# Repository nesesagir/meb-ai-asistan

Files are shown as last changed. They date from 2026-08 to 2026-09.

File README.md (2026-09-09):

# MEB AI Asistan

End-to-end voice assistant prototype for education content: ESP32 client, FastAPI backend with RAG, a completed 50×72 mm PCB design, a 3D-printed enclosure, and a small web dashboard.

## Architecture

```
ESP32 (mic / speaker / UI)
        │ WebSocket
        ▼
FastAPI  →  STT → RAG (Qdrant) → LLM → TTS
        │
        ▼
Web dashboard (parent / teacher)
```

| Path | Role |
|---|---|
| `01-Cihaz-Yazilimi/` | ESP32 firmware |
| `02-Backend-Sunucu/` | API, voice pipeline, dashboard host |
| `03-Veri-RAG/dokumantasyon/` | How book data is prepared |
| `04-Dashboard-Web/` | Dashboard UI |
| `05-Donanim-PCB/` | 50×72 mm PCB (schematic and layout complete) |
| `06-Kasa-3D/` | Print-ready case (STL) and Blender source |

Large book/vector dumps are not in this repo; rebuild them locally when needed.

There is no hosted demo. Run the backend locally and flash the ESP32 to try the assistant.

## On the device

ESP32 client on hardware (prototype photos):

| Ready | Type a question | Grade |
| --- | --- | --- |
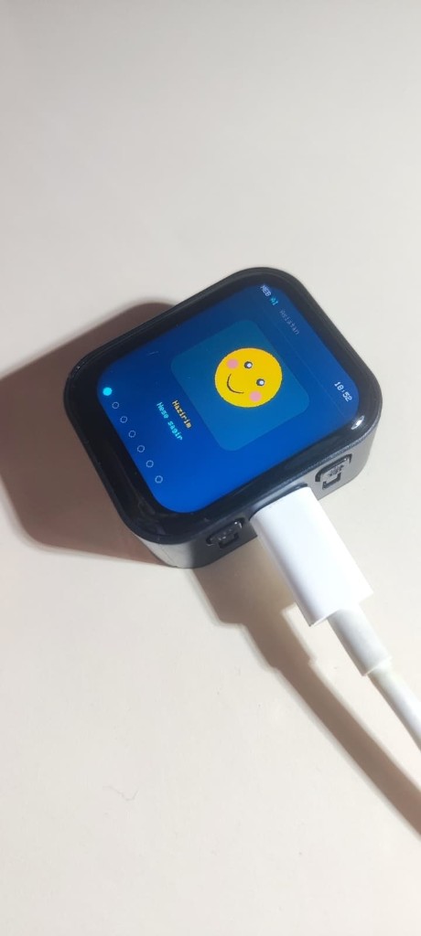
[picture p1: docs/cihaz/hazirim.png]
Hazırım
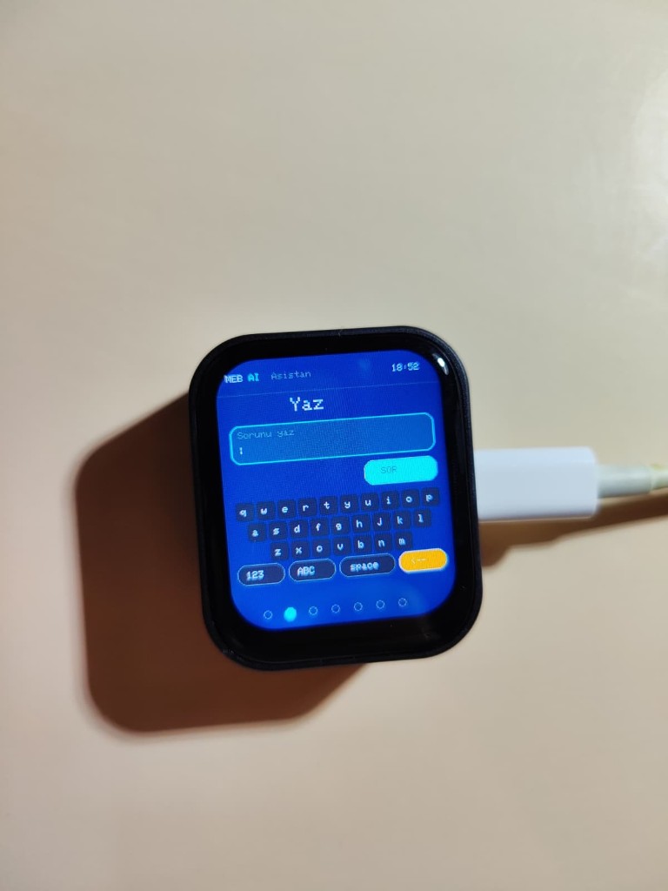
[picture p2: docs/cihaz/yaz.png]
Yaz
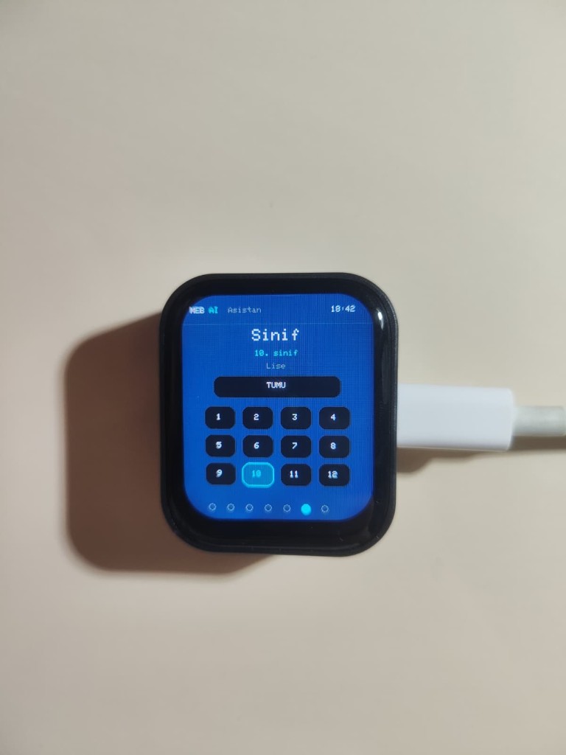
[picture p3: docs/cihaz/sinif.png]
Sınıf
|  |  |  |

## Setup

### Backend

1. Copy `02-Backend-Sunucu/.env.example` → `.env` and set `GROQ_API_KEY`
2. Start Qdrant on `localhost:6333`
3. Create a venv, install `requirements.txt`
4. Run:

```bash
uvicorn main:app --host 0.0.0.0 --port 8001
```

Dashboard: `http://127.0.0.1:8001/dashboard/`

### Device

1. Copy `01-Cihaz-Yazilimi/esp32-asistan/wifi_local.h.example` → `wifi_local.h`
2. Fill Wi-Fi SSID/password and backend host IP
3. Flash `esp32-asistan` with Arduino IDE

`wifi_local.h` and `.env` are gitignored.

## Hardware

Custom 50×72 mm board: schematic, layout, and Gerber are complete.

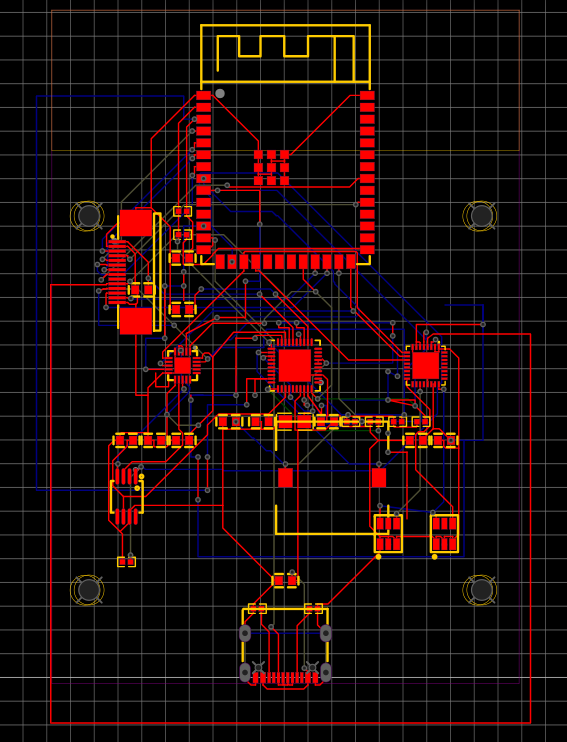
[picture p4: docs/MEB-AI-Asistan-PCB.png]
PCB layout


- PCB **50 × 72 × 1.6 mm**, 4 layers, Type-C on the bottom edge (center)
- ESP32-S3-WROOM-1 on the **top / screen** side; antenna keep-out is the top 15 mm
- M2 holes Ø2.2 mm at (4,10) (46,10) (4,50) (46,50) from the Type-C bottom-left origin
- Case target **58 × 90 × 20 mm**; battery **35 × 34 × 6.5 mm** on the back, between the four bosses
- Mechanical check file: `05-Donanim-PCB/easyeda/MEB-AI-Asistan-PCB-mekanik.scad`
- Schematic sheets: `05-Donanim-PCB/easyeda/01-*.json` … `09-PCB-TAM.json` (open in EasyEDA Standard)
- Gerber: `05-Donanim-PCB/Uretim.zip`
- Case (print-ready): `06-Kasa-3D/on_govde.stl`, `06-Kasa-3D/arka_kapak.stl`
- Case source: `06-Kasa-3D/final.blend`
- Case envelope: `06-Kasa-3D/kasa.scad`

## Stack

Python · FastAPI · Qdrant · Groq · Edge TTS · ESP32 · EasyEDA · OpenSCAD · Blender · JavaScript

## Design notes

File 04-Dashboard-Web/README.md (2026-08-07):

# Dashboard

Served by the backend at `/dashboard/`.

Demo logins (local only):

- `veli` / `veli1`
- `ogretmen` / `ogretmen1`

The device talks to the backend over WebSocket; the panel reads status and history through the HTTP API.

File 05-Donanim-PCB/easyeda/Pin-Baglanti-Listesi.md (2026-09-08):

# Pin Baglanti Listesi

Bu liste sema cizimi icin net bazli resmi baglanti referansidir.

## Net Bazli Baglantilar

### 3V3
| Bilesen | Pin | Bu nette bagli diger pinler |
|---|---|---|
| C5 | 1 | L1.2, R1.2, R2.2, R6.2, R7.2, R8.2, U1.2, U2.14, U2.21 |
| L1 | 2 | C5.1, R1.2, R2.2, R6.2, R7.2, R8.2, U1.2, U2.14, U2.21 |
| R1 | 2 | C5.1, L1.2, R2.2, R6.2, R7.2, R8.2, U1.2, U2.14, U2.21 |
| R2 | 2 | C5.1, L1.2, R1.2, R6.2, R7.2, R8.2, U1.2, U2.14, U2.21 |
| R6 | 2 | C5.1, L1.2, R1.2, R2.2, R7.2, R8.2, U1.2, U2.14, U2.21 |
| R7 | 2 | C5.1, L1.2, R1.2, R2.2, R6.2, R8.2, U1.2, U2.14, U2.21 |
| R8 | 2 | C5.1, L1.2, R1.2, R2.2, R6.2, R7.2, U1.2, U2.14, U2.21 |
| U1 | 2 | C5.1, L1.2, R1.2, R2.2, R6.2, R7.2, R8.2, U2.14, U2.21 |
| U2 | 14 | C5.1, L1.2, R1.2, R2.2, R6.2, R7.2, R8.2, U1.2, U2.21 |
| U2 | 21 | C5.1, L1.2, R1.2, R2.2, R6.2, R7.2, R8.2, U1.2, U2.14 |

### AEC_N
| Bilesen | Pin | Bu nette bagli diger pinler |
|---|---|---|
| U3 | 32 | - |

### AEC_P
| Bilesen | Pin | Bu nette bagli diger pinler |
|---|---|---|
| U3 | 31 | - |

### AUD_3V3
| Bilesen | Pin | Bu nette bagli diger pinler |
|---|---|---|
| C7 | 1 | C12.1, U2.18, U4.11, U4.20, U4.3, U4.4 |
| C12 | 1 | C7.1, U2.18, U4.11, U4.20, U4.3, U4.4 |
| U2 | 18 | C7.1, C12.1, U4.11, U4.20, U4.3, U4.4 |
| U4 | 11 | C7.1, C12.1, U2.18, U4.20, U4.3, U4.4 |
| U4 | 20 | C7.1, C12.1, U2.18, U4.11, U4.3, U4.4 |
| U4 | 3 | C7.1, C12.1, U2.18, U4.11, U4.20, U4.4 |
| U4 | 4 | C7.1, C12.1, U2.18, U4.11, U4.20, U4.3 |

### AXP_IRQ
| Bilesen | Pin | Bu nette bagli diger pinler |
|---|---|---|
| R8 | 1 | U1.25, U2.38 |
| U1 | 25 | R8.1, U2.38 |
| U2 | 38 | R8.1, U1.25 |

### AXP_VMID
| Bilesen | Pin | Bu nette bagli diger pinler |
|---|---|---|
| U2 | 36 | - |

### AXP_VREF
| Bilesen | Pin | Bu nette bagli diger pinler |
|---|---|---|
| U2 | 2 | - |

### BAT_NTC
| Bilesen | Pin | Bu nette bagli diger pinler |
|---|---|---|
| R9 | 1 | U2.31 |
| U2 | 31 | R9.1 |

### BOOT
| Bilesen | Pin | Bu nette bagli diger pinler |
|---|---|---|
| R1 | 1 | U1.27 |
| U1 | 27 | R1.1 |

### CC1
| Bilesen | Pin | Bu nette bagli diger pinler |
|---|---|---|
| J1 | A5 | R4.2 |
| R4 | 2 | J1.A5 |

### CC2
| Bilesen | Pin | Bu nette bagli diger pinler |
|---|---|---|
| J1 | B5 | R5.1 |
| R5 | 1 | J1.B5 |

### CTP_3V3
| Bilesen | Pin | Bu nette bagli diger pinler |
|---|---|---|
| C10 | 1 | U2.12 |
| U2 | 12 | C10.1 |

### CTP_INT
| Bilesen | Pin | Bu nette bagli diger pinler |
|---|---|---|
| J2 | 13 | U1.23 |
| U1 | 23 | J2.13 |

### CTP_RST
| Bilesen | Pin | Bu nette bagli diger pinler |
|---|---|---|
| J2 | 12 | U1.24 |
| U1 | 24 | J2.12 |

### DAC_N
| Bilesen | Pin | Bu nette bagli diger pinler |
|---|---|---|
| U4 | 13 | U5.4 |
| U5 | 4 | U4.13 |

### DAC_P
| Bilesen | Pin | Bu nette bagli diger pinler |
|---|---|---|
| U4 | 12 | U5.3 |
| U5 | 3 | U4.12 |

### DCDC1_LX
| Bilesen | Pin | Bu nette bagli diger pinler |
|---|---|---|
| L1 | 1 | U2.22 |
| U2 | 22 | L1.1 |

### ES7210_REFP12
| Bilesen | Pin | Bu nette bagli diger pinler |
|---|---|---|
| U3 | 17 | - |

### ES7210_REFQ12
| Bilesen | Pin | Bu nette bagli diger pinler |
|---|---|---|
| U3 | 18 | - |

### ES7210_REFQM
| Bilesen | Pin | Bu nette bagli diger pinler |
|---|---|---|
| U3 | 25 | - |

### ES8311_ADCVREF
| Bilesen | Pin | Bu nette bagli diger pinler |
|---|---|---|
| U4 | 15 | - |

### ES8311_DACVREF
| Bilesen | Pin | Bu nette bagli diger pinler |
|---|---|---|
| U4 | 14 | - |

### ES8311_VMID
| Bilesen | Pin | Bu nette bagli diger pinler |
|---|---|---|
| U4 | 16 | - |

### ESP_EN
| Bilesen | Pin | Bu nette bagli diger pinler |
|---|---|---|
| C1 | 1 | R2.1, U1.3, U2.29 |
| R2 | 1 | C1.1, U1.3, U2.29 |
| U1 | 3 | C1.1, R2.1, U2.29 |
| U2 | 29 | C1.1, R2.1, U1.3 |

### GND
| Bilesen | Pin | Bu nette bagli diger pinler |
|---|---|---|
| C1 | 2 | C2.2, C3.2, C4.2, C5.2, C6.2, C7.2, C8.2, C9.2, C10.2, C11.2, C12.2, C13.2, J1.13, J1.14, J1.A1B12, J1.B1A12, J2.14, J2.15, J2.16, J2.2, MK1.1, MK1.2, MK1.3, MK2.1, MK2.2, MK2.3, R3.2, R4.1, R5.2, R9.2, U1.1, U1.40, U1.41, U2.3, U2.41, U3.1, U3.2, U3.21, U3.33, U3.8, U4.10, U4.21, U4.5, U5.7 |
| C2 | 2 | C1.2, C3.2, C4.2, C5.2, C6.2, C7.2, C8.2, C9.2, C10.2, C11.2, C12.2, C13.2, J1.13, J1.14, J1.A1B12, J1.B1A12, J2.14, J2.15, J2.16, J2.2, MK1.1, MK1.2, MK1.3, MK2.1, MK2.2, MK2.3, R3.2, R4.1, R5.2, R9.2, U1.1, U1.40, U1.41, U2.3, U2.41, U3.1, U3.2, U3.21, U3.33, U3.8, U4.10, U4.21, U4.5, U5.7 |
| C3 | 2 | C1.2, C2.2, C4.2, C5.2, C6.2, C7.2, C8.2, C9.2, C10.2, C11.2, C12.2, C13.2, J1.13, J1.14, J1.A1B12, J1.B1A12, J2.14, J2.15, J2.16, J2.2, MK1.1, MK1.2, MK1.3, MK2.1, MK2.2, MK2.3, R3.2, R4.1, R5.2, R9.2, U1.1, U1.40, U1.41, U2.3, U2.41, U3.1, U3.2, U3.21, U3.33, U3.8, U4.10, U4.21, U4.5, U5.7 |
| C4 | 2 | C1.2, C2.2, C3.2, C5.2, C6.2, C7.2, C8.2, C9.2, C10.2, C11.2, C12.2, C13.2, J1.13, J1.14, J1.A1B12, J1.B1A12, J2.14, J2.15, J2.16, J2.2, MK1.1, MK1.2, MK1.3, MK2.1, MK2.2, MK2.3, R3.2, R4.1, R5.2, R9.2, U1.1, U1.40, U1.41, U2.3, U2.41, U3.1, U3.2, U3.21, U3.33, U3.8, U4.10, U4.21, U4.5, U5.7 |
| C5 | 2 | C1.2, C2.2, C3.2, C4.2, C6.2, C7.2, C8.2, C9.2, C10.2, C11.2, C12.2, C13.2, J1.13, J1.14, J1.A1B12, J1.B1A12, J2.14, J2.15, J2.16, J2.2, MK1.1, MK1.2, MK1.3, MK2.1, MK2.2, MK2.3, R3.2, R4.1, R5.2, R9.2, U1.1, U1.40, U1.41, U2.3, U2.41, U3.1, U3.2, U3.21, U3.33, U3.8, U4.10, U4.21, U4.5, U5.7 |
| C6 | 2 | C1.2, C2.2, C3.2, C4.2, C5.2, C7.2, C8.2, C9.2, C10.2, C11.2, C12.2, C13.2, J1.13, J1.14, J1.A1B12, J1.B1A12, J2.14, J2.15, J2.16, J2.2, MK1.1, MK1.2, MK1.3, MK2.1, MK2.2, MK2.3, R3.2, R4.1, R5.2, R9.2, U1.1, U1.40, U1.41, U2.3, U2.41, U3.1, U3.2, U3.21, U3.33, U3.8, U4.10, U4.21, U4.5, U5.7 |
| C7 | 2 | C1.2, C2.2, C3.2, C4.2, C5.2, C6.2, C8.2, C9.2, C10.2, C11.2, C12.2, C13.2, J1.13, J1.14, J1.A1B12, J1.B1A12, J2.14, J2.15, J2.16, J2.2, MK1.1, MK1.2, MK1.3, MK2.1, MK2.2, MK2.3, R3.2, R4.1, R5.2, R9.2, U1.1, U1.40, U1.41, U2.3, U2.41, U3.1, U3.2, U3.21, U3.33, U3.8, U4.10, U4.21, U4.5, U5.7 |
| C8 | 2 | C1.2, C2.2, C3.2, C4.2, C5.2, C6.2, C7.2, C9.2, C10.2, C11.2, C12.2, C13.2, J1.13, J1.14, J1.A1B12, J1.B1A12, J2.14, J2.15, J2.16, J2.2, MK1.1, MK1.2, MK1.3, MK2.1, MK2.2, MK2.3, R3.2, R4.1, R5.2, R9.2, U1.1, U1.40, U1.41, U2.3, U2.41, U3.1, U3.2, U3.21, U3.33, U3.8, U4.10, U4.21, U4.5, U5.7 |
| C9 | 2 | C1.2, C2.2, C3.2, C4.2, C5.2, C6.2, C7.2, C8.2, C10.2, C11.2, C12.2, C13.2, J1.13, J1.14, J1.A1B12, J1.B1A12, J2.14, J2.15, J2.16, J2.2, MK1.1, MK1.2, MK1.3, MK2.1, MK2.2, MK2.3, R3.2, R4.1, R5.2, R9.2, U1.1, U1.40, U1.41, U2.3, U2.41, U3.1, U3.2, U3.21, U3.33, U3.8, U4.10, U4.21, U4.5, U5.7 |
| C10 | 2 | C1.2, C2.2, C3.2, C4.2, C5.2, C6.2, C7.2, C8.2, C9.2, C11.2, C12.2, C13.2, J1.13, J1.14, J1.A1B12, J1.B1A12, J2.14, J2.15, J2.16, J2.2, MK1.1, MK1.2, MK1.3, MK2.1, MK2.2, MK2.3, R3.2, R4.1, R5.2, R9.2, U1.1, U1.40, U1.41, U2.3, U2.41, U3.1, U3.2, U3.21, U3.33, U3.8, U4.10, U4.21, U4.5, U5.7 |
| C11 | 2 | C1.2, C2.2, C3.2, C4.2, C5.2, C6.2, C7.2, C8.2, C9.2, C10.2, C12.2, C13.2, J1.13, J1.14, J1.A1B12, J1.B1A12, J2.14, J2.15, J2.16, J2.2, MK1.1, MK1.2, MK1.3, MK2.1, MK2.2, MK2.3, R3.2, R4.1, R5.2, R9.2, U1.1, U1.40, U1.41, U2.3, U2.41, U3.1, U3.2, U3.21, U3.33, U3.8, U4.10, U4.21, U4.5, U5.7 |
| C12 | 2 | C1.2, C2.2, C3.2, C4.2, C5.2, C6.2, C7.2, C8.2, C9.2, C10.2, C11.2, C13.2, J1.13, J1.14, J1.A1B12, J1.B1A12, J2.14, J2.15, J2.16, J2.2, MK1.1, MK1.2, MK1.3, MK2.1, MK2.2, MK2.3, R3.2, R4.1, R5.2, R9.2, U1.1, U1.40, U1.41, U2.3, U2.41, U3.1, U3.2, U3.21, U3.33, U3.8, U4.10, U4.21, U4.5, U5.7 |
| C13 | 2 | C1.2, C2.2, C3.2, C4.2, C5.2, C6.2, C7.2, C8.2, C9.2, C10.2, C11.2, C12.2, J1.13, J1.14, J1.A1B12, J1.B1A12, J2.14, J2.15, J2.16, J2.2, MK1.1, MK1.2, MK1.3, MK2.1, MK2.2, MK2.3, R3.2, R4.1, R5.2, R9.2, U1.1, U1.40, U1.41, U2.3, U2.41, U3.1, U3.2, U3.21, U3.33, U3.8, U4.10, U4.21, U4.5, U5.7 |
| J1 | 13 | C1.2, C2.2, C3.2, C4.2, C5.2, C6.2, C7.2, C8.2, C9.2, C10.2, C11.2, C12.2, C13.2, J1.14, J1.A1B12, J1.B1A12, J2.14, J2.15, J2.16, J2.2, MK1.1, MK1.2, MK1.3, MK2.1, MK2.2, MK2.3, R3.2, R4.1, R5.2, R9.2, U1.1, U1.40, U1.41, U2.3, U2.41, U3.1, U3.2, U3.21, U3.33, U3.8, U4.10, U4.21, U4.5, U5.7 |
| J1 | 14 | C1.2, C2.2, C3.2, C4.2, C5.2, C6.2, C7.2, C8.2, C9.2, C10.2, C11.2, C12.2, C13.2, J1.13, J1.A1B12, J1.B1A12, J2.14, J2.15, J2.16, J2.2, MK1.1, MK1.2, MK1.3, MK2.1, MK2.2, MK2.3, R3.2, R4.1, R5.2, R9.2, U1.1, U1.40, U1.41, U2.3, U2.41, U3.1, U3.2, U3.21, U3.33, U3.8, U4.10, U4.21, U4.5, U5.7 |
| J1 | A1B12 | C1.2, C2.2, C3.2, C4.2, C5.2, C6.2, C7.2, C8.2, C9.2, C10.2, C11.2, C12.2, C13.2, J1.13, J1.14, J1.B1A12, J2.14, J2.15, J2.16, J2.2, MK1.1, MK1.2, MK1.3, MK2.1, MK2.2, MK2.3, R3.2, R4.1, R5.2, R9.2, U1.1, U1.40, U1.41, U2.3, U2.41, U3.1, U3.2, U3.21, U3.33, U3.8, U4.10, U4.21, U4.5, U5.7 |
| J1 | B1A12 | C1.2, C2.2, C3.2, C4.2, C5.2, C6.2, C7.2, C8.2, C9.2, C10.2, C11.2, C12.2, C13.2, J1.13, J1.14, J1.A1B12, J2.14, J2.15, J2.16, J2.2, MK1.1, MK1.2, MK1.3, MK2.1, MK2.2, MK2.3, R3.2, R4.1, R5.2, R9.2, U1.1, U1.40, U1.41, U2.3, U2.41, U3.1, U3.2, U3.21, U3.33, U3.8, U4.10, U4.21, U4.5, U5.7 |
| J2 | 14 | C1.2, C2.2, C3.2, C4.2, C5.2, C6.2, C7.2, C8.2, C9.2, C10.2, C11.2, C12.2, C13.2, J1.13, J1.14, J1.A1B12, J1.B1A12, J2.15, J2.16, J2.2, MK1.1, MK1.2, MK1.3, MK2.1, MK2.2, MK2.3, R3.2, R4.1, R5.2, R9.2, U1.1, U1.40, U1.41, U2.3, U2.41, U3.1, U3.2, U3.21, U3.33, U3.8, U4.10, U4.21, U4.5, U5.7 |
| J2 | 15 | C1.2, C2.2, C3.2, C4.2, C5.2, C6.2, C7.2, C8.2, C9.2, C10.2, C11.2, C12.2, C13.2, J1.13, J1.14, J1.A1B12, J1.B1A12, J2.14, J2.16, J2.2, MK1.1, MK1.2, MK1.3, MK2.1, MK2.2, MK2.3, R3.2, R4.1, R5.2, R9.2, U1.1, U1.40, U1.41, U2.3, U2.41, U3.1, U3.2, U3.21, U3.33, U3.8, U4.10, U4.21, U4.5, U5.7 |
| J2 | 16 | C1.2, C2.2, C3.2, C4.2, C5.2, C6.2, C7.2, C8.2, C9.2, C10.2, C11.2, C12.2, C13.2, J1.13, J1.14, J1.A1B12, J1.B1A12, J2.14, J2.15, J2.2, MK1.1, MK1.2, MK1.3, MK2.1, MK2.2, MK2.3, R3.2, R4.1, R5.2, R9.2, U1.1, U1.40, U1.41, U2.3, U2.41, U3.1, U3.2, U3.21, U3.33, U3.8, U4.10, U4.21, U4.5, U5.7 |
| J2 | 2 | C1.2, C2.2, C3.2, C4.2, C5.2, C6.2, C7.2, C8.2, C9.2, C10.2, C11.2, C12.2, C13.2, J1.13, J1.14, J1.A1B12, J1.B1A12, J2.14, J2.15, J2.16, MK1.1, MK1.2, MK1.3, MK2.1, MK2.2, MK2.3, R3.2, R4.1, R5.2, R9.2, U1.1, U1.40, U1.41, U2.3, U2.41, U3.1, U3.2, U3.21, U3.33, U3.8, U4.10, U4.21, U4.5, U5.7 |
| MK1 | 1 | C1.2, C2.2, C3.2, C4.2, C5.2, C6.2, C7.2, C8.2, C9.2, C10.2, C11.2, C12.2, C13.2, J1.13, J1.14, J1.A1B12, J1.B1A12, J2.14, J2.15, J2.16, J2.2, MK1.2, MK1.3, MK2.1, MK2.2, MK2.3, R3.2, R4.1, R5.2, R9.2, U1.1, U1.40, U1.41, U2.3, U2.41, U3.1, U3.2, U3.21, U3.33, U3.8, U4.10, U4.21, U4.5, U5.7 |
| MK1 | 2 | C1.2, C2.2, C3.2, C4.2, C5.2, C6.2, C7.2, C8.2, C9.2, C10.2, C11.2, C12.2, C13.2, J1.13, J1.14, J1.A1B12, J1.B1A12, J2.14, J2.15, J2.16, J2.2, MK1.1, MK1.3, MK2.1, MK2.2, MK2.3, R3.2, R4.1, R5.2, R9.2, U1.1, U1.40, U1.41, U2.3, U2.41, U3.1, U3.2, U3.21, U3.33, U3.8, U4.10, U4.21, U4.5, U5.7 |
| MK1 | 3 | C1.2, C2.2, C3.2, C4.2, C5.2, C6.2, C7.2, C8.2, C9.2, C10.2, C11.2, C12.2, C13.2, J1.13, J1.14, J1.A1B12, J1.B1A12, J2.14, J2.15, J2.16, J2.2, MK1.1, MK1.2, MK2.1, MK2.2, MK2.3, R3.2, R4.1, R5.2, R9.2, U1.1, U1.40, U1.41, U2.3, U2.41, U3.1, U3.2, U3.21, U3.33, U3.8, U4.10, U4.21, U4.5, U5.7 |
| MK2 | 1 | C1.2, C2.2, C3.2, C4.2, C5.2, C6.2, C7.2, C8.2, C9.2, C10.2, C11.2, C12.2, C13.2, J1.13, J1.14, J1.A1B12, J1.B1A12, J2.14, J2.15, J2.16, J2.2, MK1.1, MK1.2, MK1.3, MK2.2, MK2.3, R3.2, R4.1, R5.2, R9.2, U1.1, U1.40, U1.41, U2.3, U2.41, U3.1, U3.2, U3.21, U3.33, U3.8, U4.10, U4.21, U4.5, U5.7 |
| MK2 | 2 | C1.2, C2.2, C3.2, C4.2, C5.2, C6.2, C7.2, C8.2, C9.2, C10.2, C11.2, C12.2, C13.2, J1.13, J1.14, J1.A1B12, J1.B1A12, J2.14, J2.15, J2.16, J2.2, MK1.1, MK1.2, MK1.3, MK2.1, MK2.3, R3.2, R4.1, R5.2, R9.2, U1.1, U1.40, U1.41, U2.3, U2.41, U3.1, U3.2, U3.21, U3.33, U3.8, U4.10, U4.21, U4.5, U5.7 |
| MK2 | 3 | C1.2, C2.2, C3.2, C4.2, C5.2, C6.2, C7.2, C8.2, C9.2, C10.2, C11.2, C12.2, C13.2, J1.13, J1.14, J1.A1B12, J1.B1A12, J2.14, J2.15, J2.16, J2.2, MK1.1, MK1.2, MK1.3, MK2.1, MK2.2, R3.2, R4.1, R5.2, R9.2, U1.1, U1.40, U1.41, U2.3, U2.41, U3.1, U3.2, U3.21, U3.33, U3.8, U4.10, U4.21, U4.5, U5.7 |
| R3 | 2 | C1.2, C2.2, C3.2, C4.2, C5.2, C6.2, C7.2, C8.2, C9.2, C10.2, C11.2, C12.2, C13.2, J1.13, J1.14, J1.A1B12, J1.B1A12, J2.14, J2.15, J2.16, J2.2, MK1.1, MK1.2, MK1.3, MK2.1, MK2.2, MK2.3, R4.1, R5.2, R9.2, U1.1, U1.40, U1.41, U2.3, U2.41, U3.1, U3.2, U3.21, U3.33, U3.8, U4.10, U4.21, U4.5, U5.7 |
| R4 | 1 | C1.2, C2.2, C3.2, C4.2, C5.2, C6.2, C7.2, C8.2, C9.2, C10.2, C11.2, C12.2, C13.2, J1.13, J1.14, J1.A1B12, J1.B1A12, J2.14, J2.15, J2.16, J2.2, MK1.1, MK1.2, MK1.3, MK2.1, MK2.2, MK2.3, R3.2, R5.2, R9.2, U1.1, U1.40, U1.41, U2.3, U2.41, U3.1, U3.2, U3.21, U3.33, U3.8, U4.10, U4.21, U4.5, U5.7 |
| R5 | 2 | C1.2, C2.2, C3.2, C4.2, C5.2, C6.2, C7.2, C8.2, C9.2, C10.2, C11.2, C12.2, C13.2, J1.13, J1.14, J1.A1B12, J1.B1A12, J2.14, J2.15, J2.16, J2.2, MK1.1, MK1.2, MK1.3, MK2.1, MK2.2, MK2.3, R3.2, R4.1, R9.2, U1.1, U1.40, U1.41, U2.3, U2.41, U3.1, U3.2, U3.21, U3.33, U3.8, U4.10, U4.21, U4.5, U5.7 |
| R9 | 2 | C1.2, C2.2, C3.2, C4.2, C5.2, C6.2, C7.2, C8.2, C9.2, C10.2, C11.2, C12.2, C13.2, J1.13, J1.14, J1.A1B12, J1.B1A12, J2.14, J2.15, J2.16, J2.2, MK1.1, MK1.2, MK1.3, MK2.1, MK2.2, MK2.3, R3.2, R4.1, R5.2, U1.1, U1.40, U1.41, U2.3, U2.41, U3.1, U3.2, U3.21, U3.33, U3.8, U4.10, U4.21, U4.5, U5.7 |
| U1 | 1 | C1.2, C2.2, C3.2, C4.2, C5.2, C6.2, C7.2, C8.2, C9.2, C10.2, C11.2, C12.2, C13.2, J1.13, J1.14, J1.A1B12, J1.B1A12, J2.14, J2.15, J2.16, J2.2, MK1.1, MK1.2, MK1.3, MK2.1, MK2.2, MK2.3, R3.2, R4.1, R5.2, R9.2, U1.40, U1.41, U2.3, U2.41, U3.1, U3.2, U3.21, U3.33, U3.8, U4.10, U4.21, U4.5, U5.7 |
| U1 | 40 | C1.2, C2.2, C3.2, C4.2, C5.2, C6.2, C7.2, C8.2, C9.2, C10.2, C11.2, C12.2, C13.2, J1.13, J1.14, J1.A1B12, J1.B1A12, J2.14, J2.15, J2.16, J2.2, MK1.1, MK1.2, MK1.3, MK2.1, MK2.2, MK2.3, R3.2, R4.1, R5.2, R9.2, U1.1, U1.41, U2.3, U2.41, U3.1, U3.2, U3.21, U3.33, U3.8, U4.10, U4.21, U4.5, U5.7 |
| U1 | 41 | C1.2, C2.2, C3.2, C4.2, C5.2, C6.2, C7.2, C8.2, C9.2, C10.2, C11.2, C12.2, C13.2, J1.13, J1.14, J1.A1B12, J1.B1A12, J2.14, J2.15, J2.16, J2.2, MK1.1, MK1.2, MK1.3, MK2.1, MK2.2, MK2.3, R3.2, R4.1, R5.2, R9.2, U1.1, U1.40, U2.3, U2.41, U3.1, U3.2, U3.21, U3.33, U3.8, U4.10, U4.21, U4.5, U5.7 |
| U2 | 3 | C1.2, C2.2, C3.2, C4.2, C5.2, C6.2, C7.2, C8.2, C9.2, C10.2, C11.2, C12.2, C13.2, J1.13, J1.14, J1.A1B12, J1.B1A12, J2.14, J2.15, J2.16, J2.2, MK1.1, MK1.2, MK1.3, MK2.1, MK2.2, MK2.3, R3.2, R4.1, R5.2, R9.2, U1.1, U1.40, U1.41, U2.41, U3.1, U3.2, U3.21, U3.33, U3.8, U4.10, U4.21, U4.5, U5.7 |
| U2 | 41 | C1.2, C2.2, C3.2, C4.2, C5.2, C6.2, C7.2, C8.2, C9.2, C10.2, C11.2, C12.2, C13.2, J1.13, J1.14, J1.A1B12, J1.B1A12, J2.14, J2.15, J2.16, J2.2, MK1.1, MK1.2, MK1.3, MK2.1, MK2.2, MK2.3, R3.2, R4.1, R5.2, R9.2, U1.1, U1.40, U1.41, U2.3, U3.1, U3.2, U3.21, U3.33, U3.8, U4.10, U4.21, U4.5, U5.7 |
| U3 | 1 | C1.2, C2.2, C3.2, C4.2, C5.2, C6.2, C7.2, C8.2, C9.2, C10.2, C11.2, C12.2, C13.2, J1.13, J1.14, J1.A1B12, J1.B1A12, J2.14, J2.15, J2.16, J2.2, MK1.1, MK1.2, MK1.3, MK2.1, MK2.2, MK2.3, R3.2, R4.1, R5.2, R9.2, U1.1, U1.40, U1.41, U2.3, U2.41, U3.2, U3.21, U3.33, U3.8, U4.10, U4.21, U4.5, U5.7 |
| U3 | 2 | C1.2, C2.2, C3.2, C4.2, C5.2, C6.2, C7.2, C8.2, C9.2, C10.2, C11.2, C12.2, C13.2, J1.13, J1.14, J1.A1B12, J1.B1A12, J2.14, J2.15, J2.16, J2.2, MK1.1, MK1.2, MK1.3, MK2.1, MK2.2, MK2.3, R3.2, R4.1, R5.2, R9.2, U1.1, U1.40, U1.41, U2.3, U2.41, U3.1, U3.21, U3.33, U3.8, U4.10, U4.21, U4.5, U5.7 |
| U3 | 21 | C1.2, C2.2, C3.2, C4.2, C5.2, C6.2, C7.2, C8.2, C9.2, C10.2, C11.2, C12.2, C13.2, J1.13, J1.14, J1.A1B12, J1.B1A12, J2.14, J2.15, J2.16, J2.2, MK1.1, MK1.2, MK1.3, MK2.1, MK2.2, MK2.3, R3.2, R4.1, R5.2, R9.2, U1.1, U1.40, U1.41, U2.3, U2.41, U3.1, U3.2, U3.33, U3.8, U4.10, U4.21, U4.5, U5.7 |
| U3 | 33 | C1.2, C2.2, C3.2, C4.2, C5.2, C6.2, C7.2, C8.2, C9.2, C10.2, C11.2, C12.2, C13.2, J1.13, J1.14, J1.A1B12, J1.B1A12, J2.14, J2.15, J2.16, J2.2, MK1.1, MK1.2, MK1.3, MK2.1, MK2.2, MK2.3, R3.2, R4.1, R5.2, R9.2, U1.1, U1.40, U1.41, U2.3, U2.41, U3.1, U3.2, U3.21, U3.8, U4.10, U4.21, U4.5, U5.7 |
| U3 | 8 | C1.2, C2.2, C3.2, C4.2, C5.2, C6.2, C7.2, C8.2, C9.2, C10.2, C11.2, C12.2, C13.2, J1.13, J1.14, J1.A1B12, J1.B1A12, J2.14, J2.15, J2.16, J2.2, MK1.1, MK1.2, MK1.3, MK2.1, MK2.2, MK2.3, R3.2, R4.1, R5.2, R9.2, U1.1, U1.40, U1.41, U2.3, U2.41, U3.1, U3.2, U3.21, U3.33, U4.10, U4.21, U4.5, U5.7 |
| U4 | 10 | C1.2, C2.2, C3.2, C4.2, C5.2, C6.2, C7.2, C8.2, C9.2, C10.2, C11.2, C12.2, C13.2, J1.13, J1.14, J1.A1B12, J1.B1A12, J2.14, J2.15, J2.16, J2.2, MK1.1, MK1.2, MK1.3, MK2.1, MK2.2, MK2.3, R3.2, R4.1, R5.2, R9.2, U1.1, U1.40, U1.41, U2.3, U2.41, U3.1, U3.2, U3.21, U3.33, U3.8, U4.21, U4.5, U5.7 |
| U4 | 21 | C1.2, C2.2, C3.2, C4.2, C5.2, C6.2, C7.2, C8.2, C9.2, C10.2, C11.2, C12.2, C13.2, J1.13, J1.14, J1.A1B12, J1.B1A12, J2.14, J2.15, J2.16, J2.2, MK1.1, MK1.2, MK1.3, MK2.1, MK2.2, MK2.3, R3.2, R4.1, R5.2, R9.2, U1.1, U1.40, U1.41, U2.3, U2.41, U3.1, U3.2, U3.21, U3.33, U3.8, U4.10, U4.5, U5.7 |
| U4 | 5 | C1.2, C2.2, C3.2, C4.2, C5.2, C6.2, C7.2, C8.2, C9.2, C10.2, C11.2, C12.2, C13.2, J1.13, J1.14, J1.A1B12, J1.B1A12, J2.14, J2.15, J2.16, J2.2, MK1.1, MK1.2, MK1.3, MK2.1, MK2.2, MK2.3, R3.2, R4.1, R5.2, R9.2, U1.1, U1.40, U1.41, U2.3, U2.41, U3.1, U3.2, U3.21, U3.33, U3.8, U4.10, U4.21, U5.7 |
| U5 | 7 | C1.2, C2.2, C3.2, C4.2, C5.2, C6.2, C7.2, C8.2, C9.2, C10.2, C11.2, C12.2, C13.2, J1.13, J1.14, J1.A1B12, J1.B1A12, J2.14, J2.15, J2.16, J2.2, MK1.1, MK1.2, MK1.3, MK2.1, MK2.2, MK2.3, R3.2, R4.1, R5.2, R9.2, U1.1, U1.40, U1.41, U2.3, U2.41, U3.1, U3.2, U3.21, U3.33, U3.8, U4.10, U4.21, U4.5 |

### I2C_SCL
| Bilesen | Pin | Bu nette bagli diger pinler |
|---|---|---|
| J2 | 10 | R7.1, U1.22, U2.40, U3.4, U4.1 |
| R7 | 1 | J2.10, U1.22, U2.40, U3.4, U4.1 |
| U1 | 22 | J2.10, R7.1, U2.40, U3.4, U4.1 |
| U2 | 40 | J2.10, R7.1, U1.22, U3.4, U4.1 |
| U3 | 4 | J2.10, R7.1, U1.22, U2.40, U4.1 |
| U4 | 1 | J2.10, R7.1, U1.22, U2.40, U3.4 |

### I2C_SDA
| Bilesen | Pin | Bu nette bagli diger pinler |
|---|---|---|
| J2 | 11 | R6.1, U1.8, U2.39, U3.3, U4.19 |
| R6 | 1 | J2.11, U1.8, U2.39, U3.3, U4.19 |
| U1 | 8 | J2.11, R6.1, U2.39, U3.3, U4.19 |
| U2 | 39 | J2.11, R6.1, U1.8, U3.3, U4.19 |
| U3 | 3 | J2.11, R6.1, U1.8, U2.39, U4.19 |
| U4 | 19 | J2.11, R6.1, U1.8, U2.39, U3.3 |

### I2S_BCLK
| Bilesen | Pin | Bu nette bagli diger pinler |
|---|---|---|
| U1 | 17 | U3.9, U4.6 |
| U3 | 9 | U1.17, U4.6 |
| U4 | 6 | U1.17, U3.9 |

### I2S_DIN
| Bilesen | Pin | Bu nette bagli diger pinler |
|---|---|---|
| U1 | 18 | U3.11 |
| U3 | 11 | U1.18 |

### I2S_DOUT
| Bilesen | Pin | Bu nette bagli diger pinler |
|---|---|---|
| U1 | 12 | U4.9 |
| U4 | 9 | U1.12 |

### I2S_LRCK
| Bilesen | Pin | Bu nette bagli diger pinler |
|---|---|---|
| U1 | 26 | U3.10, U4.8 |
| U3 | 10 | U1.26, U4.8 |
| U4 | 8 | U1.26, U3.10 |

### I2S_MCLK
| Bilesen | Pin | Bu nette bagli diger pinler |
|---|---|---|
| U1 | 9 | U3.5, U4.2 |
| U3 | 5 | U1.9, U4.2 |
| U4 | 2 | U1.9, U3.5 |

### LCD_3V3
| Bilesen | Pin | Bu nette bagli diger pinler |
|---|---|---|
| C9 | 1 | J2.1, U2.16 |
| J2 | 1 | C9.1, U2.16 |
| U2 | 16 | C9.1, J2.1 |

### MIC1N
| Bilesen | Pin | Bu nette bagli diger pinler |
|---|---|---|
| U3 | 15 | - |

### MIC1P
| Bilesen | Pin | Bu nette bagli diger pinler |
|---|---|---|
| MK1 | 4 | U3.16 |
| U3 | 16 | MK1.4 |

### MIC2N
| Bilesen | Pin | Bu nette bagli diger pinler |
|---|---|---|
| U3 | 20 | - |

### MIC2P
| Bilesen | Pin | Bu nette bagli diger pinler |
|---|---|---|
| MK2 | 4 | U3.19 |
| U3 | 19 | MK2.4 |

### MICBIAS
| Bilesen | Pin | Bu nette bagli diger pinler |
|---|---|---|
| MK1 | 6 | MK2.6, U3.24 |
| MK2 | 6 | MK1.6, U3.24 |
| U3 | 24 | MK1.6, MK2.6 |

### MIC_3V3
| Bilesen | Pin | Bu nette bagli diger pinler |
|---|---|---|
| C8 | 1 | C11.1, U2.19, U3.22, U3.23, U3.6, U3.7 |
| C11 | 1 | C8.1, U2.19, U3.22, U3.23, U3.6, U3.7 |
| U2 | 19 | C8.1, C11.1, U3.22, U3.23, U3.6, U3.7 |
| U3 | 22 | C8.1, C11.1, U2.19, U3.23, U3.6, U3.7 |
| U3 | 23 | C8.1, C11.1, U2.19, U3.22, U3.6, U3.7 |
| U3 | 6 | C8.1, C11.1, U2.19, U3.22, U3.23, U3.7 |
| U3 | 7 | C8.1, C11.1, U2.19, U3.22, U3.23, U3.6 |

### NC__J1__A8
| Bilesen | Pin | Bu nette bagli diger pinler |
|---|---|---|
| J1 | A8 | - |

### NC__J1__B8
| Bilesen | Pin | Bu nette bagli diger pinler |
|---|---|---|
| J1 | B8 | - |

### NC__J2__9
| Bilesen | Pin | Bu nette bagli diger pinler |
|---|---|---|
| J2 | 9 | - |

### NC__MK1__5
| Bilesen | Pin | Bu nette bagli diger pinler |
|---|---|---|
| MK1 | 5 | - |

### NC__MK2__5
| Bilesen | Pin | Bu nette bagli diger pinler |
|---|---|---|
| MK2 | 5 | - |

### NC__U1__10
| Bilesen | Pin | Bu nette bagli diger pinler |
|---|---|---|
| U1 | 10 | - |

### NC__U1__11
| Bilesen | Pin | Bu nette bagli diger pinler |
|---|---|---|
| U1 | 11 | - |

### NC__U1__15
| Bilesen | Pin | Bu nette bagli diger pinler |
|---|---|---|
| U1 | 15 | - |

### NC__U1__19
| Bilesen | Pin | Bu nette bagli diger pinler |
|---|---|---|
| U1 | 19 | - |

### NC__U1__20
| Bilesen | Pin | Bu nette bagli diger pinler |
|---|---|---|
| U1 | 20 | - |

### NC__U1__21
| Bilesen | Pin | Bu nette bagli diger pinler |
|---|---|---|
| U1 | 21 | - |

### NC__U1__28
| Bilesen | Pin | Bu nette bagli diger pinler |
|---|---|---|
| U1 | 28 | - |

### NC__U1__29
| Bilesen | Pin | Bu nette bagli diger pinler |
|---|---|---|
| U1 | 29 | - |

### NC__U1__30
| Bilesen | Pin | Bu nette bagli diger pinler |
|---|---|---|
| U1 | 30 | - |

### NC__U1__32
| Bilesen | Pin | Bu nette bagli diger pinler |
|---|---|---|
| U1 | 32 | - |

### NC__U1__34
| Bilesen | Pin | Bu nette bagli diger pinler |
|---|---|---|
| U1 | 34 | - |

### NC__U1__35
| Bilesen | Pin | Bu nette bagli diger pinler |
|---|---|---|
| U1 | 35 | - |

### NC__U1__38
| Bilesen | Pin | Bu nette bagli diger pinler |
|---|---|---|
| U1 | 38 | - |

### NC__U1__39
| Bilesen | Pin | Bu nette bagli diger pinler |
|---|---|---|
| U1 | 39 | - |

### NC__U2__1
| Bilesen | Pin | Bu nette bagli diger pinler |
|---|---|---|
| U2 | 1 | - |

### NC__U2__10
| Bilesen | Pin | Bu nette bagli diger pinler |
|---|---|---|
| U2 | 10 | - |

### NC__U2__11
| Bilesen | Pin | Bu nette bagli diger pinler |
|---|---|---|
| U2 | 11 | - |

### NC__U2__15
| Bilesen | Pin | Bu nette bagli diger pinler |
|---|---|---|
| U2 | 15 | - |

### NC__U2__20
| Bilesen | Pin | Bu nette bagli diger pinler |
|---|---|---|
| U2 | 20 | - |

### NC__U2__25
| Bilesen | Pin | Bu nette bagli diger pinler |
|---|---|---|
| U2 | 25 | - |

### NC__U2__26
| Bilesen | Pin | Bu nette bagli diger pinler |
|---|---|---|
| U2 | 26 | - |

### NC__U2__27
| Bilesen | Pin | Bu nette bagli diger pinler |
|---|---|---|
| U2 | 27 | - |

### NC__U2__28
| Bilesen | Pin | Bu nette bagli diger pinler |
|---|---|---|
| U2 | 28 | - |

### NC__U2__32
| Bilesen | Pin | Bu nette bagli diger pinler |
|---|---|---|
| U2 | 32 | - |

### NC__U2__35
| Bilesen | Pin | Bu nette bagli diger pinler |
|---|---|---|
| U2 | 35 | - |

### NC__U2__4
| Bilesen | Pin | Bu nette bagli diger pinler |
|---|---|---|
| U2 | 4 | - |

### NC__U2__5
| Bilesen | Pin | Bu nette bagli diger pinler |
|---|---|---|
| U2 | 5 | - |

### NC__U2__8
| Bilesen | Pin | Bu nette bagli diger pinler |
|---|---|---|
| U2 | 8 | - |

### NC__U2__9
| Bilesen | Pin | Bu nette bagli diger pinler |
|---|---|---|
| U2 | 9 | - |

### NC__U3__12
| Bilesen | Pin | Bu nette bagli diger pinler |
|---|---|---|
| U3 | 12 | - |

### NC__U3__13
| Bilesen | Pin | Bu nette bagli diger pinler |
|---|---|---|
| U3 | 13 | - |

### NC__U3__14
| Bilesen | Pin | Bu nette bagli diger pinler |
|---|---|---|
| U3 | 14 | - |

### NC__U3__26
| Bilesen | Pin | Bu nette bagli diger pinler |
|---|---|---|
| U3 | 26 | - |

### NC__U3__27
| Bilesen | Pin | Bu nette bagli diger pinler |
|---|---|---|
| U3 | 27 | - |

### NC__U3__28
| Bilesen | Pin | Bu nette bagli diger pinler |
|---|---|---|
| U3 | 28 | - |

### NC__U3__29
| Bilesen | Pin | Bu nette bagli diger pinler |
|---|---|---|
| U3 | 29 | - |

### NC__U3__30
| Bilesen | Pin | Bu nette bagli diger pinler |
|---|---|---|
| U3 | 30 | - |

### NC__U4__17
| Bilesen | Pin | Bu nette bagli diger pinler |
|---|---|---|
| U4 | 17 | - |

### NC__U4__18
| Bilesen | Pin | Bu nette bagli diger pinler |
|---|---|---|
| U4 | 18 | - |

### NC__U4__7
| Bilesen | Pin | Bu nette bagli diger pinler |
|---|---|---|
| U4 | 7 | - |

### NS4150_BYP
| Bilesen | Pin | Bu nette bagli diger pinler |
|---|---|---|
| U5 | 2 | - |

### PA_CTRL
| Bilesen | Pin | Bu nette bagli diger pinler |
|---|---|---|
| R3 | 1 | U1.16, U5.1 |
| U1 | 16 | R3.1, U5.1 |
| U5 | 1 | R3.1, U1.16 |

### PWRON
| Bilesen | Pin | Bu nette bagli diger pinler |
|---|---|---|
| U2 | 30 | - |

### SPK_N
| Bilesen | Pin | Bu nette bagli diger pinler |
|---|---|---|
| U5 | 5 | - |

### SPK_P
| Bilesen | Pin | Bu nette bagli diger pinler |
|---|---|---|
| U5 | 8 | - |

### SYS
| Bilesen | Pin | Bu nette bagli diger pinler |
|---|---|---|
| C3 | 1 | U2.13, U2.17, U2.23, U2.24, U2.34, U2.6, U2.7 |
| U2 | 13 | C3.1, U2.17, U2.23, U2.24, U2.34, U2.6, U2.7 |
| U2 | 17 | C3.1, U2.13, U2.23, U2.24, U2.34, U2.6, U2.7 |
| U2 | 23 | C3.1, U2.13, U2.17, U2.24, U2.34, U2.6, U2.7 |
| U2 | 24 | C3.1, U2.13, U2.17, U2.23, U2.34, U2.6, U2.7 |
| U2 | 34 | C3.1, U2.13, U2.17, U2.23, U2.24, U2.6, U2.7 |
| U2 | 6 | C3.1, U2.13, U2.17, U2.23, U2.24, U2.34, U2.7 |
| U2 | 7 | C3.1, U2.13, U2.17, U2.23, U2.24, U2.34, U2.6 |

### TFT_BL
| Bilesen | Pin | Bu nette bagli diger pinler |
|---|---|---|
| J2 | 8 | U1.33 |
| U1 | 33 | J2.8 |

### TFT_CS
| Bilesen | Pin | Bu nette bagli diger pinler |
|---|---|---|
| J2 | 3 | U1.5 |
| U1 | 5 | J2.3 |

### TFT_DC
| Bilesen | Pin | Bu nette bagli diger pinler |
|---|---|---|
| J2 | 5 | U1.4 |
| U1 | 4 | J2.5 |

### TFT_MOSI
| Bilesen | Pin | Bu nette bagli diger pinler |
|---|---|---|
| J2 | 6 | U1.7 |
| U1 | 7 | J2.6 |

### TFT_RST
| Bilesen | Pin | Bu nette bagli diger pinler |
|---|---|---|
| J2 | 4 | U1.31 |
| U1 | 31 | J2.4 |

### TFT_SCLK
| Bilesen | Pin | Bu nette bagli diger pinler |
|---|---|---|
| J2 | 7 | U1.6 |
| U1 | 6 | J2.7 |

### UART_RXD
| Bilesen | Pin | Bu nette bagli diger pinler |
|---|---|---|
| U1 | 36 | - |

### UART_TXD
| Bilesen | Pin | Bu nette bagli diger pinler |
|---|---|---|
| U1 | 37 | - |

### USB_DM
| Bilesen | Pin | Bu nette bagli diger pinler |
|---|---|---|
| J1 | A7 | J1.B7, U1.13 |
| J1 | B7 | J1.A7, U1.13 |
| U1 | 13 | J1.A7, J1.B7 |

### USB_DP
| Bilesen | Pin | Bu nette bagli diger pinler |
|---|---|---|
| J1 | A6 | J1.B6, U1.14 |
| J1 | B6 | J1.A6, U1.14 |
| U1 | 14 | J1.A6, J1.B6 |

### VBAT
| Bilesen | Pin | Bu nette bagli diger pinler |
|---|---|---|
| C4 | 1 | C13.1, U2.33, U5.6 |
| C13 | 1 | C4.1, U2.33, U5.6 |
| U2 | 33 | C4.1, C13.1, U5.6 |
| U5 | 6 | C4.1, C13.1, U2.33 |

### VBUS
| Bilesen | Pin | Bu nette bagli diger pinler |
|---|---|---|
| C2 | 1 | C6.1, J1.A4B9, J1.B4A9, U2.37 |
| C6 | 1 | C2.1, J1.A4B9, J1.B4A9, U2.37 |
| J1 | A4B9 | C2.1, C6.1, J1.B4A9, U2.37 |
| J1 | B4A9 | C2.1, C6.1, J1.A4B9, U2.37 |
| U2 | 37 | C2.1, C6.1, J1.A4B9, J1.B4A9 |

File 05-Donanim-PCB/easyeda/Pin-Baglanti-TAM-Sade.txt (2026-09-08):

1uF Kondansator C1 Pin 1 -> 10k Direnc R2 Pin 1, ESP32 Pin 3, AXP2101 Pin 29
1uF Kondansator C1 Pin 2 -> 10uF Kondansator C2 Pin 2, 22uF Kondansator C3 Pin 2, 1uF Kondansator C4 Pin 2, 10uF Kondansator C5 Pin 2, 10uF Kondansator C6 Pin 2, 1uF Kondansator C7 Pin 2, 1uF Kondansator C8 Pin 2, 1uF Kondansator C9 Pin 2, 1uF Kondansator C10 Pin 2, 100nF Kondansator C11 Pin 2, 100nF Kondansator C12 Pin 2, 10uF Kondansator C13 Pin 2, USB-C Konnektor Pin 13, USB-C Konnektor Pin 14, USB-C Konnektor Pin A1B12, USB-C Konnektor Pin B1A12, LCD/Dokunmatik Konnektor Pin 14, LCD/Dokunmatik Konnektor Pin 15, LCD/Dokunmatik Konnektor Pin 16, LCD/Dokunmatik Konnektor Pin 2, Mikrofon-1 Pin 1, Mikrofon-1 Pin 2, Mikrofon-1 Pin 3, Mikrofon-2 Pin 1, Mikrofon-2 Pin 2, Mikrofon-2 Pin 3, 10k Direnc R3 Pin 2, 5.1k Direnc R4 Pin 1, 5.1k Direnc R5 Pin 2, 10k Direnc R9 Pin 2, ESP32 Pin 1, ESP32 Pin 40, ESP32 Pin 41, AXP2101 Pin 3, AXP2101 Pin 41, ES7210 Pin 1, ES7210 Pin 2, ES7210 Pin 21, ES7210 Pin 33, ES7210 Pin 8, ES8311 Pin 10, ES8311 Pin 21, ES8311 Pin 5, NS4150 Pin 7
10uF Kondansator C2 Pin 1 -> 10uF Kondansator C6 Pin 1, USB-C Konnektor Pin A4B9, USB-C Konnektor Pin B4A9, AXP2101 Pin 37
10uF Kondansator C2 Pin 2 -> 1uF Kondansator C1 Pin 2, 22uF Kondansator C3 Pin 2, 1uF Kondansator C4 Pin 2, 10uF Kondansator C5 Pin 2, 10uF Kondansator C6 Pin 2, 1uF Kondansator C7 Pin 2, 1uF Kondansator C8 Pin 2, 1uF Kondansator C9 Pin 2, 1uF Kondansator C10 Pin 2, 100nF Kondansator C11 Pin 2, 100nF Kondansator C12 Pin 2, 10uF Kondansator C13 Pin 2, USB-C Konnektor Pin 13, USB-C Konnektor Pin 14, USB-C Konnektor Pin A1B12, USB-C Konnektor Pin B1A12, LCD/Dokunmatik Konnektor Pin 14, LCD/Dokunmatik Konnektor Pin 15, LCD/Dokunmatik Konnektor Pin 16, LCD/Dokunmatik Konnektor Pin 2, Mikrofon-1 Pin 1, Mikrofon-1 Pin 2, Mikrofon-1 Pin 3, Mikrofon-2 Pin 1, Mikrofon-2 Pin 2, Mikrofon-2 Pin 3, 10k Direnc R3 Pin 2, 5.1k Direnc R4 Pin 1, 5.1k Direnc R5 Pin 2, 10k Direnc R9 Pin 2, ESP32 Pin 1, ESP32 Pin 40, ESP32 Pin 41, AXP2101 Pin 3, AXP2101 Pin 41, ES7210 Pin 1, ES7210 Pin 2, ES7210 Pin 21, ES7210 Pin 33, ES7210 Pin 8, ES8311 Pin 10, ES8311 Pin 21, ES8311 Pin 5, NS4150 Pin 7
22uF Kondansator C3 Pin 1 -> AXP2101 Pin 13, AXP2101 Pin 17, AXP2101 Pin 23, AXP2101 Pin 24, AXP2101 Pin 34, AXP2101 Pin 6, AXP2101 Pin 7
22uF Kondansator C3 Pin 2 -> 1uF Kondansator C1 Pin 2, 10uF Kondansator C2 Pin 2, 1uF Kondansator C4 Pin 2, 10uF Kondansator C5 Pin 2, 10uF Kondansator C6 Pin 2, 1uF Kondansator C7 Pin 2, 1uF Kondansator C8 Pin 2, 1uF Kondansator C9 Pin 2, 1uF Kondansator C10 Pin 2, 100nF Kondansator C11 Pin 2, 100nF Kondansator C12 Pin 2, 10uF Kondansator C13 Pin 2, USB-C Konnektor Pin 13, USB-C Konnektor Pin 14, USB-C Konnektor Pin A1B12, USB-C Konnektor Pin B1A12, LCD/Dokunmatik Konnektor Pin 14, LCD/Dokunmatik Konnektor Pin 15, LCD/Dokunmatik Konnektor Pin 16, LCD/Dokunmatik Konnektor Pin 2, Mikrofon-1 Pin 1, Mikrofon-1 Pin 2, Mikrofon-1 Pin 3, Mikrofon-2 Pin 1, Mikrofon-2 Pin 2, Mikrofon-2 Pin 3, 10k Direnc R3 Pin 2, 5.1k Direnc R4 Pin 1, 5.1k Direnc R5 Pin 2, 10k Direnc R9 Pin 2, ESP32 Pin 1, ESP32 Pin 40, ESP32 Pin 41, AXP2101 Pin 3, AXP2101 Pin 41, ES7210 Pin 1, ES7210 Pin 2, ES7210 Pin 21, ES7210 Pin 33, ES7210 Pin 8, ES8311 Pin 10, ES8311 Pin 21, ES8311 Pin 5, NS4150 Pin 7
1uF Kondansator C4 Pin 1 -> 10uF Kondansator C13 Pin 1, AXP2101 Pin 33, NS4150 Pin 6
1uF Kondansator C4 Pin 2 -> 1uF Kondansator C1 Pin 2, 10uF Kondansator C2 Pin 2, 22uF Kondansator C3 Pin 2, 10uF Kondansator C5 Pin 2, 10uF Kondansator C6 Pin 2, 1uF Kondansator C7 Pin 2, 1uF Kondansator C8 Pin 2, 1uF Kondansator C9 Pin 2, 1uF Kondansator C10 Pin 2, 100nF Kondansator C11 Pin 2, 100nF Kondansator C12 Pin 2, 10uF Kondansator C13 Pin 2, USB-C Konnektor Pin 13, USB-C Konnektor Pin 14, USB-C Konnektor Pin A1B12, USB-C Konnektor Pin B1A12, LCD/Dokunmatik Konnektor Pin 14, LCD/Dokunmatik Konnektor Pin 15, LCD/Dokunmatik Konnektor Pin 16, LCD/Dokunmatik Konnektor Pin 2, Mikrofon-1 Pin 1, Mikrofon-1 Pin 2, Mikrofon-1 Pin 3, Mikrofon-2 Pin 1, Mikrofon-2 Pin 2, Mikrofon-2 Pin 3, 10k Direnc R3 Pin 2, 5.1k Direnc R4 Pin 1, 5.1k Direnc R5 Pin 2, 10k Direnc R9 Pin 2, ESP32 Pin 1, ESP32 Pin 40, ESP32 Pin 41, AXP2101 Pin 3, AXP2101 Pin 41, ES7210 Pin 1, ES7210 Pin 2, ES7210 Pin 21, ES7210 Pin 33, ES7210 Pin 8, ES8311 Pin 10, ES8311 Pin 21, ES8311 Pin 5, NS4150 Pin 7
10uF Kondansator C5 Pin 1 -> 1uH Bobin Pin 2, 10k Direnc R1 Pin 2, 10k Direnc R2 Pin 2, 4.7k Direnc R6 Pin 2, 4.7k Direnc R7 Pin 2, 10k Direnc R8 Pin 2, ESP32 Pin 2, AXP2101 Pin 14, AXP2101 Pin 21
10uF Kondansator C5 Pin 2 -> 1uF Kondansator C1 Pin 2, 10uF Kondansator C2 Pin 2, 22uF Kondansator C3 Pin 2, 1uF Kondansator C4 Pin 2, 10uF Kondansator C6 Pin 2, 1uF Kondansator C7 Pin 2, 1uF Kondansator C8 Pin 2, 1uF Kondansator C9 Pin 2, 1uF Kondansator C10 Pin 2, 100nF Kondansator C11 Pin 2, 100nF Kondansator C12 Pin 2, 10uF Kondansator C13 Pin 2, USB-C Konnektor Pin 13, USB-C Konnektor Pin 14, USB-C Konnektor Pin A1B12, USB-C Konnektor Pin B1A12, LCD/Dokunmatik Konnektor Pin 14, LCD/Dokunmatik Konnektor Pin 15, LCD/Dokunmatik Konnektor Pin 16, LCD/Dokunmatik Konnektor Pin 2, Mikrofon-1 Pin 1, Mikrofon-1 Pin 2, Mikrofon-1 Pin 3, Mikrofon-2 Pin 1, Mikrofon-2 Pin 2, Mikrofon-2 Pin 3, 10k Direnc R3 Pin 2, 5.1k Direnc R4 Pin 1, 5.1k Direnc R5 Pin 2, 10k Direnc R9 Pin 2, ESP32 Pin 1, ESP32 Pin 40, ESP32 Pin 41, AXP2101 Pin 3, AXP2101 Pin 41, ES7210 Pin 1, ES7210 Pin 2, ES7210 Pin 21, ES7210 Pin 33, ES7210 Pin 8, ES8311 Pin 10, ES8311 Pin 21, ES8311 Pin 5, NS4150 Pin 7
10uF Kondansator C6 Pin 1 -> 10uF Kondansator C2 Pin 1, USB-C Konnektor Pin A4B9, USB-C Konnektor Pin B4A9, AXP2101 Pin 37
10uF Kondansator C6 Pin 2 -> 1uF Kondansator C1 Pin 2, 10uF Kondansator C2 Pin 2, 22uF Kondansator C3 Pin 2, 1uF Kondansator C4 Pin 2, 10uF Kondansator C5 Pin 2, 1uF Kondansator C7 Pin 2, 1uF Kondansator C8 Pin 2, 1uF Kondansator C9 Pin 2, 1uF Kondansator C10 Pin 2, 100nF Kondansator C11 Pin 2, 100nF Kondansator C12 Pin 2, 10uF Kondansator C13 Pin 2, USB-C Konnektor Pin 13, USB-C Konnektor Pin 14, USB-C Konnektor Pin A1B12, USB-C Konnektor Pin B1A12, LCD/Dokunmatik Konnektor Pin 14, LCD/Dokunmatik Konnektor Pin 15, LCD/Dokunmatik Konnektor Pin 16, LCD/Dokunmatik Konnektor Pin 2, Mikrofon-1 Pin 1, Mikrofon-1 Pin 2, Mikrofon-1 Pin 3, Mikrofon-2 Pin 1, Mikrofon-2 Pin 2, Mikrofon-2 Pin 3, 10k Direnc R3 Pin 2, 5.1k Direnc R4 Pin 1, 5.1k Direnc R5 Pin 2, 10k Direnc R9 Pin 2, ESP32 Pin 1, ESP32 Pin 40, ESP32 Pin 41, AXP2101 Pin 3, AXP2101 Pin 41, ES7210 Pin 1, ES7210 Pin 2, ES7210 Pin 21, ES7210 Pin 33, ES7210 Pin 8, ES8311 Pin 10, ES8311 Pin 21, ES8311 Pin 5, NS4150 Pin 7
1uF Kondansator C7 Pin 1 -> 100nF Kondansator C12 Pin 1, AXP2101 Pin 18, ES8311 Pin 11, ES8311 Pin 20, ES8311 Pin 3, ES8311 Pin 4
1uF Kondansator C7 Pin 2 -> 1uF Kondansator C1 Pin 2, 10uF Kondansator C2 Pin 2, 22uF Kondansator C3 Pin 2, 1uF Kondansator C4 Pin 2, 10uF Kondansator C5 Pin 2, 10uF Kondansator C6 Pin 2, 1uF Kondansator C8 Pin 2, 1uF Kondansator C9 Pin 2, 1uF Kondansator C10 Pin 2, 100nF Kondansator C11 Pin 2, 100nF Kondansator C12 Pin 2, 10uF Kondansator C13 Pin 2, USB-C Konnektor Pin 13, USB-C Konnektor Pin 14, USB-C Konnektor Pin A1B12, USB-C Konnektor Pin B1A12, LCD/Dokunmatik Konnektor Pin 14, LCD/Dokunmatik Konnektor Pin 15, LCD/Dokunmatik Konnektor Pin 16, LCD/Dokunmatik Konnektor Pin 2, Mikrofon-1 Pin 1, Mikrofon-1 Pin 2, Mikrofon-1 Pin 3, Mikrofon-2 Pin 1, Mikrofon-2 Pin 2, Mikrofon-2 Pin 3, 10k Direnc R3 Pin 2, 5.1k Direnc R4 Pin 1, 5.1k Direnc R5 Pin 2, 10k Direnc R9 Pin 2, ESP32 Pin 1, ESP32 Pin 40, ESP32 Pin 41, AXP2101 Pin 3, AXP2101 Pin 41, ES7210 Pin 1, ES7210 Pin 2, ES7210 Pin 21, ES7210 Pin 33, ES7210 Pin 8, ES8311 Pin 10, ES8311 Pin 21, ES8311 Pin 5, NS4150 Pin 7
1uF Kondansator C8 Pin 1 -> 100nF Kondansator C11 Pin 1, AXP2101 Pin 19, ES7210 Pin 22, ES7210 Pin 23, ES7210 Pin 6, ES7210 Pin 7
1uF Kondansator C8 Pin 2 -> 1uF Kondansator C1 Pin 2, 10uF Kondansator C2 Pin 2, 22uF Kondansator C3 Pin 2, 1uF Kondansator C4 Pin 2, 10uF Kondansator C5 Pin 2, 10uF Kondansator C6 Pin 2, 1uF Kondansator C7 Pin 2, 1uF Kondansator C9 Pin 2, 1uF Kondansator C10 Pin 2, 100nF Kondansator C11 Pin 2, 100nF Kondansator C12 Pin 2, 10uF Kondansator C13 Pin 2, USB-C Konnektor Pin 13, USB-C Konnektor Pin 14, USB-C Konnektor Pin A1B12, USB-C Konnektor Pin B1A12, LCD/Dokunmatik Konnektor Pin 14, LCD/Dokunmatik Konnektor Pin 15, LCD/Dokunmatik Konnektor Pin 16, LCD/Dokunmatik Konnektor Pin 2, Mikrofon-1 Pin 1, Mikrofon-1 Pin 2, Mikrofon-1 Pin 3, Mikrofon-2 Pin 1, Mikrofon-2 Pin 2, Mikrofon-2 Pin 3, 10k Direnc R3 Pin 2, 5.1k Direnc R4 Pin 1, 5.1k Direnc R5 Pin 2, 10k Direnc R9 Pin 2, ESP32 Pin 1, ESP32 Pin 40, ESP32 Pin 41, AXP2101 Pin 3, AXP2101 Pin 41, ES7210 Pin 1, ES7210 Pin 2, ES7210 Pin 21, ES7210 Pin 33, ES7210 Pin 8, ES8311 Pin 10, ES8311 Pin 21, ES8311 Pin 5, NS4150 Pin 7
1uF Kondansator C9 Pin 1 -> LCD/Dokunmatik Konnektor Pin 1, AXP2101 Pin 16
1uF Kondansator C9 Pin 2 -> 1uF Kondansator C1 Pin 2, 10uF Kondansator C2 Pin 2, 22uF Kondansator C3 Pin 2, 1uF Kondansator C4 Pin 2, 10uF Kondansator C5 Pin 2, 10uF Kondansator C6 Pin 2, 1uF Kondansator C7 Pin 2, 1uF Kondansator C8 Pin 2, 1uF Kondansator C10 Pin 2, 100nF Kondansator C11 Pin 2, 100nF Kondansator C12 Pin 2, 10uF Kondansator C13 Pin 2, USB-C Konnektor Pin 13, USB-C Konnektor Pin 14, USB-C Konnektor Pin A1B12, USB-C Konnektor Pin B1A12, LCD/Dokunmatik Konnektor Pin 14, LCD/Dokunmatik Konnektor Pin 15, LCD/Dokunmatik Konnektor Pin 16, LCD/Dokunmatik Konnektor Pin 2, Mikrofon-1 Pin 1, Mikrofon-1 Pin 2, Mikrofon-1 Pin 3, Mikrofon-2 Pin 1, Mikrofon-2 Pin 2, Mikrofon-2 Pin 3, 10k Direnc R3 Pin 2, 5.1k Direnc R4 Pin 1, 5.1k Direnc R5 Pin 2, 10k Direnc R9 Pin 2, ESP32 Pin 1, ESP32 Pin 40, ESP32 Pin 41, AXP2101 Pin 3, AXP2101 Pin 41, ES7210 Pin 1, ES7210 Pin 2, ES7210 Pin 21, ES7210 Pin 33, ES7210 Pin 8, ES8311 Pin 10, ES8311 Pin 21, ES8311 Pin 5, NS4150 Pin 7
1uF Kondansator C10 Pin 1 -> AXP2101 Pin 12
1uF Kondansator C10 Pin 2 -> 1uF Kondansator C1 Pin 2, 10uF Kondansator C2 Pin 2, 22uF Kondansator C3 Pin 2, 1uF Kondansator C4 Pin 2, 10uF Kondansator C5 Pin 2, 10uF Kondansator C6 Pin 2, 1uF Kondansator C7 Pin 2, 1uF Kondansator C8 Pin 2, 1uF Kondansator C9 Pin 2, 100nF Kondansator C11 Pin 2, 100nF Kondansator C12 Pin 2, 10uF Kondansator C13 Pin 2, USB-C Konnektor Pin 13, USB-C Konnektor Pin 14, USB-C Konnektor Pin A1B12, USB-C Konnektor Pin B1A12, LCD/Dokunmatik Konnektor Pin 14, LCD/Dokunmatik Konnektor Pin 15, LCD/Dokunmatik Konnektor Pin 16, LCD/Dokunmatik Konnektor Pin 2, Mikrofon-1 Pin 1, Mikrofon-1 Pin 2, Mikrofon-1 Pin 3, Mikrofon-2 Pin 1, Mikrofon-2 Pin 2, Mikrofon-2 Pin 3, 10k Direnc R3 Pin 2, 5.1k Direnc R4 Pin 1, 5.1k Direnc R5 Pin 2, 10k Direnc R9 Pin 2, ESP32 Pin 1, ESP32 Pin 40, ESP32 Pin 41, AXP2101 Pin 3, AXP2101 Pin 41, ES7210 Pin 1, ES7210 Pin 2, ES7210 Pin 21, ES7210 Pin 33, ES7210 Pin 8, ES8311 Pin 10, ES8311 Pin 21, ES8311 Pin 5, NS4150 Pin 7
100nF Kondansator C11 Pin 1 -> 1uF Kondansator C8 Pin 1, AXP2101 Pin 19, ES7210 Pin 22, ES7210 Pin 23, ES7210 Pin 6, ES7210 Pin 7
100nF Kondansator C11 Pin 2 -> 1uF Kondansator C1 Pin 2, 10uF Kondansator C2 Pin 2, 22uF Kondansator C3 Pin 2, 1uF Kondansator C4 Pin 2, 10uF Kondansator C5 Pin 2, 10uF Kondansator C6 Pin 2, 1uF Kondansator C7 Pin 2, 1uF Kondansator C8 Pin 2, 1uF Kondansator C9 Pin 2, 1uF Kondansator C10 Pin 2, 100nF Kondansator C12 Pin 2, 10uF Kondansator C13 Pin 2, USB-C Konnektor Pin 13, USB-C Konnektor Pin 14, USB-C Konnektor Pin A1B12, USB-C Konnektor Pin B1A12, LCD/Dokunmatik Konnektor Pin 14, LCD/Dokunmatik Konnektor Pin 15, LCD/Dokunmatik Konnektor Pin 16, LCD/Dokunmatik Konnektor Pin 2, Mikrofon-1 Pin 1, Mikrofon-1 Pin 2, Mikrofon-1 Pin 3, Mikrofon-2 Pin 1, Mikrofon-2 Pin 2, Mikrofon-2 Pin 3, 10k Direnc R3 Pin 2, 5.1k Direnc R4 Pin 1, 5.1k Direnc R5 Pin 2, 10k Direnc R9 Pin 2, ESP32 Pin 1, ESP32 Pin 40, ESP32 Pin 41, AXP2101 Pin 3, AXP2101 Pin 41, ES7210 Pin 1, ES7210 Pin 2, ES7210 Pin 21, ES7210 Pin 33, ES7210 Pin 8, ES8311 Pin 10, ES8311 Pin 21, ES8311 Pin 5, NS4150 Pin 7
100nF Kondansator C12 Pin 1 -> 1uF Kondansator C7 Pin 1, AXP2101 Pin 18, ES8311 Pin 11, ES8311 Pin 20, ES8311 Pin 3, ES8311 Pin 4
100nF Kondansator C12 Pin 2 -> 1uF Kondansator C1 Pin 2, 10uF Kondansator C2 Pin 2, 22uF Kondansator C3 Pin 2, 1uF Kondansator C4 Pin 2, 10uF Kondansator C5 Pin 2, 10uF Kondansator C6 Pin 2, 1uF Kondansator C7 Pin 2, 1uF Kondansator C8 Pin 2, 1uF Kondansator C9 Pin 2, 1uF Kondansator C10 Pin 2, 100nF Kondansator C11 Pin 2, 10uF Kondansator C13 Pin 2, USB-C Konnektor Pin 13, USB-C Konnektor Pin 14, USB-C Konnektor Pin A1B12, USB-C Konnektor Pin B1A12, LCD/Dokunmatik Konnektor Pin 14, LCD/Dokunmatik Konnektor Pin 15, LCD/Dokunmatik Konnektor Pin 16, LCD/Dokunmatik Konnektor Pin 2, Mikrofon-1 Pin 1, Mikrofon-1 Pin 2, Mikrofon-1 Pin 3, Mikrofon-2 Pin 1, Mikrofon-2 Pin 2, Mikrofon-2 Pin 3, 10k Direnc R3 Pin 2, 5.1k Direnc R4 Pin 1, 5.1k Direnc R5 Pin 2, 10k Direnc R9 Pin 2, ESP32 Pin 1, ESP32 Pin 40, ESP32 Pin 41, AXP2101 Pin 3, AXP2101 Pin 41, ES7210 Pin 1, ES7210 Pin 2, ES7210 Pin 21, ES7210 Pin 33, ES7210 Pin 8, ES8311 Pin 10, ES8311 Pin 21, ES8311 Pin 5, NS4150 Pin 7
10uF Kondansator C13 Pin 1 -> 1uF Kondansator C4 Pin 1, AXP2101 Pin 33, NS4150 Pin 6
10uF Kondansator C13 Pin 2 -> 1uF Kondansator C1 Pin 2, 10uF Kondansator C2 Pin 2, 22uF Kondansator C3 Pin 2, 1uF Kondansator C4 Pin 2, 10uF Kondansator C5 Pin 2, 10uF Kondansator C6 Pin 2, 1uF Kondansator C7 Pin 2, 1uF Kondansator C8 Pin 2, 1uF Kondansator C9 Pin 2, 1uF Kondansator C10 Pin 2, 100nF Kondansator C11 Pin 2, 100nF Kondansator C12 Pin 2, USB-C Konnektor Pin 13, USB-C Konnektor Pin 14, USB-C Konnektor Pin A1B12, USB-C Konnektor Pin B1A12, LCD/Dokunmatik Konnektor Pin 14, LCD/Dokunmatik Konnektor Pin 15, LCD/Dokunmatik Konnektor Pin 16, LCD/Dokunmatik Konnektor Pin 2, Mikrofon-1 Pin 1, Mikrofon-1 Pin 2, Mikrofon-1 Pin 3, Mikrofon-2 Pin 1, Mikrofon-2 Pin 2, Mikrofon-2 Pin 3, 10k Direnc R3 Pin 2, 5.1k Direnc R4 Pin 1, 5.1k Direnc R5 Pin 2, 10k Direnc R9 Pin 2, ESP32 Pin 1, ESP32 Pin 40, ESP32 Pin 41, AXP2101 Pin 3, AXP2101 Pin 41, ES7210 Pin 1, ES7210 Pin 2, ES7210 Pin 21, ES7210 Pin 33, ES7210 Pin 8, ES8311 Pin 10, ES8311 Pin 21, ES8311 Pin 5, NS4150 Pin 7
USB-C Konnektor Pin 13 -> 1uF Kondansator C1 Pin 2, 10uF Kondansator C2 Pin 2, 22uF Kondansator C3 Pin 2, 1uF Kondansator C4 Pin 2, 10uF Kondansator C5 Pin 2, 10uF Kondansator C6 Pin 2, 1uF Kondansator C7 Pin 2, 1uF Kondansator C8 Pin 2, 1uF Kondansator C9 Pin 2, 1uF Kondansator C10 Pin 2, 100nF Kondansator C11 Pin 2, 100nF Kondansator C12 Pin 2, 10uF Kondansator C13 Pin 2, USB-C Konnektor Pin 14, USB-C Konnektor Pin A1B12, USB-C Konnektor Pin B1A12, LCD/Dokunmatik Konnektor Pin 14, LCD/Dokunmatik Konnektor Pin 15, LCD/Dokunmatik Konnektor Pin 16, LCD/Dokunmatik Konnektor Pin 2, Mikrofon-1 Pin 1, Mikrofon-1 Pin 2, Mikrofon-1 Pin 3, Mikrofon-2 Pin 1, Mikrofon-2 Pin 2, Mikrofon-2 Pin 3, 10k Direnc R3 Pin 2, 5.1k Direnc R4 Pin 1, 5.1k Direnc R5 Pin 2, 10k Direnc R9 Pin 2, ESP32 Pin 1, ESP32 Pin 40, ESP32 Pin 41, AXP2101 Pin 3, AXP2101 Pin 41, ES7210 Pin 1, ES7210 Pin 2, ES7210 Pin 21, ES7210 Pin 33, ES7210 Pin 8, ES8311 Pin 10, ES8311 Pin 21, ES8311 Pin 5, NS4150 Pin 7
USB-C Konnektor Pin 14 -> 1uF Kondansator C1 Pin 2, 10uF Kondansator C2 Pin 2, 22uF Kondansator C3 Pin 2, 1uF Kondansator C4 Pin 2, 10uF Kondansator C5 Pin 2, 10uF Kondansator C6 Pin 2, 1uF Kondansator C7 Pin 2, 1uF Kondansator C8 Pin 2, 1uF Kondansator C9 Pin 2, 1uF Kondansator C10 Pin 2, 100nF Kondansator C11 Pin 2, 100nF Kondansator C12 Pin 2, 10uF Kondansator C13 Pin 2, USB-C Konnektor Pin 13, USB-C Konnektor Pin A1B12, USB-C Konnektor Pin B1A12, LCD/Dokunmatik Konnektor Pin 14, LCD/Dokunmatik Konnektor Pin 15, LCD/Dokunmatik Konnektor Pin 16, LCD/Dokunmatik Konnektor Pin 2, Mikrofon-1 Pin 1, Mikrofon-1 Pin 2, Mikrofon-1 Pin 3, Mikrofon-2 Pin 1, Mikrofon-2 Pin 2, Mikrofon-2 Pin 3, 10k Direnc R3 Pin 2, 5.1k Direnc R4 Pin 1, 5.1k Direnc R5 Pin 2, 10k Direnc R9 Pin 2, ESP32 Pin 1, ESP32 Pin 40, ESP32 Pin 41, AXP2101 Pin 3, AXP2101 Pin 41, ES7210 Pin 1, ES7210 Pin 2, ES7210 Pin 21, ES7210 Pin 33, ES7210 Pin 8, ES8311 Pin 10, ES8311 Pin 21, ES8311 Pin 5, NS4150 Pin 7
USB-C Konnektor Pin A1B12 -> 1uF Kondansator C1 Pin 2, 10uF Kondansator C2 Pin 2, 22uF Kondansator C3 Pin 2, 1uF Kondansator C4 Pin 2, 10uF Kondansator C5 Pin 2, 10uF Kondansator C6 Pin 2, 1uF Kondansator C7 Pin 2, 1uF Kondansator C8 Pin 2, 1uF Kondansator C9 Pin 2, 1uF Kondansator C10 Pin 2, 100nF Kondansator C11 Pin 2, 100nF Kondansator C12 Pin 2, 10uF Kondansator C13 Pin 2, USB-C Konnektor Pin 13, USB-C Konnektor Pin 14, USB-C Konnektor Pin B1A12, LCD/Dokunmatik Konnektor Pin 14, LCD/Dokunmatik Konnektor Pin 15, LCD/Dokunmatik Konnektor Pin 16, LCD/Dokunmatik Konnektor Pin 2, Mikrofon-1 Pin 1, Mikrofon-1 Pin 2, Mikrofon-1 Pin 3, Mikrofon-2 Pin 1, Mikrofon-2 Pin 2, Mikrofon-2 Pin 3, 10k Direnc R3 Pin 2, 5.1k Direnc R4 Pin 1, 5.1k Direnc R5 Pin 2, 10k Direnc R9 Pin 2, ESP32 Pin 1, ESP32 Pin 40, ESP32 Pin 41, AXP2101 Pin 3, AXP2101 Pin 41, ES7210 Pin 1, ES7210 Pin 2, ES7210 Pin 21, ES7210 Pin 33, ES7210 Pin 8, ES8311 Pin 10, ES8311 Pin 21, ES8311 Pin 5, NS4150 Pin 7
USB-C Konnektor Pin A4B9 -> 10uF Kondansator C2 Pin 1, 10uF Kondansator C6 Pin 1, USB-C Konnektor Pin B4A9, AXP2101 Pin 37
USB-C Konnektor Pin A5 -> 5.1k Direnc R4 Pin 2
USB-C Konnektor Pin A6 -> USB-C Konnektor Pin B6, ESP32 Pin 14
USB-C Konnektor Pin A7 -> USB-C Konnektor Pin B7, ESP32 Pin 13
USB-C Konnektor Pin A8 -> NC (Baglanmayacak)
USB-C Konnektor Pin B1A12 -> 1uF Kondansator C1 Pin 2, 10uF Kondansator C2 Pin 2, 22uF Kondansator C3 Pin 2, 1uF Kondansator C4 Pin 2, 10uF Kondansator C5 Pin 2, 10uF Kondansator C6 Pin 2, 1uF Kondansator C7 Pin 2, 1uF Kondansator C8 Pin 2, 1uF Kondansator C9 Pin 2, 1uF Kondansator C10 Pin 2, 100nF Kondansator C11 Pin 2, 100nF Kondansator C12 Pin 2, 10uF Kondansator C13 Pin 2, USB-C Konnektor Pin 13, USB-C Konnektor Pin 14, USB-C Konnektor Pin A1B12, LCD/Dokunmatik Konnektor Pin 14, LCD/Dokunmatik Konnektor Pin 15, LCD/Dokunmatik Konnektor Pin 16, LCD/Dokunmatik Konnektor Pin 2, Mikrofon-1 Pin 1, Mikrofon-1 Pin 2, Mikrofon-1 Pin 3, Mikrofon-2 Pin 1, Mikrofon-2 Pin 2, Mikrofon-2 Pin 3, 10k Direnc R3 Pin 2, 5.1k Direnc R4 Pin 1, 5.1k Direnc R5 Pin 2, 10k Direnc R9 Pin 2, ESP32 Pin 1, ESP32 Pin 40, ESP32 Pin 41, AXP2101 Pin 3, AXP2101 Pin 41, ES7210 Pin 1, ES7210 Pin 2, ES7210 Pin 21, ES7210 Pin 33, ES7210 Pin 8, ES8311 Pin 10, ES8311 Pin 21, ES8311 Pin 5, NS4150 Pin 7
USB-C Konnektor Pin B4A9 -> 10uF Kondansator C2 Pin 1, 10uF Kondansator C6 Pin 1, USB-C Konnektor Pin A4B9, AXP2101 Pin 37
USB-C Konnektor Pin B5 -> 5.1k Direnc R5 Pin 1
USB-C Konnektor Pin B6 -> USB-C Konnektor Pin A6, ESP32 Pin 14
USB-C Konnektor Pin B7 -> USB-C Konnektor Pin A7, ESP32 Pin 13
USB-C Konnektor Pin B8 -> NC (Baglanmayacak)
LCD/Dokunmatik Konnektor Pin 1 -> 1uF Kondansator C9 Pin 1, AXP2101 Pin 16
LCD/Dokunmatik Konnektor Pin 10 -> 4.7k Direnc R7 Pin 1, ESP32 Pin 22, AXP2101 Pin 40, ES7210 Pin 4, ES8311 Pin 1
LCD/Dokunmatik Konnektor Pin 11 -> 4.7k Direnc R6 Pin 1, ESP32 Pin 8, AXP2101 Pin 39, ES7210 Pin 3, ES8311 Pin 19
LCD/Dokunmatik Konnektor Pin 12 -> ESP32 Pin 24
LCD/Dokunmatik Konnektor Pin 13 -> ESP32 Pin 23
LCD/Dokunmatik Konnektor Pin 14 -> 1uF Kondansator C1 Pin 2, 10uF Kondansator C2 Pin 2, 22uF Kondansator C3 Pin 2, 1uF Kondansator C4 Pin 2, 10uF Kondansator C5 Pin 2, 10uF Kondansator C6 Pin 2, 1uF Kondansator C7 Pin 2, 1uF Kondansator C8 Pin 2, 1uF Kondansator C9 Pin 2, 1uF Kondansator C10 Pin 2, 100nF Kondansator C11 Pin 2, 100nF Kondansator C12 Pin 2, 10uF Kondansator C13 Pin 2, USB-C Konnektor Pin 13, USB-C Konnektor Pin 14, USB-C Konnektor Pin A1B12, USB-C Konnektor Pin B1A12, LCD/Dokunmatik Konnektor Pin 15, LCD/Dokunmatik Konnektor Pin 16, LCD/Dokunmatik Konnektor Pin 2, Mikrofon-1 Pin 1, Mikrofon-1 Pin 2, Mikrofon-1 Pin 3, Mikrofon-2 Pin 1, Mikrofon-2 Pin 2, Mikrofon-2 Pin 3, 10k Direnc R3 Pin 2, 5.1k Direnc R4 Pin 1, 5.1k Direnc R5 Pin 2, 10k Direnc R9 Pin 2, ESP32 Pin 1, ESP32 Pin 40, ESP32 Pin 41, AXP2101 Pin 3, AXP2101 Pin 41, ES7210 Pin 1, ES7210 Pin 2, ES7210 Pin 21, ES7210 Pin 33, ES7210 Pin 8, ES8311 Pin 10, ES8311 Pin 21, ES8311 Pin 5, NS4150 Pin 7
LCD/Dokunmatik Konnektor Pin 15 -> 1uF Kondansator C1 Pin 2, 10uF Kondansator C2 Pin 2, 22uF Kondansator C3 Pin 2, 1uF Kondansator C4 Pin 2, 10uF Kondansator C5 Pin 2, 10uF Kondansator C6 Pin 2, 1uF Kondansator C7 Pin 2, 1uF Kondansator C8 Pin 2, 1uF Kondansator C9 Pin 2, 1uF Kondansator C10 Pin 2, 100nF Kondansator C11 Pin 2, 100nF Kondansator C12 Pin 2, 10uF Kondansator C13 Pin 2, USB-C Konnektor Pin 13, USB-C Konnektor Pin 14, USB-C Konnektor Pin A1B12, USB-C Konnektor Pin B1A12, LCD/Dokunmatik Konnektor Pin 14, LCD/Dokunmatik Konnektor Pin 16, LCD/Dokunmatik Konnektor Pin 2, Mikrofon-1 Pin 1, Mikrofon-1 Pin 2, Mikrofon-1 Pin 3, Mikrofon-2 Pin 1, Mikrofon-2 Pin 2, Mikrofon-2 Pin 3, 10k Direnc R3 Pin 2, 5.1k Direnc R4 Pin 1, 5.1k Direnc R5 Pin 2, 10k Direnc R9 Pin 2, ESP32 Pin 1, ESP32 Pin 40, ESP32 Pin 41, AXP2101 Pin 3, AXP2101 Pin 41, ES7210 Pin 1, ES7210 Pin 2, ES7210 Pin 21, ES7210 Pin 33, ES7210 Pin 8, ES8311 Pin 10, ES8311 Pin 21, ES8311 Pin 5, NS4150 Pin 7
LCD/Dokunmatik Konnektor Pin 16 -> 1uF Kondansator C1 Pin 2, 10uF Kondansator C2 Pin 2, 22uF Kondansator C3 Pin 2, 1uF Kondansator C4 Pin 2, 10uF Kondansator C5 Pin 2, 10uF Kondansator C6 Pin 2, 1uF Kondansator C7 Pin 2, 1uF Kondansator C8 Pin 2, 1uF Kondansator C9 Pin 2, 1uF Kondansator C10 Pin 2, 100nF Kondansator C11 Pin 2, 100nF Kondansator C12 Pin 2, 10uF Kondansator C13 Pin 2, USB-C Konnektor Pin 13, USB-C Konnektor Pin 14, USB-C Konnektor Pin A1B12, USB-C Konnektor Pin B1A12, LCD/Dokunmatik Konnektor Pin 14, LCD/Dokunmatik Konnektor Pin 15, LCD/Dokunmatik Konnektor Pin 2, Mikrofon-1 Pin 1, Mikrofon-1 Pin 2, Mikrofon-1 Pin 3, Mikrofon-2 Pin 1, Mikrofon-2 Pin 2, Mikrofon-2 Pin 3, 10k Direnc R3 Pin 2, 5.1k Direnc R4 Pin 1, 5.1k Direnc R5 Pin 2, 10k Direnc R9 Pin 2, ESP32 Pin 1, ESP32 Pin 40, ESP32 Pin 41, AXP2101 Pin 3, AXP2101 Pin 41, ES7210 Pin 1, ES7210 Pin 2, ES7210 Pin 21, ES7210 Pin 33, ES7210 Pin 8, ES8311 Pin 10, ES8311 Pin 21, ES8311 Pin 5, NS4150 Pin 7
LCD/Dokunmatik Konnektor Pin 2 -> 1uF Kondansator C1 Pin 2, 10uF Kondansator C2 Pin 2, 22uF Kondansator C3 Pin 2, 1uF Kondansator C4 Pin 2, 10uF Kondansator C5 Pin 2, 10uF Kondansator C6 Pin 2, 1uF Kondansator C7 Pin 2, 1uF Kondansator C8 Pin 2, 1uF Kondansator C9 Pin 2, 1uF Kondansator C10 Pin 2, 100nF Kondansator C11 Pin 2, 100nF Kondansator C12 Pin 2, 10uF Kondansator C13 Pin 2, USB-C Konnektor Pin 13, USB-C Konnektor Pin 14, USB-C Konnektor Pin A1B12, USB-C Konnektor Pin B1A12, LCD/Dokunmatik Konnektor Pin 14, LCD/Dokunmatik Konnektor Pin 15, LCD/Dokunmatik Konnektor Pin 16, Mikrofon-1 Pin 1, Mikrofon-1 Pin 2, Mikrofon-1 Pin 3, Mikrofon-2 Pin 1, Mikrofon-2 Pin 2, Mikrofon-2 Pin 3, 10k Direnc R3 Pin 2, 5.1k Direnc R4 Pin 1, 5.1k Direnc R5 Pin 2, 10k Direnc R9 Pin 2, ESP32 Pin 1, ESP32 Pin 40, ESP32 Pin 41, AXP2101 Pin 3, AXP2101 Pin 41, ES7210 Pin 1, ES7210 Pin 2, ES7210 Pin 21, ES7210 Pin 33, ES7210 Pin 8, ES8311 Pin 10, ES8311 Pin 21, ES8311 Pin 5, NS4150 Pin 7
LCD/Dokunmatik Konnektor Pin 3 -> ESP32 Pin 5
LCD/Dokunmatik Konnektor Pin 4 -> ESP32 Pin 31
LCD/Dokunmatik Konnektor Pin 5 -> ESP32 Pin 4
LCD/Dokunmatik Konnektor Pin 6 -> ESP32 Pin 7
LCD/Dokunmatik Konnektor Pin 7 -> ESP32 Pin 6
LCD/Dokunmatik Konnektor Pin 8 -> ESP32 Pin 33
LCD/Dokunmatik Konnektor Pin 9 -> NC (Baglanmayacak)
1uH Bobin Pin 1 -> AXP2101 Pin 22
1uH Bobin Pin 2 -> 10uF Kondansator C5 Pin 1, 10k Direnc R1 Pin 2, 10k Direnc R2 Pin 2, 4.7k Direnc R6 Pin 2, 4.7k Direnc R7 Pin 2, 10k Direnc R8 Pin 2, ESP32 Pin 2, AXP2101 Pin 14, AXP2101 Pin 21
Mikrofon-1 Pin 1 -> 1uF Kondansator C1 Pin 2, 10uF Kondansator C2 Pin 2, 22uF Kondansator C3 Pin 2, 1uF Kondansator C4 Pin 2, 10uF Kondansator C5 Pin 2, 10uF Kondansator C6 Pin 2, 1uF Kondansator C7 Pin 2, 1uF Kondansator C8 Pin 2, 1uF Kondansator C9 Pin 2, 1uF Kondansator C10 Pin 2, 100nF Kondansator C11 Pin 2, 100nF Kondansator C12 Pin 2, 10uF Kondansator C13 Pin 2, USB-C Konnektor Pin 13, USB-C Konnektor Pin 14, USB-C Konnektor Pin A1B12, USB-C Konnektor Pin B1A12, LCD/Dokunmatik Konnektor Pin 14, LCD/Dokunmatik Konnektor Pin 15, LCD/Dokunmatik Konnektor Pin 16, LCD/Dokunmatik Konnektor Pin 2, Mikrofon-1 Pin 2, Mikrofon-1 Pin 3, Mikrofon-2 Pin 1, Mikrofon-2 Pin 2, Mikrofon-2 Pin 3, 10k Direnc R3 Pin 2, 5.1k Direnc R4 Pin 1, 5.1k Direnc R5 Pin 2, 10k Direnc R9 Pin 2, ESP32 Pin 1, ESP32 Pin 40, ESP32 Pin 41, AXP2101 Pin 3, AXP2101 Pin 41, ES7210 Pin 1, ES7210 Pin 2, ES7210 Pin 21, ES7210 Pin 33, ES7210 Pin 8, ES8311 Pin 10, ES8311 Pin 21, ES8311 Pin 5, NS4150 Pin 7
Mikrofon-1 Pin 2 -> 1uF Kondansator C1 Pin 2, 10uF Kondansator C2 Pin 2, 22uF Kondansator C3 Pin 2, 1uF Kondansator C4 Pin 2, 10uF Kondansator C5 Pin 2, 10uF Kondansator C6 Pin 2, 1uF Kondansator C7 Pin 2, 1uF Kondansator C8 Pin 2, 1uF Kondansator C9 Pin 2, 1uF Kondansator C10 Pin 2, 100nF Kondansator C11 Pin 2, 100nF Kondansator C12 Pin 2, 10uF Kondansator C13 Pin 2, USB-C Konnektor Pin 13, USB-C Konnektor Pin 14, USB-C Konnektor Pin A1B12, USB-C Konnektor Pin B1A12, LCD/Dokunmatik Konnektor Pin 14, LCD/Dokunmatik Konnektor Pin 15, LCD/Dokunmatik Konnektor Pin 16, LCD/Dokunmatik Konnektor Pin 2, Mikrofon-1 Pin 1, Mikrofon-1 Pin 3, Mikrofon-2 Pin 1, Mikrofon-2 Pin 2, Mikrofon-2 Pin 3, 10k Direnc R3 Pin 2, 5.1k Direnc R4 Pin 1, 5.1k Direnc R5 Pin 2, 10k Direnc R9 Pin 2, ESP32 Pin 1, ESP32 Pin 40, ESP32 Pin 41, AXP2101 Pin 3, AXP2101 Pin 41, ES7210 Pin 1, ES7210 Pin 2, ES7210 Pin 21, ES7210 Pin 33, ES7210 Pin 8, ES8311 Pin 10, ES8311 Pin 21, ES8311 Pin 5, NS4150 Pin 7
Mikrofon-1 Pin 3 -> 1uF Kondansator C1 Pin 2, 10uF Kondansator C2 Pin 2, 22uF Kondansator C3 Pin 2, 1uF Kondansator C4 Pin 2, 10uF Kondansator C5 Pin 2, 10uF Kondansator C6 Pin 2, 1uF Kondansator C7 Pin 2, 1uF Kondansator C8 Pin 2, 1uF Kondansator C9 Pin 2, 1uF Kondansator C10 Pin 2, 100nF Kondansator C11 Pin 2, 100nF Kondansator C12 Pin 2, 10uF Kondansator C13 Pin 2, USB-C Konnektor Pin 13, USB-C Konnektor Pin 14, USB-C Konnektor Pin A1B12, USB-C Konnektor Pin B1A12, LCD/Dokunmatik Konnektor Pin 14, LCD/Dokunmatik Konnektor Pin 15, LCD/Dokunmatik Konnektor Pin 16, LCD/Dokunmatik Konnektor Pin 2, Mikrofon-1 Pin 1, Mikrofon-1 Pin 2, Mikrofon-2 Pin 1, Mikrofon-2 Pin 2, Mikrofon-2 Pin 3, 10k Direnc R3 Pin 2, 5.1k Direnc R4 Pin 1, 5.1k Direnc R5 Pin 2, 10k Direnc R9 Pin 2, ESP32 Pin 1, ESP32 Pin 40, ESP32 Pin 41, AXP2101 Pin 3, AXP2101 Pin 41, ES7210 Pin 1, ES7210 Pin 2, ES7210 Pin 21, ES7210 Pin 33, ES7210 Pin 8, ES8311 Pin 10, ES8311 Pin 21, ES8311 Pin 5, NS4150 Pin 7
Mikrofon-1 Pin 4 -> ES7210 Pin 16
Mikrofon-1 Pin 5 -> NC (Baglanmayacak)
Mikrofon-1 Pin 6 -> Mikrofon-2 Pin 6, ES7210 Pin 24
Mikrofon-2 Pin 1 -> 1uF Kondansator C1 Pin 2, 10uF Kondansator C2 Pin 2, 22uF Kondansator C3 Pin 2, 1uF Kondansator C4 Pin 2, 10uF Kondansator C5 Pin 2, 10uF Kondansator C6 Pin 2, 1uF Kondansator C7 Pin 2, 1uF Kondansator C8 Pin 2, 1uF Kondansator C9 Pin 2, 1uF Kondansator C10 Pin 2, 100nF Kondansator C11 Pin 2, 100nF Kondansator C12 Pin 2, 10uF Kondansator C13 Pin 2, USB-C Konnektor Pin 13, USB-C Konnektor Pin 14, USB-C Konnektor Pin A1B12, USB-C Konnektor Pin B1A12, LCD/Dokunmatik Konnektor Pin 14, LCD/Dokunmatik Konnektor Pin 15, LCD/Dokunmatik Konnektor Pin 16, LCD/Dokunmatik Konnektor Pin 2, Mikrofon-1 Pin 1, Mikrofon-1 Pin 2, Mikrofon-1 Pin 3, Mikrofon-2 Pin 2, Mikrofon-2 Pin 3, 10k Direnc R3 Pin 2, 5.1k Direnc R4 Pin 1, 5.1k Direnc R5 Pin 2, 10k Direnc R9 Pin 2, ESP32 Pin 1, ESP32 Pin 40, ESP32 Pin 41, AXP2101 Pin 3, AXP2101 Pin 41, ES7210 Pin 1, ES7210 Pin 2, ES7210 Pin 21, ES7210 Pin 33, ES7210 Pin 8, ES8311 Pin 10, ES8311 Pin 21, ES8311 Pin 5, NS4150 Pin 7
Mikrofon-2 Pin 2 -> 1uF Kondansator C1 Pin 2, 10uF Kondansator C2 Pin 2, 22uF Kondansator C3 Pin 2, 1uF Kondansator C4 Pin 2, 10uF Kondansator C5 Pin 2, 10uF Kondansator C6 Pin 2, 1uF Kondansator C7 Pin 2, 1uF Kondansator C8 Pin 2, 1uF Kondansator C9 Pin 2, 1uF Kondansator C10 Pin 2, 100nF Kondansator C11 Pin 2, 100nF Kondansator C12 Pin 2, 10uF Kondansator C13 Pin 2, USB-C Konnektor Pin 13, USB-C Konnektor Pin 14, USB-C Konnektor Pin A1B12, USB-C Konnektor Pin B1A12, LCD/Dokunmatik Konnektor Pin 14, LCD/Dokunmatik Konnektor Pin 15, LCD/Dokunmatik Konnektor Pin 16, LCD/Dokunmatik Konnektor Pin 2, Mikrofon-1 Pin 1, Mikrofon-1 Pin 2, Mikrofon-1 Pin 3, Mikrofon-2 Pin 1, Mikrofon-2 Pin 3, 10k Direnc R3 Pin 2, 5.1k Direnc R4 Pin 1, 5.1k Direnc R5 Pin 2, 10k Direnc R9 Pin 2, ESP32 Pin 1, ESP32 Pin 40, ESP32 Pin 41, AXP2101 Pin 3, AXP2101 Pin 41, ES7210 Pin 1, ES7210 Pin 2, ES7210 Pin 21, ES7210 Pin 33, ES7210 Pin 8, ES8311 Pin 10, ES8311 Pin 21, ES8311 Pin 5, NS4150 Pin 7
Mikrofon-2 Pin 3 -> 1uF Kondansator C1 Pin 2, 10uF Kondansator C2 Pin 2, 22uF Kondansator C3 Pin 2, 1uF Kondansator C4 Pin 2, 10uF Kondansator C5 Pin 2, 10uF Kondansator C6 Pin 2, 1uF Kondansator C7 Pin 2, 1uF Kondansator C8 Pin 2, 1uF Kondansator C9 Pin 2, 1uF Kondansator C10 Pin 2, 100nF Kondansator C11 Pin 2, 100nF Kondansator C12 Pin 2, 10uF Kondansator C13 Pin 2, USB-C Konnektor Pin 13, USB-C Konnektor Pin 14, USB-C Konnektor Pin A1B12, USB-C Konnektor Pin B1A12, LCD/Dokunmatik Konnektor Pin 14, LCD/Dokunmatik Konnektor Pin 15, LCD/Dokunmatik Konnektor Pin 16, LCD/Dokunmatik Konnektor Pin 2, Mikrofon-1 Pin 1, Mikrofon-1 Pin 2, Mikrofon-1 Pin 3, Mikrofon-2 Pin 1, Mikrofon-2 Pin 2, 10k Direnc R3 Pin 2, 5.1k Direnc R4 Pin 1, 5.1k Direnc R5 Pin 2, 10k Direnc R9 Pin 2, ESP32 Pin 1, ESP32 Pin 40, ESP32 Pin 41, AXP2101 Pin 3, AXP2101 Pin 41, ES7210 Pin 1, ES7210 Pin 2, ES7210 Pin 21, ES7210 Pin 33, ES7210 Pin 8, ES8311 Pin 10, ES8311 Pin 21, ES8311 Pin 5, NS4150 Pin 7
Mikrofon-2 Pin 4 -> ES7210 Pin 19
Mikrofon-2 Pin 5 -> NC (Baglanmayacak)
Mikrofon-2 Pin 6 -> Mikrofon-1 Pin 6, ES7210 Pin 24
10k Direnc R1 Pin 1 -> ESP32 Pin 27
10k Direnc R1 Pin 2 -> 10uF Kondansator C5 Pin 1, 1uH Bobin Pin 2, 10k Direnc R2 Pin 2, 4.7k Direnc R6 Pin 2, 4.7k Direnc R7 Pin 2, 10k Direnc R8 Pin 2, ESP32 Pin 2, AXP2101 Pin 14, AXP2101 Pin 21
10k Direnc R2 Pin 1 -> 1uF Kondansator C1 Pin 1, ESP32 Pin 3, AXP2101 Pin 29
10k Direnc R2 Pin 2 -> 10uF Kondansator C5 Pin 1, 1uH Bobin Pin 2, 10k Direnc R1 Pin 2, 4.7k Direnc R6 Pin 2, 4.7k Direnc R7 Pin 2, 10k Direnc R8 Pin 2, ESP32 Pin 2, AXP2101 Pin 14, AXP2101 Pin 21
10k Direnc R3 Pin 1 -> ESP32 Pin 16, NS4150 Pin 1
10k Direnc R3 Pin 2 -> 1uF Kondansator C1 Pin 2, 10uF Kondansator C2 Pin 2, 22uF Kondansator C3 Pin 2, 1uF Kondansator C4 Pin 2, 10uF Kondansator C5 Pin 2, 10uF Kondansator C6 Pin 2, 1uF Kondansator C7 Pin 2, 1uF Kondansator C8 Pin 2, 1uF Kondansator C9 Pin 2, 1uF Kondansator C10 Pin 2, 100nF Kondansator C11 Pin 2, 100nF Kondansator C12 Pin 2, 10uF Kondansator C13 Pin 2, USB-C Konnektor Pin 13, USB-C Konnektor Pin 14, USB-C Konnektor Pin A1B12, USB-C Konnektor Pin B1A12, LCD/Dokunmatik Konnektor Pin 14, LCD/Dokunmatik Konnektor Pin 15, LCD/Dokunmatik Konnektor Pin 16, LCD/Dokunmatik Konnektor Pin 2, Mikrofon-1 Pin 1, Mikrofon-1 Pin 2, Mikrofon-1 Pin 3, Mikrofon-2 Pin 1, Mikrofon-2 Pin 2, Mikrofon-2 Pin 3, 5.1k Direnc R4 Pin 1, 5.1k Direnc R5 Pin 2, 10k Direnc R9 Pin 2, ESP32 Pin 1, ESP32 Pin 40, ESP32 Pin 41, AXP2101 Pin 3, AXP2101 Pin 41, ES7210 Pin 1, ES7210 Pin 2, ES7210 Pin 21, ES7210 Pin 33, ES7210 Pin 8, ES8311 Pin 10, ES8311 Pin 21, ES8311 Pin 5, NS4150 Pin 7
5.1k Direnc R4 Pin 1 -> 1uF Kondansator C1 Pin 2, 10uF Kondansator C2 Pin 2, 22uF Kondansator C3 Pin 2, 1uF Kondansator C4 Pin 2, 10uF Kondansator C5 Pin 2, 10uF Kondansator C6 Pin 2, 1uF Kondansator C7 Pin 2, 1uF Kondansator C8 Pin 2, 1uF Kondansator C9 Pin 2, 1uF Kondansator C10 Pin 2, 100nF Kondansator C11 Pin 2, 100nF Kondansator C12 Pin 2, 10uF Kondansator C13 Pin 2, USB-C Konnektor Pin 13, USB-C Konnektor Pin 14, USB-C Konnektor Pin A1B12, USB-C Konnektor Pin B1A12, LCD/Dokunmatik Konnektor Pin 14, LCD/Dokunmatik Konnektor Pin 15, LCD/Dokunmatik Konnektor Pin 16, LCD/Dokunmatik Konnektor Pin 2, Mikrofon-1 Pin 1, Mikrofon-1 Pin 2, Mikrofon-1 Pin 3, Mikrofon-2 Pin 1, Mikrofon-2 Pin 2, Mikrofon-2 Pin 3, 10k Direnc R3 Pin 2, 5.1k Direnc R5 Pin 2, 10k Direnc R9 Pin 2, ESP32 Pin 1, ESP32 Pin 40, ESP32 Pin 41, AXP2101 Pin 3, AXP2101 Pin 41, ES7210 Pin 1, ES7210 Pin 2, ES7210 Pin 21, ES7210 Pin 33, ES7210 Pin 8, ES8311 Pin 10, ES8311 Pin 21, ES8311 Pin 5, NS4150 Pin 7
5.1k Direnc R4 Pin 2 -> USB-C Konnektor Pin A5
5.1k Direnc R5 Pin 1 -> USB-C Konnektor Pin B5
5.1k Direnc R5 Pin 2 -> 1uF Kondansator C1 Pin 2, 10uF Kondansator C2 Pin 2, 22uF Kondansator C3 Pin 2, 1uF Kondansator C4 Pin 2, 10uF Kondansator C5 Pin 2, 10uF Kondansator C6 Pin 2, 1uF Kondansator C7 Pin 2, 1uF Kondansator C8 Pin 2, 1uF Kondansator C9 Pin 2, 1uF Kondansator C10 Pin 2, 100nF Kondansator C11 Pin 2, 100nF Kondansator C12 Pin 2, 10uF Kondansator C13 Pin 2, USB-C Konnektor Pin 13, USB-C Konnektor Pin 14, USB-C Konnektor Pin A1B12, USB-C Konnektor Pin B1A12, LCD/Dokunmatik Konnektor Pin 14, LCD/Dokunmatik Konnektor Pin 15, LCD/Dokunmatik Konnektor Pin 16, LCD/Dokunmatik Konnektor Pin 2, Mikrofon-1 Pin 1, Mikrofon-1 Pin 2, Mikrofon-1 Pin 3, Mikrofon-2 Pin 1, Mikrofon-2 Pin 2, Mikrofon-2 Pin 3, 10k Direnc R3 Pin 2, 5.1k Direnc R4 Pin 1, 10k Direnc R9 Pin 2, ESP32 Pin 1, ESP32 Pin 40, ESP32 Pin 41, AXP2101 Pin 3, AXP2101 Pin 41, ES7210 Pin 1, ES7210 Pin 2, ES7210 Pin 21, ES7210 Pin 33, ES7210 Pin 8, ES8311 Pin 10, ES8311 Pin 21, ES8311 Pin 5, NS4150 Pin 7
4.7k Direnc R6 Pin 1 -> LCD/Dokunmatik Konnektor Pin 11, ESP32 Pin 8, AXP2101 Pin 39, ES7210 Pin 3, ES8311 Pin 19
4.7k Direnc R6 Pin 2 -> 10uF Kondansator C5 Pin 1, 1uH Bobin Pin 2, 10k Direnc R1 Pin 2, 10k Direnc R2 Pin 2, 4.7k Direnc R7 Pin 2, 10k Direnc R8 Pin 2, ESP32 Pin 2, AXP2101 Pin 14, AXP2101 Pin 21
4.7k Direnc R7 Pin 1 -> LCD/Dokunmatik Konnektor Pin 10, ESP32 Pin 22, AXP2101 Pin 40, ES7210 Pin 4, ES8311 Pin 1
4.7k Direnc R7 Pin 2 -> 10uF Kondansator C5 Pin 1, 1uH Bobin Pin 2, 10k Direnc R1 Pin 2, 10k Direnc R2 Pin 2, 4.7k Direnc R6 Pin 2, 10k Direnc R8 Pin 2, ESP32 Pin 2, AXP2101 Pin 14, AXP2101 Pin 21
10k Direnc R8 Pin 1 -> ESP32 Pin 25, AXP2101 Pin 38
10k Direnc R8 Pin 2 -> 10uF Kondansator C5 Pin 1, 1uH Bobin Pin 2, 10k Direnc R1 Pin 2, 10k Direnc R2 Pin 2, 4.7k Direnc R6 Pin 2, 4.7k Direnc R7 Pin 2, ESP32 Pin 2, AXP2101 Pin 14, AXP2101 Pin 21
10k Direnc R9 Pin 1 -> AXP2101 Pin 31
10k Direnc R9 Pin 2 -> 1uF Kondansator C1 Pin 2, 10uF Kondansator C2 Pin 2, 22uF Kondansator C3 Pin 2, 1uF Kondansator C4 Pin 2, 10uF Kondansator C5 Pin 2, 10uF Kondansator C6 Pin 2, 1uF Kondansator C7 Pin 2, 1uF Kondansator C8 Pin 2, 1uF Kondansator C9 Pin 2, 1uF Kondansator C10 Pin 2, 100nF Kondansator C11 Pin 2, 100nF Kondansator C12 Pin 2, 10uF Kondansator C13 Pin 2, USB-C Konnektor Pin 13, USB-C Konnektor Pin 14, USB-C Konnektor Pin A1B12, USB-C Konnektor Pin B1A12, LCD/Dokunmatik Konnektor Pin 14, LCD/Dokunmatik Konnektor Pin 15, LCD/Dokunmatik Konnektor Pin 16, LCD/Dokunmatik Konnektor Pin 2, Mikrofon-1 Pin 1, Mikrofon-1 Pin 2, Mikrofon-1 Pin 3, Mikrofon-2 Pin 1, Mikrofon-2 Pin 2, Mikrofon-2 Pin 3, 10k Direnc R3 Pin 2, 5.1k Direnc R4 Pin 1, 5.1k Direnc R5 Pin 2, ESP32 Pin 1, ESP32 Pin 40, ESP32 Pin 41, AXP2101 Pin 3, AXP2101 Pin 41, ES7210 Pin 1, ES7210 Pin 2, ES7210 Pin 21, ES7210 Pin 33, ES7210 Pin 8, ES8311 Pin 10, ES8311 Pin 21, ES8311 Pin 5, NS4150 Pin 7
ESP32 Pin 1 -> 1uF Kondansator C1 Pin 2, 10uF Kondansator C2 Pin 2, 22uF Kondansator C3 Pin 2, 1uF Kondansator C4 Pin 2, 10uF Kondansator C5 Pin 2, 10uF Kondansator C6 Pin 2, 1uF Kondansator C7 Pin 2, 1uF Kondansator C8 Pin 2, 1uF Kondansator C9 Pin 2, 1uF Kondansator C10 Pin 2, 100nF Kondansator C11 Pin 2, 100nF Kondansator C12 Pin 2, 10uF Kondansator C13 Pin 2, USB-C Konnektor Pin 13, USB-C Konnektor Pin 14, USB-C Konnektor Pin A1B12, USB-C Konnektor Pin B1A12, LCD/Dokunmatik Konnektor Pin 14, LCD/Dokunmatik Konnektor Pin 15, LCD/Dokunmatik Konnektor Pin 16, LCD/Dokunmatik Konnektor Pin 2, Mikrofon-1 Pin 1, Mikrofon-1 Pin 2, Mikrofon-1 Pin 3, Mikrofon-2 Pin 1, Mikrofon-2 Pin 2, Mikrofon-2 Pin 3, 10k Direnc R3 Pin 2, 5.1k Direnc R4 Pin 1, 5.1k Direnc R5 Pin 2, 10k Direnc R9 Pin 2, ESP32 Pin 40, ESP32 Pin 41, AXP2101 Pin 3, AXP2101 Pin 41, ES7210 Pin 1, ES7210 Pin 2, ES7210 Pin 21, ES7210 Pin 33, ES7210 Pin 8, ES8311 Pin 10, ES8311 Pin 21, ES8311 Pin 5, NS4150 Pin 7
ESP32 Pin 10 -> NC (Baglanmayacak)
ESP32 Pin 11 -> NC (Baglanmayacak)
ESP32 Pin 12 -> ES8311 Pin 9
ESP32 Pin 13 -> USB-C Konnektor Pin A7, USB-C Konnektor Pin B7
ESP32 Pin 14 -> USB-C Konnektor Pin A6, USB-C Konnektor Pin B6
ESP32 Pin 15 -> NC (Baglanmayacak)
ESP32 Pin 16 -> 10k Direnc R3 Pin 1, NS4150 Pin 1
ESP32 Pin 17 -> ES7210 Pin 9, ES8311 Pin 6
ESP32 Pin 18 -> ES7210 Pin 11
ESP32 Pin 19 -> NC (Baglanmayacak)
ESP32 Pin 2 -> 10uF Kondansator C5 Pin 1, 1uH Bobin Pin 2, 10k Direnc R1 Pin 2, 10k Direnc R2 Pin 2, 4.7k Direnc R6 Pin 2, 4.7k Direnc R7 Pin 2, 10k Direnc R8 Pin 2, AXP2101 Pin 14, AXP2101 Pin 21
ESP32 Pin 20 -> NC (Baglanmayacak)
ESP32 Pin 21 -> NC (Baglanmayacak)
ESP32 Pin 22 -> LCD/Dokunmatik Konnektor Pin 10, 4.7k Direnc R7 Pin 1, AXP2101 Pin 40, ES7210 Pin 4, ES8311 Pin 1
ESP32 Pin 23 -> LCD/Dokunmatik Konnektor Pin 13
ESP32 Pin 24 -> LCD/Dokunmatik Konnektor Pin 12
ESP32 Pin 25 -> 10k Direnc R8 Pin 1, AXP2101 Pin 38
ESP32 Pin 26 -> ES7210 Pin 10, ES8311 Pin 8
ESP32 Pin 27 -> 10k Direnc R1 Pin 1
ESP32 Pin 28 -> NC (Baglanmayacak)
ESP32 Pin 29 -> NC (Baglanmayacak)
ESP32 Pin 3 -> 1uF Kondansator C1 Pin 1, 10k Direnc R2 Pin 1, AXP2101 Pin 29
ESP32 Pin 30 -> NC (Baglanmayacak)
ESP32 Pin 31 -> LCD/Dokunmatik Konnektor Pin 4
ESP32 Pin 32 -> NC (Baglanmayacak)
ESP32 Pin 33 -> LCD/Dokunmatik Konnektor Pin 8
ESP32 Pin 34 -> NC (Baglanmayacak)
ESP32 Pin 35 -> NC (Baglanmayacak)
ESP32 Pin 36 -> UART_RXD Hatti (Tek Uclu)
ESP32 Pin 37 -> UART_TXD Hatti (Tek Uclu)
ESP32 Pin 38 -> NC (Baglanmayacak)
ESP32 Pin 39 -> NC (Baglanmayacak)
ESP32 Pin 4 -> LCD/Dokunmatik Konnektor Pin 5
ESP32 Pin 40 -> 1uF Kondansator C1 Pin 2, 10uF Kondansator C2 Pin 2, 22uF Kondansator C3 Pin 2, 1uF Kondansator C4 Pin 2, 10uF Kondansator C5 Pin 2, 10uF Kondansator C6 Pin 2, 1uF Kondansator C7 Pin 2, 1uF Kondansator C8 Pin 2, 1uF Kondansator C9 Pin 2, 1uF Kondansator C10 Pin 2, 100nF Kondansator C11 Pin 2, 100nF Kondansator C12 Pin 2, 10uF Kondansator C13 Pin 2, USB-C Konnektor Pin 13, USB-C Konnektor Pin 14, USB-C Konnektor Pin A1B12, USB-C Konnektor Pin B1A12, LCD/Dokunmatik Konnektor Pin 14, LCD/Dokunmatik Konnektor Pin 15, LCD/Dokunmatik Konnektor Pin 16, LCD/Dokunmatik Konnektor Pin 2, Mikrofon-1 Pin 1, Mikrofon-1 Pin 2, Mikrofon-1 Pin 3, Mikrofon-2 Pin 1, Mikrofon-2 Pin 2, Mikrofon-2 Pin 3, 10k Direnc R3 Pin 2, 5.1k Direnc R4 Pin 1, 5.1k Direnc R5 Pin 2, 10k Direnc R9 Pin 2, ESP32 Pin 1, ESP32 Pin 41, AXP2101 Pin 3, AXP2101 Pin 41, ES7210 Pin 1, ES7210 Pin 2, ES7210 Pin 21, ES7210 Pin 33, ES7210 Pin 8, ES8311 Pin 10, ES8311 Pin 21, ES8311 Pin 5, NS4150 Pin 7
ESP32 Pin 41 -> 1uF Kondansator C1 Pin 2, 10uF Kondansator C2 Pin 2, 22uF Kondansator C3 Pin 2, 1uF Kondansator C4 Pin 2, 10uF Kondansator C5 Pin 2, 10uF Kondansator C6 Pin 2, 1uF Kondansator C7 Pin 2, 1uF Kondansator C8 Pin 2, 1uF Kondansator C9 Pin 2, 1uF Kondansator C10 Pin 2, 100nF Kondansator C11 Pin 2, 100nF Kondansator C12 Pin 2, 10uF Kondansator C13 Pin 2, USB-C Konnektor Pin 13, USB-C Konnektor Pin 14, USB-C Konnektor Pin A1B12, USB-C Konnektor Pin B1A12, LCD/Dokunmatik Konnektor Pin 14, LCD/Dokunmatik Konnektor Pin 15, LCD/Dokunmatik Konnektor Pin 16, LCD/Dokunmatik Konnektor Pin 2, Mikrofon-1 Pin 1, Mikrofon-1 Pin 2, Mikrofon-1 Pin 3, Mikrofon-2 Pin 1, Mikrofon-2 Pin 2, Mikrofon-2 Pin 3, 10k Direnc R3 Pin 2, 5.1k Direnc R4 Pin 1, 5.1k Direnc R5 Pin 2, 10k Direnc R9 Pin 2, ESP32 Pin 1, ESP32 Pin 40, AXP2101 Pin 3, AXP2101 Pin 41, ES7210 Pin 1, ES7210 Pin 2, ES7210 Pin 21, ES7210 Pin 33, ES7210 Pin 8, ES8311 Pin 10, ES8311 Pin 21, ES8311 Pin 5, NS4150 Pin 7
ESP32 Pin 5 -> LCD/Dokunmatik Konnektor Pin 3
ESP32 Pin 6 -> LCD/Dokunmatik Konnektor Pin 7
ESP32 Pin 7 -> LCD/Dokunmatik Konnektor Pin 6
ESP32 Pin 8 -> LCD/Dokunmatik Konnektor Pin 11, 4.7k Direnc R6 Pin 1, AXP2101 Pin 39, ES7210 Pin 3, ES8311 Pin 19
ESP32 Pin 9 -> ES7210 Pin 5, ES8311 Pin 2
AXP2101 Pin 1 -> NC (Baglanmayacak)
AXP2101 Pin 10 -> NC (Baglanmayacak)
AXP2101 Pin 11 -> NC (Baglanmayacak)
AXP2101 Pin 12 -> 1uF Kondansator C10 Pin 1
AXP2101 Pin 13 -> 22uF Kondansator C3 Pin 1, AXP2101 Pin 17, AXP2101 Pin 23, AXP2101 Pin 24, AXP2101 Pin 34, AXP2101 Pin 6, AXP2101 Pin 7
AXP2101 Pin 14 -> 10uF Kondansator C5 Pin 1, 1uH Bobin Pin 2, 10k Direnc R1 Pin 2, 10k Direnc R2 Pin 2, 4.7k Direnc R6 Pin 2, 4.7k Direnc R7 Pin 2, 10k Direnc R8 Pin 2, ESP32 Pin 2, AXP2101 Pin 21
AXP2101 Pin 15 -> NC (Baglanmayacak)
AXP2101 Pin 16 -> 1uF Kondansator C9 Pin 1, LCD/Dokunmatik Konnektor Pin 1
AXP2101 Pin 17 -> 22uF Kondansator C3 Pin 1, AXP2101 Pin 13, AXP2101 Pin 23, AXP2101 Pin 24, AXP2101 Pin 34, AXP2101 Pin 6, AXP2101 Pin 7
AXP2101 Pin 18 -> 1uF Kondansator C7 Pin 1, 100nF Kondansator C12 Pin 1, ES8311 Pin 11, ES8311 Pin 20, ES8311 Pin 3, ES8311 Pin 4
AXP2101 Pin 19 -> 1uF Kondansator C8 Pin 1, 100nF Kondansator C11 Pin 1, ES7210 Pin 22, ES7210 Pin 23, ES7210 Pin 6, ES7210 Pin 7
AXP2101 Pin 2 -> AXP_VREF Hatti (Tek Uclu)
AXP2101 Pin 20 -> NC (Baglanmayacak)
AXP2101 Pin 21 -> 10uF Kondansator C5 Pin 1, 1uH Bobin Pin 2, 10k Direnc R1 Pin 2, 10k Direnc R2 Pin 2, 4.7k Direnc R6 Pin 2, 4.7k Direnc R7 Pin 2, 10k Direnc R8 Pin 2, ESP32 Pin 2, AXP2101 Pin 14
AXP2101 Pin 22 -> 1uH Bobin Pin 1
AXP2101 Pin 23 -> 22uF Kondansator C3 Pin 1, AXP2101 Pin 13, AXP2101 Pin 17, AXP2101 Pin 24, AXP2101 Pin 34, AXP2101 Pin 6, AXP2101 Pin 7
AXP2101 Pin 24 -> 22uF Kondansator C3 Pin 1, AXP2101 Pin 13, AXP2101 Pin 17, AXP2101 Pin 23, AXP2101 Pin 34, AXP2101 Pin 6, AXP2101 Pin 7
AXP2101 Pin 25 -> NC (Baglanmayacak)
AXP2101 Pin 26 -> NC (Baglanmayacak)
AXP2101 Pin 27 -> NC (Baglanmayacak)
AXP2101 Pin 28 -> NC (Baglanmayacak)
AXP2101 Pin 29 -> 1uF Kondansator C1 Pin 1, 10k Direnc R2 Pin 1, ESP32 Pin 3
AXP2101 Pin 3 -> 1uF Kondansator C1 Pin 2, 10uF Kondansator C2 Pin 2, 22uF Kondansator C3 Pin 2, 1uF Kondansator C4 Pin 2, 10uF Kondansator C5 Pin 2, 10uF Kondansator C6 Pin 2, 1uF Kondansator C7 Pin 2, 1uF Kondansator C8 Pin 2, 1uF Kondansator C9 Pin 2, 1uF Kondansator C10 Pin 2, 100nF Kondansator C11 Pin 2, 100nF Kondansator C12 Pin 2, 10uF Kondansator C13 Pin 2, USB-C Konnektor Pin 13, USB-C Konnektor Pin 14, USB-C Konnektor Pin A1B12, USB-C Konnektor Pin B1A12, LCD/Dokunmatik Konnektor Pin 14, LCD/Dokunmatik Konnektor Pin 15, LCD/Dokunmatik Konnektor Pin 16, LCD/Dokunmatik Konnektor Pin 2, Mikrofon-1 Pin 1, Mikrofon-1 Pin 2, Mikrofon-1 Pin 3, Mikrofon-2 Pin 1, Mikrofon-2 Pin 2, Mikrofon-2 Pin 3, 10k Direnc R3 Pin 2, 5.1k Direnc R4 Pin 1, 5.1k Direnc R5 Pin 2, 10k Direnc R9 Pin 2, ESP32 Pin 1, ESP32 Pin 40, ESP32 Pin 41, AXP2101 Pin 41, ES7210 Pin 1, ES7210 Pin 2, ES7210 Pin 21, ES7210 Pin 33, ES7210 Pin 8, ES8311 Pin 10, ES8311 Pin 21, ES8311 Pin 5, NS4150 Pin 7
AXP2101 Pin 30 -> PWRON Hatti (Tek Uclu)
AXP2101 Pin 31 -> 10k Direnc R9 Pin 1
AXP2101 Pin 32 -> NC (Baglanmayacak)
AXP2101 Pin 33 -> 1uF Kondansator C4 Pin 1, 10uF Kondansator C13 Pin 1, NS4150 Pin 6
AXP2101 Pin 34 -> 22uF Kondansator C3 Pin 1, AXP2101 Pin 13, AXP2101 Pin 17, AXP2101 Pin 23, AXP2101 Pin 24, AXP2101 Pin 6, AXP2101 Pin 7
AXP2101 Pin 35 -> NC (Baglanmayacak)
AXP2101 Pin 36 -> AXP_VMID Hatti (Tek Uclu)
AXP2101 Pin 37 -> 10uF Kondansator C2 Pin 1, 10uF Kondansator C6 Pin 1, USB-C Konnektor Pin A4B9, USB-C Konnektor Pin B4A9
AXP2101 Pin 38 -> 10k Direnc R8 Pin 1, ESP32 Pin 25
AXP2101 Pin 39 -> LCD/Dokunmatik Konnektor Pin 11, 4.7k Direnc R6 Pin 1, ESP32 Pin 8, ES7210 Pin 3, ES8311 Pin 19
AXP2101 Pin 4 -> NC (Baglanmayacak)
AXP2101 Pin 40 -> LCD/Dokunmatik Konnektor Pin 10, 4.7k Direnc R7 Pin 1, ESP32 Pin 22, ES7210 Pin 4, ES8311 Pin 1
AXP2101 Pin 41 -> 1uF Kondansator C1 Pin 2, 10uF Kondansator C2 Pin 2, 22uF Kondansator C3 Pin 2, 1uF Kondansator C4 Pin 2, 10uF Kondansator C5 Pin 2, 10uF Kondansator C6 Pin 2, 1uF Kondansator C7 Pin 2, 1uF Kondansator C8 Pin 2, 1uF Kondansator C9 Pin 2, 1uF Kondansator C10 Pin 2, 100nF Kondansator C11 Pin 2, 100nF Kondansator C12 Pin 2, 10uF Kondansator C13 Pin 2, USB-C Konnektor Pin 13, USB-C Konnektor Pin 14, USB-C Konnektor Pin A1B12, USB-C Konnektor Pin B1A12, LCD/Dokunmatik Konnektor Pin 14, LCD/Dokunmatik Konnektor Pin 15, LCD/Dokunmatik Konnektor Pin 16, LCD/Dokunmatik Konnektor Pin 2, Mikrofon-1 Pin 1, Mikrofon-1 Pin 2, Mikrofon-1 Pin 3, Mikrofon-2 Pin 1, Mikrofon-2 Pin 2, Mikrofon-2 Pin 3, 10k Direnc R3 Pin 2, 5.1k Direnc R4 Pin 1, 5.1k Direnc R5 Pin 2, 10k Direnc R9 Pin 2, ESP32 Pin 1, ESP32 Pin 40, ESP32 Pin 41, AXP2101 Pin 3, ES7210 Pin 1, ES7210 Pin 2, ES7210 Pin 21, ES7210 Pin 33, ES7210 Pin 8, ES8311 Pin 10, ES8311 Pin 21, ES8311 Pin 5, NS4150 Pin 7
AXP2101 Pin 5 -> NC (Baglanmayacak)
AXP2101 Pin 6 -> 22uF Kondansator C3 Pin 1, AXP2101 Pin 13, AXP2101 Pin 17, AXP2101 Pin 23, AXP2101 Pin 24, AXP2101 Pin 34, AXP2101 Pin 7
AXP2101 Pin 7 -> 22uF Kondansator C3 Pin 1, AXP2101 Pin 13, AXP2101 Pin 17, AXP2101 Pin 23, AXP2101 Pin 24, AXP2101 Pin 34, AXP2101 Pin 6
AXP2101 Pin 8 -> NC (Baglanmayacak)
AXP2101 Pin 9 -> NC (Baglanmayacak)
ES7210 Pin 1 -> 1uF Kondansator C1 Pin 2, 10uF Kondansator C2 Pin 2, 22uF Kondansator C3 Pin 2, 1uF Kondansator C4 Pin 2, 10uF Kondansator C5 Pin 2, 10uF Kondansator C6 Pin 2, 1uF Kondansator C7 Pin 2, 1uF Kondansator C8 Pin 2, 1uF Kondansator C9 Pin 2, 1uF Kondansator C10 Pin 2, 100nF Kondansator C11 Pin 2, 100nF Kondansator C12 Pin 2, 10uF Kondansator C13 Pin 2, USB-C Konnektor Pin 13, USB-C Konnektor Pin 14, USB-C Konnektor Pin A1B12, USB-C Konnektor Pin B1A12, LCD/Dokunmatik Konnektor Pin 14, LCD/Dokunmatik Konnektor Pin 15, LCD/Dokunmatik Konnektor Pin 16, LCD/Dokunmatik Konnektor Pin 2, Mikrofon-1 Pin 1, Mikrofon-1 Pin 2, Mikrofon-1 Pin 3, Mikrofon-2 Pin 1, Mikrofon-2 Pin 2, Mikrofon-2 Pin 3, 10k Direnc R3 Pin 2, 5.1k Direnc R4 Pin 1, 5.1k Direnc R5 Pin 2, 10k Direnc R9 Pin 2, ESP32 Pin 1, ESP32 Pin 40, ESP32 Pin 41, AXP2101 Pin 3, AXP2101 Pin 41, ES7210 Pin 2, ES7210 Pin 21, ES7210 Pin 33, ES7210 Pin 8, ES8311 Pin 10, ES8311 Pin 21, ES8311 Pin 5, NS4150 Pin 7
ES7210 Pin 10 -> ESP32 Pin 26, ES8311 Pin 8
ES7210 Pin 11 -> ESP32 Pin 18
ES7210 Pin 12 -> NC (Baglanmayacak)
ES7210 Pin 13 -> NC (Baglanmayacak)
ES7210 Pin 14 -> NC (Baglanmayacak)
ES7210 Pin 15 -> MIC1N Hatti (Tek Uclu)
ES7210 Pin 16 -> Mikrofon-1 Pin 4
ES7210 Pin 17 -> ES7210_REFP12 Hatti (Tek Uclu)
ES7210 Pin 18 -> ES7210_REFQ12 Hatti (Tek Uclu)
ES7210 Pin 19 -> Mikrofon-2 Pin 4
ES7210 Pin 2 -> 1uF Kondansator C1 Pin 2, 10uF Kondansator C2 Pin 2, 22uF Kondansator C3 Pin 2, 1uF Kondansator C4 Pin 2, 10uF Kondansator C5 Pin 2, 10uF Kondansator C6 Pin 2, 1uF Kondansator C7 Pin 2, 1uF Kondansator C8 Pin 2, 1uF Kondansator C9 Pin 2, 1uF Kondansator C10 Pin 2, 100nF Kondansator C11 Pin 2, 100nF Kondansator C12 Pin 2, 10uF Kondansator C13 Pin 2, USB-C Konnektor Pin 13, USB-C Konnektor Pin 14, USB-C Konnektor Pin A1B12, USB-C Konnektor Pin B1A12, LCD/Dokunmatik Konnektor Pin 14, LCD/Dokunmatik Konnektor Pin 15, LCD/Dokunmatik Konnektor Pin 16, LCD/Dokunmatik Konnektor Pin 2, Mikrofon-1 Pin 1, Mikrofon-1 Pin 2, Mikrofon-1 Pin 3, Mikrofon-2 Pin 1, Mikrofon-2 Pin 2, Mikrofon-2 Pin 3, 10k Direnc R3 Pin 2, 5.1k Direnc R4 Pin 1, 5.1k Direnc R5 Pin 2, 10k Direnc R9 Pin 2, ESP32 Pin 1, ESP32 Pin 40, ESP32 Pin 41, AXP2101 Pin 3, AXP2101 Pin 41, ES7210 Pin 1, ES7210 Pin 21, ES7210 Pin 33, ES7210 Pin 8, ES8311 Pin 10, ES8311 Pin 21, ES8311 Pin 5, NS4150 Pin 7
ES7210 Pin 20 -> MIC2N Hatti (Tek Uclu)
ES7210 Pin 21 -> 1uF Kondansator C1 Pin 2, 10uF Kondansator C2 Pin 2, 22uF Kondansator C3 Pin 2, 1uF Kondansator C4 Pin 2, 10uF Kondansator C5 Pin 2, 10uF Kondansator C6 Pin 2, 1uF Kondansator C7 Pin 2, 1uF Kondansator C8 Pin 2, 1uF Kondansator C9 Pin 2, 1uF Kondansator C10 Pin 2, 100nF Kondansator C11 Pin 2, 100nF Kondansator C12 Pin 2, 10uF Kondansator C13 Pin 2, USB-C Konnektor Pin 13, USB-C Konnektor Pin 14, USB-C Konnektor Pin A1B12, USB-C Konnektor Pin B1A12, LCD/Dokunmatik Konnektor Pin 14, LCD/Dokunmatik Konnektor Pin 15, LCD/Dokunmatik Konnektor Pin 16, LCD/Dokunmatik Konnektor Pin 2, Mikrofon-1 Pin 1, Mikrofon-1 Pin 2, Mikrofon-1 Pin 3, Mikrofon-2 Pin 1, Mikrofon-2 Pin 2, Mikrofon-2 Pin 3, 10k Direnc R3 Pin 2, 5.1k Direnc R4 Pin 1, 5.1k Direnc R5 Pin 2, 10k Direnc R9 Pin 2, ESP32 Pin 1, ESP32 Pin 40, ESP32 Pin 41, AXP2101 Pin 3, AXP2101 Pin 41, ES7210 Pin 1, ES7210 Pin 2, ES7210 Pin 33, ES7210 Pin 8, ES8311 Pin 10, ES8311 Pin 21, ES8311 Pin 5, NS4150 Pin 7
ES7210 Pin 22 -> 1uF Kondansator C8 Pin 1, 100nF Kondansator C11 Pin 1, AXP2101 Pin 19, ES7210 Pin 23, ES7210 Pin 6, ES7210 Pin 7
ES7210 Pin 23 -> 1uF Kondansator C8 Pin 1, 100nF Kondansator C11 Pin 1, AXP2101 Pin 19, ES7210 Pin 22, ES7210 Pin 6, ES7210 Pin 7
ES7210 Pin 24 -> Mikrofon-1 Pin 6, Mikrofon-2 Pin 6
ES7210 Pin 25 -> ES7210_REFQM Hatti (Tek Uclu)
ES7210 Pin 26 -> NC (Baglanmayacak)
ES7210 Pin 27 -> NC (Baglanmayacak)
ES7210 Pin 28 -> NC (Baglanmayacak)
ES7210 Pin 29 -> NC (Baglanmayacak)
ES7210 Pin 3 -> LCD/Dokunmatik Konnektor Pin 11, 4.7k Direnc R6 Pin 1, ESP32 Pin 8, AXP2101 Pin 39, ES8311 Pin 19
ES7210 Pin 30 -> NC (Baglanmayacak)
ES7210 Pin 31 -> AEC_P Hatti (Tek Uclu)
ES7210 Pin 32 -> AEC_N Hatti (Tek Uclu)
ES7210 Pin 33 -> 1uF Kondansator C1 Pin 2, 10uF Kondansator C2 Pin 2, 22uF Kondansator C3 Pin 2, 1uF Kondansator C4 Pin 2, 10uF Kondansator C5 Pin 2, 10uF Kondansator C6 Pin 2, 1uF Kondansator C7 Pin 2, 1uF Kondansator C8 Pin 2, 1uF Kondansator C9 Pin 2, 1uF Kondansator C10 Pin 2, 100nF Kondansator C11 Pin 2, 100nF Kondansator C12 Pin 2, 10uF Kondansator C13 Pin 2, USB-C Konnektor Pin 13, USB-C Konnektor Pin 14, USB-C Konnektor Pin A1B12, USB-C Konnektor Pin B1A12, LCD/Dokunmatik Konnektor Pin 14, LCD/Dokunmatik Konnektor Pin 15, LCD/Dokunmatik Konnektor Pin 16, LCD/Dokunmatik Konnektor Pin 2, Mikrofon-1 Pin 1, Mikrofon-1 Pin 2, Mikrofon-1 Pin 3, Mikrofon-2 Pin 1, Mikrofon-2 Pin 2, Mikrofon-2 Pin 3, 10k Direnc R3 Pin 2, 5.1k Direnc R4 Pin 1, 5.1k Direnc R5 Pin 2, 10k Direnc R9 Pin 2, ESP32 Pin 1, ESP32 Pin 40, ESP32 Pin 41, AXP2101 Pin 3, AXP2101 Pin 41, ES7210 Pin 1, ES7210 Pin 2, ES7210 Pin 21, ES7210 Pin 8, ES8311 Pin 10, ES8311 Pin 21, ES8311 Pin 5, NS4150 Pin 7
ES7210 Pin 4 -> LCD/Dokunmatik Konnektor Pin 10, 4.7k Direnc R7 Pin 1, ESP32 Pin 22, AXP2101 Pin 40, ES8311 Pin 1
ES7210 Pin 5 -> ESP32 Pin 9, ES8311 Pin 2
ES7210 Pin 6 -> 1uF Kondansator C8 Pin 1, 100nF Kondansator C11 Pin 1, AXP2101 Pin 19, ES7210 Pin 22, ES7210 Pin 23, ES7210 Pin 7
ES7210 Pin 7 -> 1uF Kondansator C8 Pin 1, 100nF Kondansator C11 Pin 1, AXP2101 Pin 19, ES7210 Pin 22, ES7210 Pin 23, ES7210 Pin 6
ES7210 Pin 8 -> 1uF Kondansator C1 Pin 2, 10uF Kondansator C2 Pin 2, 22uF Kondansator C3 Pin 2, 1uF Kondansator C4 Pin 2, 10uF Kondansator C5 Pin 2, 10uF Kondansator C6 Pin 2, 1uF Kondansator C7 Pin 2, 1uF Kondansator C8 Pin 2, 1uF Kondansator C9 Pin 2, 1uF Kondansator C10 Pin 2, 100nF Kondansator C11 Pin 2, 100nF Kondansator C12 Pin 2, 10uF Kondansator C13 Pin 2, USB-C Konnektor Pin 13, USB-C Konnektor Pin 14, USB-C Konnektor Pin A1B12, USB-C Konnektor Pin B1A12, LCD/Dokunmatik Konnektor Pin 14, LCD/Dokunmatik Konnektor Pin 15, LCD/Dokunmatik Konnektor Pin 16, LCD/Dokunmatik Konnektor Pin 2, Mikrofon-1 Pin 1, Mikrofon-1 Pin 2, Mikrofon-1 Pin 3, Mikrofon-2 Pin 1, Mikrofon-2 Pin 2, Mikrofon-2 Pin 3, 10k Direnc R3 Pin 2, 5.1k Direnc R4 Pin 1, 5.1k Direnc R5 Pin 2, 10k Direnc R9 Pin 2, ESP32 Pin 1, ESP32 Pin 40, ESP32 Pin 41, AXP2101 Pin 3, AXP2101 Pin 41, ES7210 Pin 1, ES7210 Pin 2, ES7210 Pin 21, ES7210 Pin 33, ES8311 Pin 10, ES8311 Pin 21, ES8311 Pin 5, NS4150 Pin 7
ES7210 Pin 9 -> ESP32 Pin 17, ES8311 Pin 6
ES8311 Pin 1 -> LCD/Dokunmatik Konnektor Pin 10, 4.7k Direnc R7 Pin 1, ESP32 Pin 22, AXP2101 Pin 40, ES7210 Pin 4
ES8311 Pin 10 -> 1uF Kondansator C1 Pin 2, 10uF Kondansator C2 Pin 2, 22uF Kondansator C3 Pin 2, 1uF Kondansator C4 Pin 2, 10uF Kondansator C5 Pin 2, 10uF Kondansator C6 Pin 2, 1uF Kondansator C7 Pin 2, 1uF Kondansator C8 Pin 2, 1uF Kondansator C9 Pin 2, 1uF Kondansator C10 Pin 2, 100nF Kondansator C11 Pin 2, 100nF Kondansator C12 Pin 2, 10uF Kondansator C13 Pin 2, USB-C Konnektor Pin 13, USB-C Konnektor Pin 14, USB-C Konnektor Pin A1B12, USB-C Konnektor Pin B1A12, LCD/Dokunmatik Konnektor Pin 14, LCD/Dokunmatik Konnektor Pin 15, LCD/Dokunmatik Konnektor Pin 16, LCD/Dokunmatik Konnektor Pin 2, Mikrofon-1 Pin 1, Mikrofon-1 Pin 2, Mikrofon-1 Pin 3, Mikrofon-2 Pin 1, Mikrofon-2 Pin 2, Mikrofon-2 Pin 3, 10k Direnc R3 Pin 2, 5.1k Direnc R4 Pin 1, 5.1k Direnc R5 Pin 2, 10k Direnc R9 Pin 2, ESP32 Pin 1, ESP32 Pin 40, ESP32 Pin 41, AXP2101 Pin 3, AXP2101 Pin 41, ES7210 Pin 1, ES7210 Pin 2, ES7210 Pin 21, ES7210 Pin 33, ES7210 Pin 8, ES8311 Pin 21, ES8311 Pin 5, NS4150 Pin 7
ES8311 Pin 11 -> 1uF Kondansator C7 Pin 1, 100nF Kondansator C12 Pin 1, AXP2101 Pin 18, ES8311 Pin 20, ES8311 Pin 3, ES8311 Pin 4
ES8311 Pin 12 -> NS4150 Pin 3
ES8311 Pin 13 -> NS4150 Pin 4
ES8311 Pin 14 -> ES8311_DACVREF Hatti (Tek Uclu)
ES8311 Pin 15 -> ES8311_ADCVREF Hatti (Tek Uclu)
ES8311 Pin 16 -> ES8311_VMID Hatti (Tek Uclu)
ES8311 Pin 17 -> NC (Baglanmayacak)
ES8311 Pin 18 -> NC (Baglanmayacak)
ES8311 Pin 19 -> LCD/Dokunmatik Konnektor Pin 11, 4.7k Direnc R6 Pin 1, ESP32 Pin 8, AXP2101 Pin 39, ES7210 Pin 3
ES8311 Pin 2 -> ESP32 Pin 9, ES7210 Pin 5
ES8311 Pin 20 -> 1uF Kondansator C7 Pin 1, 100nF Kondansator C12 Pin 1, AXP2101 Pin 18, ES8311 Pin 11, ES8311 Pin 3, ES8311 Pin 4
ES8311 Pin 21 -> 1uF Kondansator C1 Pin 2, 10uF Kondansator C2 Pin 2, 22uF Kondansator C3 Pin 2, 1uF Kondansator C4 Pin 2, 10uF Kondansator C5 Pin 2, 10uF Kondansator C6 Pin 2, 1uF Kondansator C7 Pin 2, 1uF Kondansator C8 Pin 2, 1uF Kondansator C9 Pin 2, 1uF Kondansator C10 Pin 2, 100nF Kondansator C11 Pin 2, 100nF Kondansator C12 Pin 2, 10uF Kondansator C13 Pin 2, USB-C Konnektor Pin 13, USB-C Konnektor Pin 14, USB-C Konnektor Pin A1B12, USB-C Konnektor Pin B1A12, LCD/Dokunmatik Konnektor Pin 14, LCD/Dokunmatik Konnektor Pin 15, LCD/Dokunmatik Konnektor Pin 16, LCD/Dokunmatik Konnektor Pin 2, Mikrofon-1 Pin 1, Mikrofon-1 Pin 2, Mikrofon-1 Pin 3, Mikrofon-2 Pin 1, Mikrofon-2 Pin 2, Mikrofon-2 Pin 3, 10k Direnc R3 Pin 2, 5.1k Direnc R4 Pin 1, 5.1k Direnc R5 Pin 2, 10k Direnc R9 Pin 2, ESP32 Pin 1, ESP32 Pin 40, ESP32 Pin 41, AXP2101 Pin 3, AXP2101 Pin 41, ES7210 Pin 1, ES7210 Pin 2, ES7210 Pin 21, ES7210 Pin 33, ES7210 Pin 8, ES8311 Pin 10, ES8311 Pin 5, NS4150 Pin 7
ES8311 Pin 3 -> 1uF Kondansator C7 Pin 1, 100nF Kondansator C12 Pin 1, AXP2101 Pin 18, ES8311 Pin 11, ES8311 Pin 20, ES8311 Pin 4
ES8311 Pin 4 -> 1uF Kondansator C7 Pin 1, 100nF Kondansator C12 Pin 1, AXP2101 Pin 18, ES8311 Pin 11, ES8311 Pin 20, ES8311 Pin 3
ES8311 Pin 5 -> 1uF Kondansator C1 Pin 2, 10uF Kondansator C2 Pin 2, 22uF Kondansator C3 Pin 2, 1uF Kondansator C4 Pin 2, 10uF Kondansator C5 Pin 2, 10uF Kondansator C6 Pin 2, 1uF Kondansator C7 Pin 2, 1uF Kondansator C8 Pin 2, 1uF Kondansator C9 Pin 2, 1uF Kondansator C10 Pin 2, 100nF Kondansator C11 Pin 2, 100nF Kondansator C12 Pin 2, 10uF Kondansator C13 Pin 2, USB-C Konnektor Pin 13, USB-C Konnektor Pin 14, USB-C Konnektor Pin A1B12, USB-C Konnektor Pin B1A12, LCD/Dokunmatik Konnektor Pin 14, LCD/Dokunmatik Konnektor Pin 15, LCD/Dokunmatik Konnektor Pin 16, LCD/Dokunmatik Konnektor Pin 2, Mikrofon-1 Pin 1, Mikrofon-1 Pin 2, Mikrofon-1 Pin 3, Mikrofon-2 Pin 1, Mikrofon-2 Pin 2, Mikrofon-2 Pin 3, 10k Direnc R3 Pin 2, 5.1k Direnc R4 Pin 1, 5.1k Direnc R5 Pin 2, 10k Direnc R9 Pin 2, ESP32 Pin 1, ESP32 Pin 40, ESP32 Pin 41, AXP2101 Pin 3, AXP2101 Pin 41, ES7210 Pin 1, ES7210 Pin 2, ES7210 Pin 21, ES7210 Pin 33, ES7210 Pin 8, ES8311 Pin 10, ES8311 Pin 21, NS4150 Pin 7
ES8311 Pin 6 -> ESP32 Pin 17, ES7210 Pin 9
ES8311 Pin 7 -> NC (Baglanmayacak)
ES8311 Pin 8 -> ESP32 Pin 26, ES7210 Pin 10
ES8311 Pin 9 -> ESP32 Pin 12
NS4150 Pin 1 -> 10k Direnc R3 Pin 1, ESP32 Pin 16
NS4150 Pin 2 -> NS4150_BYP Hatti (Tek Uclu)
NS4150 Pin 3 -> ES8311 Pin 12
NS4150 Pin 4 -> ES8311 Pin 13
NS4150 Pin 5 -> SPK_N Hatti (Tek Uclu)
NS4150 Pin 6 -> 1uF Kondansator C4 Pin 1, 10uF Kondansator C13 Pin 1, AXP2101 Pin 33
NS4150 Pin 7 -> 1uF Kondansator C1 Pin 2, 10uF Kondansator C2 Pin 2, 22uF Kondansator C3 Pin 2, 1uF Kondansator C4 Pin 2, 10uF Kondansator C5 Pin 2, 10uF Kondansator C6 Pin 2, 1uF Kondansator C7 Pin 2, 1uF Kondansator C8 Pin 2, 1uF Kondansator C9 Pin 2, 1uF Kondansator C10 Pin 2, 100nF Kondansator C11 Pin 2, 100nF Kondansator C12 Pin 2, 10uF Kondansator C13 Pin 2, USB-C Konnektor Pin 13, USB-C Konnektor Pin 14, USB-C Konnektor Pin A1B12, USB-C Konnektor Pin B1A12, LCD/Dokunmatik Konnektor Pin 14, LCD/Dokunmatik Konnektor Pin 15, LCD/Dokunmatik Konnektor Pin 16, LCD/Dokunmatik Konnektor Pin 2, Mikrofon-1 Pin 1, Mikrofon-1 Pin 2, Mikrofon-1 Pin 3, Mikrofon-2 Pin 1, Mikrofon-2 Pin 2, Mikrofon-2 Pin 3, 10k Direnc R3 Pin 2, 5.1k Direnc R4 Pin 1, 5.1k Direnc R5 Pin 2, 10k Direnc R9 Pin 2, ESP32 Pin 1, ESP32 Pin 40, ESP32 Pin 41, AXP2101 Pin 3, AXP2101 Pin 41, ES7210 Pin 1, ES7210 Pin 2, ES7210 Pin 21, ES7210 Pin 33, ES7210 Pin 8, ES8311 Pin 10, ES8311 Pin 21, ES8311 Pin 5
NS4150 Pin 8 -> SPK_P Hatti (Tek Uclu)

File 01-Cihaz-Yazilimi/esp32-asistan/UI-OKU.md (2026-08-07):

# Device UI

Sketch files in this folder are compiled together in Arduino IDE.

| File | Role |
|---|---|
| `esp32-asistan.ino` | Wi-Fi, audio, WebSocket, power |
| `ui_tablet.ino` | Touch UI pages |
| `wifi_local.h.example` | Copy to `wifi_local.h` for local credentials |

## Pages

Home · Ask · Calendar · Wi-Fi · Settings · Grade · Screen off

Network credentials are loaded from `wifi_local.h` (gitignored) or the on-device setup AP.

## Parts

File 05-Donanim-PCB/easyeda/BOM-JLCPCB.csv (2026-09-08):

Designator | LCSC | Value | Package | Function
U1 | C2913202 | ESP32-S3-WROOM-1-N16R8 | module | MCU
U2 | C3036461 | AXP2101 | QFN-40 | PMIC
U3 | C365743 | ES7210 | QFN-32 | Mic ADC
U4 | C962342 | ES8311 | QFN-20 | Codec
U5 | C189961 | NS4150B | SOP-8 | Speaker amp
J1 | C2765186 | TYPE-C 16PIN | SMD | USB-C
J2 | C375915 | FPC 14P 0.5mm | SMD R/A | LCD+CTP
MK1 | C111990 | SPH1642HT5H-1 | MEMS | Mic
MK2 | C111990 | SPH1642HT5H-1 | MEMS | Mic
R1 | C25744 | 10k | 0402 | BOOT pullup
R2 | C25744 | 10k | 0402 | EN pullup
R3 | C25744 | 10k | 0402 | PA_CTRL pulldown
R4 | C25911 | 5.1k | 0402 | CC1
R5 | C25911 | 5.1k | 0402 | CC2
R6 | C25905 | 4.7k | 0402 | I2C SDA
R7 | C25905 | 4.7k | 0402 | I2C SCL
R8 | C25744 | 10k | 0402 | AXP IRQ
R9 | C25744 | 10k | 0402 | TS no-NTC
C1 | C15849 | 1uF | 0402 | EN delay
C2 | C19702 | 10uF 16V | 0805 | VBUS
C3 | C45783 | 22uF 16V | 0805 | VSYS
C4 | C15849 | 1uF | 0402 | VBAT
C5 | C19702 | 10uF 16V | 0805 | 3V3
C6 | C19702 | 10uF 16V | 0805 | VBUS AXP
C7 | C15849 | 1uF | 0402 | AUD_3V3
C8 | C15849 | 1uF | 0402 | MIC_3V3
C9 | C15849 | 1uF | 0402 | LCD_3V3
C10 | C15849 | 1uF | 0402 | CTP_3V3
C11 | C14663 | 100nF | 0402 | MIC decouple
C12 | C14663 | 100nF | 0402 | AUD decouple
C13 | C19702 | 10uF 16V | 0805 | NS4150 PVDD
L1 | C167265 | 1uH 2A | inductor | DCDC1

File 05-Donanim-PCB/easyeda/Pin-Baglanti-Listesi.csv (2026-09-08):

Kaynak Pin | Net | Bagli Oldugu Pinler
C1.1 | ESP_EN | R2.1, U1.3, U2.29
C1.2 | GND | C2.2, C3.2, C4.2, C5.2, C6.2, C7.2, C8.2, C9.2, C10.2, C11.2, C12.2, C13.2, J1.13, J1.14, J1.A1B12, J1.B1A12, J2.14, J2.15, J2.16, J2.2, MK1.1, MK1.2, MK1.3, MK2.1, MK2.2, MK2.3, R3.2, R4.1, R5.2, R9.2, U1.1, U1.40, U1.41, U2.3, U2.41, U3.1, U3.2, U3.21, U3.33, U3.8, U4.10, U4.21, U4.5, U5.7
C10.1 | CTP_3V3 | U2.12
C10.2 | GND | C1.2, C2.2, C3.2, C4.2, C5.2, C6.2, C7.2, C8.2, C9.2, C11.2, C12.2, C13.2, J1.13, J1.14, J1.A1B12, J1.B1A12, J2.14, J2.15, J2.16, J2.2, MK1.1, MK1.2, MK1.3, MK2.1, MK2.2, MK2.3, R3.2, R4.1, R5.2, R9.2, U1.1, U1.40, U1.41, U2.3, U2.41, U3.1, U3.2, U3.21, U3.33, U3.8, U4.10, U4.21, U4.5, U5.7
C11.1 | MIC_3V3 | C8.1, U2.19, U3.22, U3.23, U3.6, U3.7
C11.2 | GND | C1.2, C2.2, C3.2, C4.2, C5.2, C6.2, C7.2, C8.2, C9.2, C10.2, C12.2, C13.2, J1.13, J1.14, J1.A1B12, J1.B1A12, J2.14, J2.15, J2.16, J2.2, MK1.1, MK1.2, MK1.3, MK2.1, MK2.2, MK2.3, R3.2, R4.1, R5.2, R9.2, U1.1, U1.40, U1.41, U2.3, U2.41, U3.1, U3.2, U3.21, U3.33, U3.8, U4.10, U4.21, U4.5, U5.7
C12.1 | AUD_3V3 | C7.1, U2.18, U4.11, U4.20, U4.3, U4.4
C12.2 | GND | C1.2, C2.2, C3.2, C4.2, C5.2, C6.2, C7.2, C8.2, C9.2, C10.2, C11.2, C13.2, J1.13, J1.14, J1.A1B12, J1.B1A12, J2.14, J2.15, J2.16, J2.2, MK1.1, MK1.2, MK1.3, MK2.1, MK2.2, MK2.3, R3.2, R4.1, R5.2, R9.2, U1.1, U1.40, U1.41, U2.3, U2.41, U3.1, U3.2, U3.21, U3.33, U3.8, U4.10, U4.21, U4.5, U5.7
C13.1 | VBAT | C4.1, U2.33, U5.6
C13.2 | GND | C1.2, C2.2, C3.2, C4.2, C5.2, C6.2, C7.2, C8.2, C9.2, C10.2, C11.2, C12.2, J1.13, J1.14, J1.A1B12, J1.B1A12, J2.14, J2.15, J2.16, J2.2, MK1.1, MK1.2, MK1.3, MK2.1, MK2.2, MK2.3, R3.2, R4.1, R5.2, R9.2, U1.1, U1.40, U1.41, U2.3, U2.41, U3.1, U3.2, U3.21, U3.33, U3.8, U4.10, U4.21, U4.5, U5.7
C2.1 | VBUS | C6.1, J1.A4B9, J1.B4A9, U2.37
C2.2 | GND | C1.2, C3.2, C4.2, C5.2, C6.2, C7.2, C8.2, C9.2, C10.2, C11.2, C12.2, C13.2, J1.13, J1.14, J1.A1B12, J1.B1A12, J2.14, J2.15, J2.16, J2.2, MK1.1, MK1.2, MK1.3, MK2.1, MK2.2, MK2.3, R3.2, R4.1, R5.2, R9.2, U1.1, U1.40, U1.41, U2.3, U2.41, U3.1, U3.2, U3.21, U3.33, U3.8, U4.10, U4.21, U4.5, U5.7
C3.1 | SYS | U2.13, U2.17, U2.23, U2.24, U2.34, U2.6, U2.7
C3.2 | GND | C1.2, C2.2, C4.2, C5.2, C6.2, C7.2, C8.2, C9.2, C10.2, C11.2, C12.2, C13.2, J1.13, J1.14, J1.A1B12, J1.B1A12, J2.14, J2.15, J2.16, J2.2, MK1.1, MK1.2, MK1.3, MK2.1, MK2.2, MK2.3, R3.2, R4.1, R5.2, R9.2, U1.1, U1.40, U1.41, U2.3, U2.41, U3.1, U3.2, U3.21, U3.33, U3.8, U4.10, U4.21, U4.5, U5.7
C4.1 | VBAT | C13.1, U2.33, U5.6
C4.2 | GND | C1.2, C2.2, C3.2, C5.2, C6.2, C7.2, C8.2, C9.2, C10.2, C11.2, C12.2, C13.2, J1.13, J1.14, J1.A1B12, J1.B1A12, J2.14, J2.15, J2.16, J2.2, MK1.1, MK1.2, MK1.3, MK2.1, MK2.2, MK2.3, R3.2, R4.1, R5.2, R9.2, U1.1, U1.40, U1.41, U2.3, U2.41, U3.1, U3.2, U3.21, U3.33, U3.8, U4.10, U4.21, U4.5, U5.7
C5.1 | 3V3 | L1.2, R1.2, R2.2, R6.2, R7.2, R8.2, U1.2, U2.14, U2.21
C5.2 | GND | C1.2, C2.2, C3.2, C4.2, C6.2, C7.2, C8.2, C9.2, C10.2, C11.2, C12.2, C13.2, J1.13, J1.14, J1.A1B12, J1.B1A12, J2.14, J2.15, J2.16, J2.2, MK1.1, MK1.2, MK1.3, MK2.1, MK2.2, MK2.3, R3.2, R4.1, R5.2, R9.2, U1.1, U1.40, U1.41, U2.3, U2.41, U3.1, U3.2, U3.21, U3.33, U3.8, U4.10, U4.21, U4.5, U5.7
C6.1 | VBUS | C2.1, J1.A4B9, J1.B4A9, U2.37
C6.2 | GND | C1.2, C2.2, C3.2, C4.2, C5.2, C7.2, C8.2, C9.2, C10.2, C11.2, C12.2, C13.2, J1.13, J1.14, J1.A1B12, J1.B1A12, J2.14, J2.15, J2.16, J2.2, MK1.1, MK1.2, MK1.3, MK2.1, MK2.2, MK2.3, R3.2, R4.1, R5.2, R9.2, U1.1, U1.40, U1.41, U2.3, U2.41, U3.1, U3.2, U3.21, U3.33, U3.8, U4.10, U4.21, U4.5, U5.7
C7.1 | AUD_3V3 | C12.1, U2.18, U4.11, U4.20, U4.3, U4.4
C7.2 | GND | C1.2, C2.2, C3.2, C4.2, C5.2, C6.2, C8.2, C9.2, C10.2, C11.2, C12.2, C13.2, J1.13, J1.14, J1.A1B12, J1.B1A12, J2.14, J2.15, J2.16, J2.2, MK1.1, MK1.2, MK1.3, MK2.1, MK2.2, MK2.3, R3.2, R4.1, R5.2, R9.2, U1.1, U1.40, U1.41, U2.3, U2.41, U3.1, U3.2, U3.21, U3.33, U3.8, U4.10, U4.21, U4.5, U5.7
C8.1 | MIC_3V3 | C11.1, U2.19, U3.22, U3.23, U3.6, U3.7
C8.2 | GND | C1.2, C2.2, C3.2, C4.2, C5.2, C6.2, C7.2, C9.2, C10.2, C11.2, C12.2, C13.2, J1.13, J1.14, J1.A1B12, J1.B1A12, J2.14, J2.15, J2.16, J2.2, MK1.1, MK1.2, MK1.3, MK2.1, MK2.2, MK2.3, R3.2, R4.1, R5.2, R9.2, U1.1, U1.40, U1.41, U2.3, U2.41, U3.1, U3.2, U3.21, U3.33, U3.8, U4.10, U4.21, U4.5, U5.7
C9.1 | LCD_3V3 | J2.1, U2.16
C9.2 | GND | C1.2, C2.2, C3.2, C4.2, C5.2, C6.2, C7.2, C8.2, C10.2, C11.2, C12.2, C13.2, J1.13, J1.14, J1.A1B12, J1.B1A12, J2.14, J2.15, J2.16, J2.2, MK1.1, MK1.2, MK1.3, MK2.1, MK2.2, MK2.3, R3.2, R4.1, R5.2, R9.2, U1.1, U1.40, U1.41, U2.3, U2.41, U3.1, U3.2, U3.21, U3.33, U3.8, U4.10, U4.21, U4.5, U5.7
J1.13 | GND | C1.2, C2.2, C3.2, C4.2, C5.2, C6.2, C7.2, C8.2, C9.2, C10.2, C11.2, C12.2, C13.2, J1.14, J1.A1B12, J1.B1A12, J2.14, J2.15, J2.16, J2.2, MK1.1, MK1.2, MK1.3, MK2.1, MK2.2, MK2.3, R3.2, R4.1, R5.2, R9.2, U1.1, U1.40, U1.41, U2.3, U2.41, U3.1, U3.2, U3.21, U3.33, U3.8, U4.10, U4.21, U4.5, U5.7
J1.14 | GND | C1.2, C2.2, C3.2, C4.2, C5.2, C6.2, C7.2, C8.2, C9.2, C10.2, C11.2, C12.2, C13.2, J1.13, J1.A1B12, J1.B1A12, J2.14, J2.15, J2.16, J2.2, MK1.1, MK1.2, MK1.3, MK2.1, MK2.2, MK2.3, R3.2, R4.1, R5.2, R9.2, U1.1, U1.40, U1.41, U2.3, U2.41, U3.1, U3.2, U3.21, U3.33, U3.8, U4.10, U4.21, U4.5, U5.7
J1.A1B12 | GND | C1.2, C2.2, C3.2, C4.2, C5.2, C6.2, C7.2, C8.2, C9.2, C10.2, C11.2, C12.2, C13.2, J1.13, J1.14, J1.B1A12, J2.14, J2.15, J2.16, J2.2, MK1.1, MK1.2, MK1.3, MK2.1, MK2.2, MK2.3, R3.2, R4.1, R5.2, R9.2, U1.1, U1.40, U1.41, U2.3, U2.41, U3.1, U3.2, U3.21, U3.33, U3.8, U4.10, U4.21, U4.5, U5.7
J1.A4B9 | VBUS | C2.1, C6.1, J1.B4A9, U2.37
J1.A5 | CC1 | R4.2
J1.A6 | USB_DP | J1.B6, U1.14
J1.A7 | USB_DM | J1.B7, U1.13
J1.A8 | NC__J1__A8 | -
J1.B1A12 | GND | C1.2, C2.2, C3.2, C4.2, C5.2, C6.2, C7.2, C8.2, C9.2, C10.2, C11.2, C12.2, C13.2, J1.13, J1.14, J1.A1B12, J2.14, J2.15, J2.16, J2.2, MK1.1, MK1.2, MK1.3, MK2.1, MK2.2, MK2.3, R3.2, R4.1, R5.2, R9.2, U1.1, U1.40, U1.41, U2.3, U2.41, U3.1, U3.2, U3.21, U3.33, U3.8, U4.10, U4.21, U4.5, U5.7
J1.B4A9 | VBUS | C2.1, C6.1, J1.A4B9, U2.37
J1.B5 | CC2 | R5.1
J1.B6 | USB_DP | J1.A6, U1.14
J1.B7 | USB_DM | J1.A7, U1.13
J1.B8 | NC__J1__B8 | -
J2.1 | LCD_3V3 | C9.1, U2.16
J2.10 | I2C_SCL | R7.1, U1.22, U2.40, U3.4, U4.1
J2.11 | I2C_SDA | R6.1, U1.8, U2.39, U3.3, U4.19
J2.12 | CTP_RST | U1.24
J2.13 | CTP_INT | U1.23
J2.14 | GND | C1.2, C2.2, C3.2, C4.2, C5.2, C6.2, C7.2, C8.2, C9.2, C10.2, C11.2, C12.2, C13.2, J1.13, J1.14, J1.A1B12, J1.B1A12, J2.15, J2.16, J2.2, MK1.1, MK1.2, MK1.3, MK2.1, MK2.2, MK2.3, R3.2, R4.1, R5.2, R9.2, U1.1, U1.40, U1.41, U2.3, U2.41, U3.1, U3.2, U3.21, U3.33, U3.8, U4.10, U4.21, U4.5, U5.7
J2.15 | GND | C1.2, C2.2, C3.2, C4.2, C5.2, C6.2, C7.2, C8.2, C9.2, C10.2, C11.2, C12.2, C13.2, J1.13, J1.14, J1.A1B12, J1.B1A12, J2.14, J2.16, J2.2, MK1.1, MK1.2, MK1.3, MK2.1, MK2.2, MK2.3, R3.2, R4.1, R5.2, R9.2, U1.1, U1.40, U1.41, U2.3, U2.41, U3.1, U3.2, U3.21, U3.33, U3.8, U4.10, U4.21, U4.5, U5.7
J2.16 | GND | C1.2, C2.2, C3.2, C4.2, C5.2, C6.2, C7.2, C8.2, C9.2, C10.2, C11.2, C12.2, C13.2, J1.13, J1.14, J1.A1B12, J1.B1A12, J2.14, J2.15, J2.2, MK1.1, MK1.2, MK1.3, MK2.1, MK2.2, MK2.3, R3.2, R4.1, R5.2, R9.2, U1.1, U1.40, U1.41, U2.3, U2.41, U3.1, U3.2, U3.21, U3.33, U3.8, U4.10, U4.21, U4.5, U5.7
J2.2 | GND | C1.2, C2.2, C3.2, C4.2, C5.2, C6.2, C7.2, C8.2, C9.2, C10.2, C11.2, C12.2, C13.2, J1.13, J1.14, J1.A1B12, J1.B1A12, J2.14, J2.15, J2.16, MK1.1, MK1.2, MK1.3, MK2.1, MK2.2, MK2.3, R3.2, R4.1, R5.2, R9.2, U1.1, U1.40, U1.41, U2.3, U2.41, U3.1, U3.2, U3.21, U3.33, U3.8, U4.10, U4.21, U4.5, U5.7
J2.3 | TFT_CS | U1.5
J2.4 | TFT_RST | U1.31
J2.5 | TFT_DC | U1.4
J2.6 | TFT_MOSI | U1.7
J2.7 | TFT_SCLK | U1.6
J2.8 | TFT_BL | U1.33
J2.9 | NC__J2__9 | -
L1.1 | DCDC1_LX | U2.22
L1.2 | 3V3 | C5.1, R1.2, R2.2, R6.2, R7.2, R8.2, U1.2, U2.14, U2.21
MK1.1 | GND | C1.2, C2.2, C3.2, C4.2, C5.2, C6.2, C7.2, C8.2, C9.2, C10.2, C11.2, C12.2, C13.2, J1.13, J1.14, J1.A1B12, J1.B1A12, J2.14, J2.15, J2.16, J2.2, MK1.2, MK1.3, MK2.1, MK2.2, MK2.3, R3.2, R4.1, R5.2, R9.2, U1.1, U1.40, U1.41, U2.3, U2.41, U3.1, U3.2, U3.21, U3.33, U3.8, U4.10, U4.21, U4.5, U5.7
MK1.2 | GND | C1.2, C2.2, C3.2, C4.2, C5.2, C6.2, C7.2, C8.2, C9.2, C10.2, C11.2, C12.2, C13.2, J1.13, J1.14, J1.A1B12, J1.B1A12, J2.14, J2.15, J2.16, J2.2, MK1.1, MK1.3, MK2.1, MK2.2, MK2.3, R3.2, R4.1, R5.2, R9.2, U1.1, U1.40, U1.41, U2.3, U2.41, U3.1, U3.2, U3.21, U3.33, U3.8, U4.10, U4.21, U4.5, U5.7
MK1.3 | GND | C1.2, C2.2, C3.2, C4.2, C5.2, C6.2, C7.2, C8.2, C9.2, C10.2, C11.2, C12.2, C13.2, J1.13, J1.14, J1.A1B12, J1.B1A12, J2.14, J2.15, J2.16, J2.2, MK1.1, MK1.2, MK2.1, MK2.2, MK2.3, R3.2, R4.1, R5.2, R9.2, U1.1, U1.40, U1.41, U2.3, U2.41, U3.1, U3.2, U3.21, U3.33, U3.8, U4.10, U4.21, U4.5, U5.7
MK1.4 | MIC1P | U3.16
MK1.5 | NC__MK1__5 | -
MK1.6 | MICBIAS | MK2.6, U3.24
MK2.1 | GND | C1.2, C2.2, C3.2, C4.2, C5.2, C6.2, C7.2, C8.2, C9.2, C10.2, C11.2, C12.2, C13.2, J1.13, J1.14, J1.A1B12, J1.B1A12, J2.14, J2.15, J2.16, J2.2, MK1.1, MK1.2, MK1.3, MK2.2, MK2.3, R3.2, R4.1, R5.2, R9.2, U1.1, U1.40, U1.41, U2.3, U2.41, U3.1, U3.2, U3.21, U3.33, U3.8, U4.10, U4.21, U4.5, U5.7
MK2.2 | GND | C1.2, C2.2, C3.2, C4.2, C5.2, C6.2, C7.2, C8.2, C9.2, C10.2, C11.2, C12.2, C13.2, J1.13, J1.14, J1.A1B12, J1.B1A12, J2.14, J2.15, J2.16, J2.2, MK1.1, MK1.2, MK1.3, MK2.1, MK2.3, R3.2, R4.1, R5.2, R9.2, U1.1, U1.40, U1.41, U2.3, U2.41, U3.1, U3.2, U3.21, U3.33, U3.8, U4.10, U4.21, U4.5, U5.7
MK2.3 | GND | C1.2, C2.2, C3.2, C4.2, C5.2, C6.2, C7.2, C8.2, C9.2, C10.2, C11.2, C12.2, C13.2, J1.13, J1.14, J1.A1B12, J1.B1A12, J2.14, J2.15, J2.16, J2.2, MK1.1, MK1.2, MK1.3, MK2.1, MK2.2, R3.2, R4.1, R5.2, R9.2, U1.1, U1.40, U1.41, U2.3, U2.41, U3.1, U3.2, U3.21, U3.33, U3.8, U4.10, U4.21, U4.5, U5.7
MK2.4 | MIC2P | U3.19
MK2.5 | NC__MK2__5 | -
MK2.6 | MICBIAS | MK1.6, U3.24
R1.1 | BOOT | U1.27
R1.2 | 3V3 | C5.1, L1.2, R2.2, R6.2, R7.2, R8.2, U1.2, U2.14, U2.21
R2.1 | ESP_EN | C1.1, U1.3, U2.29
R2.2 | 3V3 | C5.1, L1.2, R1.2, R6.2, R7.2, R8.2, U1.2, U2.14, U2.21
R3.1 | PA_CTRL | U1.16, U5.1
R3.2 | GND | C1.2, C2.2, C3.2, C4.2, C5.2, C6.2, C7.2, C8.2, C9.2, C10.2, C11.2, C12.2, C13.2, J1.13, J1.14, J1.A1B12, J1.B1A12, J2.14, J2.15, J2.16, J2.2, MK1.1, MK1.2, MK1.3, MK2.1, MK2.2, MK2.3, R4.1, R5.2, R9.2, U1.1, U1.40, U1.41, U2.3, U2.41, U3.1, U3.2, U3.21, U3.33, U3.8, U4.10, U4.21, U4.5, U5.7
R4.1 | GND | C1.2, C2.2, C3.2, C4.2, C5.2, C6.2, C7.2, C8.2, C9.2, C10.2, C11.2, C12.2, C13.2, J1.13, J1.14, J1.A1B12, J1.B1A12, J2.14, J2.15, J2.16, J2.2, MK1.1, MK1.2, MK1.3, MK2.1, MK2.2, MK2.3, R3.2, R5.2, R9.2, U1.1, U1.40, U1.41, U2.3, U2.41, U3.1, U3.2, U3.21, U3.33, U3.8, U4.10, U4.21, U4.5, U5.7
R4.2 | CC1 | J1.A5
R5.1 | CC2 | J1.B5
R5.2 | GND | C1.2, C2.2, C3.2, C4.2, C5.2, C6.2, C7.2, C8.2, C9.2, C10.2, C11.2, C12.2, C13.2, J1.13, J1.14, J1.A1B12, J1.B1A12, J2.14, J2.15, J2.16, J2.2, MK1.1, MK1.2, MK1.3, MK2.1, MK2.2, MK2.3, R3.2, R4.1, R9.2, U1.1, U1.40, U1.41, U2.3, U2.41, U3.1, U3.2, U3.21, U3.33, U3.8, U4.10, U4.21, U4.5, U5.7
R6.1 | I2C_SDA | J2.11, U1.8, U2.39, U3.3, U4.19
R6.2 | 3V3 | C5.1, L1.2, R1.2, R2.2, R7.2, R8.2, U1.2, U2.14, U2.21
R7.1 | I2C_SCL | J2.10, U1.22, U2.40, U3.4, U4.1
R7.2 | 3V3 | C5.1, L1.2, R1.2, R2.2, R6.2, R8.2, U1.2, U2.14, U2.21
R8.1 | AXP_IRQ | U1.25, U2.38
R8.2 | 3V3 | C5.1, L1.2, R1.2, R2.2, R6.2, R7.2, U1.2, U2.14, U2.21
R9.1 | BAT_NTC | U2.31
R9.2 | GND | C1.2, C2.2, C3.2, C4.2, C5.2, C6.2, C7.2, C8.2, C9.2, C10.2, C11.2, C12.2, C13.2, J1.13, J1.14, J1.A1B12, J1.B1A12, J2.14, J2.15, J2.16, J2.2, MK1.1, MK1.2, MK1.3, MK2.1, MK2.2, MK2.3, R3.2, R4.1, R5.2, U1.1, U1.40, U1.41, U2.3, U2.41, U3.1, U3.2, U3.21, U3.33, U3.8, U4.10, U4.21, U4.5, U5.7
U1.1 | GND | C1.2, C2.2, C3.2, C4.2, C5.2, C6.2, C7.2, C8.2, C9.2, C10.2, C11.2, C12.2, C13.2, J1.13, J1.14, J1.A1B12, J1.B1A12, J2.14, J2.15, J2.16, J2.2, MK1.1, MK1.2, MK1.3, MK2.1, MK2.2, MK2.3, R3.2, R4.1, R5.2, R9.2, U1.40, U1.41, U2.3, U2.41, U3.1, U3.2, U3.21, U3.33, U3.8, U4.10, U4.21, U4.5, U5.7
U1.10 | NC__U1__10 | -
U1.11 | NC__U1__11 | -
U1.12 | I2S_DOUT | U4.9
U1.13 | USB_DM | J1.A7, J1.B7
U1.14 | USB_DP | J1.A6, J1.B6
U1.15 | NC__U1__15 | -
U1.16 | PA_CTRL | R3.1, U5.1
U1.17 | I2S_BCLK | U3.9, U4.6
U1.18 | I2S_DIN | U3.11
U1.19 | NC__U1__19 | -
U1.2 | 3V3 | C5.1, L1.2, R1.2, R2.2, R6.2, R7.2, R8.2, U2.14, U2.21
U1.20 | NC__U1__20 | -
U1.21 | NC__U1__21 | -
U1.22 | I2C_SCL | J2.10, R7.1, U2.40, U3.4, U4.1
U1.23 | CTP_INT | J2.13
U1.24 | CTP_RST | J2.12
U1.25 | AXP_IRQ | R8.1, U2.38
U1.26 | I2S_LRCK | U3.10, U4.8
U1.27 | BOOT | R1.1
U1.28 | NC__U1__28 | -
U1.29 | NC__U1__29 | -
U1.3 | ESP_EN | C1.1, R2.1, U2.29
U1.30 | NC__U1__30 | -
U1.31 | TFT_RST | J2.4
U1.32 | NC__U1__32 | -
U1.33 | TFT_BL | J2.8
U1.34 | NC__U1__34 | -
U1.35 | NC__U1__35 | -
U1.36 | UART_RXD | -
U1.37 | UART_TXD | -
U1.38 | NC__U1__38 | -
U1.39 | NC__U1__39 | -
U1.4 | TFT_DC | J2.5
U1.40 | GND | C1.2, C2.2, C3.2, C4.2, C5.2, C6.2, C7.2, C8.2, C9.2, C10.2, C11.2, C12.2, C13.2, J1.13, J1.14, J1.A1B12, J1.B1A12, J2.14, J2.15, J2.16, J2.2, MK1.1, MK1.2, MK1.3, MK2.1, MK2.2, MK2.3, R3.2, R4.1, R5.2, R9.2, U1.1, U1.41, U2.3, U2.41, U3.1, U3.2, U3.21, U3.33, U3.8, U4.10, U4.21, U4.5, U5.7
U1.41 | GND | C1.2, C2.2, C3.2, C4.2, C5.2, C6.2, C7.2, C8.2, C9.2, C10.2, C11.2, C12.2, C13.2, J1.13, J1.14, J1.A1B12, J1.B1A12, J2.14, J2.15, J2.16, J2.2, MK1.1, MK1.2, MK1.3, MK2.1, MK2.2, MK2.3, R3.2, R4.1, R5.2, R9.2, U1.1, U1.40, U2.3, U2.41, U3.1, U3.2, U3.21, U3.33, U3.8, U4.10, U4.21, U4.5, U5.7
U1.5 | TFT_CS | J2.3
U1.6 | TFT_SCLK | J2.7
U1.7 | TFT_MOSI | J2.6
U1.8 | I2C_SDA | J2.11, R6.1, U2.39, U3.3, U4.19
U1.9 | I2S_MCLK | U3.5, U4.2
U2.1 | NC__U2__1 | -
U2.10 | NC__U2__10 | -
U2.11 | NC__U2__11 | -
U2.12 | CTP_3V3 | C10.1
U2.13 | SYS | C3.1, U2.17, U2.23, U2.24, U2.34, U2.6, U2.7
U2.14 | 3V3 | C5.1, L1.2, R1.2, R2.2, R6.2, R7.2, R8.2, U1.2, U2.21
U2.15 | NC__U2__15 | -
U2.16 | LCD_3V3 | C9.1, J2.1
U2.17 | SYS | C3.1, U2.13, U2.23, U2.24, U2.34, U2.6, U2.7
U2.18 | AUD_3V3 | C7.1, C12.1, U4.11, U4.20, U4.3, U4.4
U2.19 | MIC_3V3 | C8.1, C11.1, U3.22, U3.23, U3.6, U3.7
U2.2 | AXP_VREF | -
U2.20 | NC__U2__20 | -
U2.21 | 3V3 | C5.1, L1.2, R1.2, R2.2, R6.2, R7.2, R8.2, U1.2, U2.14
U2.22 | DCDC1_LX | L1.1
U2.23 | SYS | C3.1, U2.13, U2.17, U2.24, U2.34, U2.6, U2.7
U2.24 | SYS | C3.1, U2.13, U2.17, U2.23, U2.34, U2.6, U2.7
U2.25 | NC__U2__25 | -
U2.26 | NC__U2__26 | -
U2.27 | NC__U2__27 | -
U2.28 | NC__U2__28 | -
U2.29 | ESP_EN | C1.1, R2.1, U1.3
U2.3 | GND | C1.2, C2.2, C3.2, C4.2, C5.2, C6.2, C7.2, C8.2, C9.2, C10.2, C11.2, C12.2, C13.2, J1.13, J1.14, J1.A1B12, J1.B1A12, J2.14, J2.15, J2.16, J2.2, MK1.1, MK1.2, MK1.3, MK2.1, MK2.2, MK2.3, R3.2, R4.1, R5.2, R9.2, U1.1, U1.40, U1.41, U2.41, U3.1, U3.2, U3.21, U3.33, U3.8, U4.10, U4.21, U4.5, U5.7
U2.30 | PWRON | -
U2.31 | BAT_NTC | R9.1
U2.32 | NC__U2__32 | -
U2.33 | VBAT | C4.1, C13.1, U5.6
U2.34 | SYS | C3.1, U2.13, U2.17, U2.23, U2.24, U2.6, U2.7
U2.35 | NC__U2__35 | -
U2.36 | AXP_VMID | -
U2.37 | VBUS | C2.1, C6.1, J1.A4B9, J1.B4A9
U2.38 | AXP_IRQ | R8.1, U1.25
U2.39 | I2C_SDA | J2.11, R6.1, U1.8, U3.3, U4.19
U2.4 | NC__U2__4 | -
U2.40 | I2C_SCL | J2.10, R7.1, U1.22, U3.4, U4.1
U2.41 | GND | C1.2, C2.2, C3.2, C4.2, C5.2, C6.2, C7.2, C8.2, C9.2, C10.2, C11.2, C12.2, C13.2, J1.13, J1.14, J1.A1B12, J1.B1A12, J2.14, J2.15, J2.16, J2.2, MK1.1, MK1.2, MK1.3, MK2.1, MK2.2, MK2.3, R3.2, R4.1, R5.2, R9.2, U1.1, U1.40, U1.41, U2.3, U3.1, U3.2, U3.21, U3.33, U3.8, U4.10, U4.21, U4.5, U5.7
U2.5 | NC__U2__5 | -
U2.6 | SYS | C3.1, U2.13, U2.17, U2.23, U2.24, U2.34, U2.7
U2.7 | SYS | C3.1, U2.13, U2.17, U2.23, U2.24, U2.34, U2.6
U2.8 | NC__U2__8 | -
U2.9 | NC__U2__9 | -
U3.1 | GND | C1.2, C2.2, C3.2, C4.2, C5.2, C6.2, C7.2, C8.2, C9.2, C10.2, C11.2, C12.2, C13.2, J1.13, J1.14, J1.A1B12, J1.B1A12, J2.14, J2.15, J2.16, J2.2, MK1.1, MK1.2, MK1.3, MK2.1, MK2.2, MK2.3, R3.2, R4.1, R5.2, R9.2, U1.1, U1.40, U1.41, U2.3, U2.41, U3.2, U3.21, U3.33, U3.8, U4.10, U4.21, U4.5, U5.7
U3.10 | I2S_LRCK | U1.26, U4.8
U3.11 | I2S_DIN | U1.18
U3.12 | NC__U3__12 | -
U3.13 | NC__U3__13 | -
U3.14 | NC__U3__14 | -
U3.15 | MIC1N | -
U3.16 | MIC1P | MK1.4
U3.17 | ES7210_REFP12 | -
U3.18 | ES7210_REFQ12 | -
U3.19 | MIC2P | MK2.4
U3.2 | GND | C1.2, C2.2, C3.2, C4.2, C5.2, C6.2, C7.2, C8.2, C9.2, C10.2, C11.2, C12.2, C13.2, J1.13, J1.14, J1.A1B12, J1.B1A12, J2.14, J2.15, J2.16, J2.2, MK1.1, MK1.2, MK1.3, MK2.1, MK2.2, MK2.3, R3.2, R4.1, R5.2, R9.2, U1.1, U1.40, U1.41, U2.3, U2.41, U3.1, U3.21, U3.33, U3.8, U4.10, U4.21, U4.5, U5.7
U3.20 | MIC2N | -
U3.21 | GND | C1.2, C2.2, C3.2, C4.2, C5.2, C6.2, C7.2, C8.2, C9.2, C10.2, C11.2, C12.2, C13.2, J1.13, J1.14, J1.A1B12, J1.B1A12, J2.14, J2.15, J2.16, J2.2, MK1.1, MK1.2, MK1.3, MK2.1, MK2.2, MK2.3, R3.2, R4.1, R5.2, R9.2, U1.1, U1.40, U1.41, U2.3, U2.41, U3.1, U3.2, U3.33, U3.8, U4.10, U4.21, U4.5, U5.7
U3.22 | MIC_3V3 | C8.1, C11.1, U2.19, U3.23, U3.6, U3.7
U3.23 | MIC_3V3 | C8.1, C11.1, U2.19, U3.22, U3.6, U3.7
U3.24 | MICBIAS | MK1.6, MK2.6
U3.25 | ES7210_REFQM | -
U3.26 | NC__U3__26 | -
U3.27 | NC__U3__27 | -
U3.28 | NC__U3__28 | -
U3.29 | NC__U3__29 | -
U3.3 | I2C_SDA | J2.11, R6.1, U1.8, U2.39, U4.19
U3.30 | NC__U3__30 | -
U3.31 | AEC_P | -
U3.32 | AEC_N | -
U3.33 | GND | C1.2, C2.2, C3.2, C4.2, C5.2, C6.2, C7.2, C8.2, C9.2, C10.2, C11.2, C12.2, C13.2, J1.13, J1.14, J1.A1B12, J1.B1A12, J2.14, J2.15, J2.16, J2.2, MK1.1, MK1.2, MK1.3, MK2.1, MK2.2, MK2.3, R3.2, R4.1, R5.2, R9.2, U1.1, U1.40, U1.41, U2.3, U2.41, U3.1, U3.2, U3.21, U3.8, U4.10, U4.21, U4.5, U5.7
U3.4 | I2C_SCL | J2.10, R7.1, U1.22, U2.40, U4.1
U3.5 | I2S_MCLK | U1.9, U4.2
U3.6 | MIC_3V3 | C8.1, C11.1, U2.19, U3.22, U3.23, U3.7
U3.7 | MIC_3V3 | C8.1, C11.1, U2.19, U3.22, U3.23, U3.6
U3.8 | GND | C1.2, C2.2, C3.2, C4.2, C5.2, C6.2, C7.2, C8.2, C9.2, C10.2, C11.2, C12.2, C13.2, J1.13, J1.14, J1.A1B12, J1.B1A12, J2.14, J2.15, J2.16, J2.2, MK1.1, MK1.2, MK1.3, MK2.1, MK2.2, MK2.3, R3.2, R4.1, R5.2, R9.2, U1.1, U1.40, U1.41, U2.3, U2.41, U3.1, U3.2, U3.21, U3.33, U4.10, U4.21, U4.5, U5.7
U3.9 | I2S_BCLK | U1.17, U4.6
U4.1 | I2C_SCL | J2.10, R7.1, U1.22, U2.40, U3.4
U4.10 | GND | C1.2, C2.2, C3.2, C4.2, C5.2, C6.2, C7.2, C8.2, C9.2, C10.2, C11.2, C12.2, C13.2, J1.13, J1.14, J1.A1B12, J1.B1A12, J2.14, J2.15, J2.16, J2.2, MK1.1, MK1.2, MK1.3, MK2.1, MK2.2, MK2.3, R3.2, R4.1, R5.2, R9.2, U1.1, U1.40, U1.41, U2.3, U2.41, U3.1, U3.2, U3.21, U3.33, U3.8, U4.21, U4.5, U5.7
U4.11 | AUD_3V3 | C7.1, C12.1, U2.18, U4.20, U4.3, U4.4
U4.12 | DAC_P | U5.3
U4.13 | DAC_N | U5.4
U4.14 | ES8311_DACVREF | -
U4.15 | ES8311_ADCVREF | -
U4.16 | ES8311_VMID | -
U4.17 | NC__U4__17 | -
U4.18 | NC__U4__18 | -
U4.19 | I2C_SDA | J2.11, R6.1, U1.8, U2.39, U3.3
U4.2 | I2S_MCLK | U1.9, U3.5
U4.20 | AUD_3V3 | C7.1, C12.1, U2.18, U4.11, U4.3, U4.4
U4.21 | GND | C1.2, C2.2, C3.2, C4.2, C5.2, C6.2, C7.2, C8.2, C9.2, C10.2, C11.2, C12.2, C13.2, J1.13, J1.14, J1.A1B12, J1.B1A12, J2.14, J2.15, J2.16, J2.2, MK1.1, MK1.2, MK1.3, MK2.1, MK2.2, MK2.3, R3.2, R4.1, R5.2, R9.2, U1.1, U1.40, U1.41, U2.3, U2.41, U3.1, U3.2, U3.21, U3.33, U3.8, U4.10, U4.5, U5.7
U4.3 | AUD_3V3 | C7.1, C12.1, U2.18, U4.11, U4.20, U4.4
U4.4 | AUD_3V3 | C7.1, C12.1, U2.18, U4.11, U4.20, U4.3
U4.5 | GND | C1.2, C2.2, C3.2, C4.2, C5.2, C6.2, C7.2, C8.2, C9.2, C10.2, C11.2, C12.2, C13.2, J1.13, J1.14, J1.A1B12, J1.B1A12, J2.14, J2.15, J2.16, J2.2, MK1.1, MK1.2, MK1.3, MK2.1, MK2.2, MK2.3, R3.2, R4.1, R5.2, R9.2, U1.1, U1.40, U1.41, U2.3, U2.41, U3.1, U3.2, U3.21, U3.33, U3.8, U4.10, U4.21, U5.7
U4.6 | I2S_BCLK | U1.17, U3.9
U4.7 | NC__U4__7 | -
U4.8 | I2S_LRCK | U1.26, U3.10
U4.9 | I2S_DOUT | U1.12
U5.1 | PA_CTRL | R3.1, U1.16
U5.2 | NS4150_BYP | -
U5.3 | DAC_P | U4.12
U5.4 | DAC_N | U4.13
U5.5 | SPK_N | -
U5.6 | VBAT | C4.1, C13.1, U2.33
U5.7 | GND | C1.2, C2.2, C3.2, C4.2, C5.2, C6.2, C7.2, C8.2, C9.2, C10.2, C11.2, C12.2, C13.2, J1.13, J1.14, J1.A1B12, J1.B1A12, J2.14, J2.15, J2.16, J2.2, MK1.1, MK1.2, MK1.3, MK2.1, MK2.2, MK2.3, R3.2, R4.1, R5.2, R9.2, U1.1, U1.40, U1.41, U2.3, U2.41, U3.1, U3.2, U3.21, U3.33, U3.8, U4.10, U4.21, U4.5
U5.8 | SPK_P | -

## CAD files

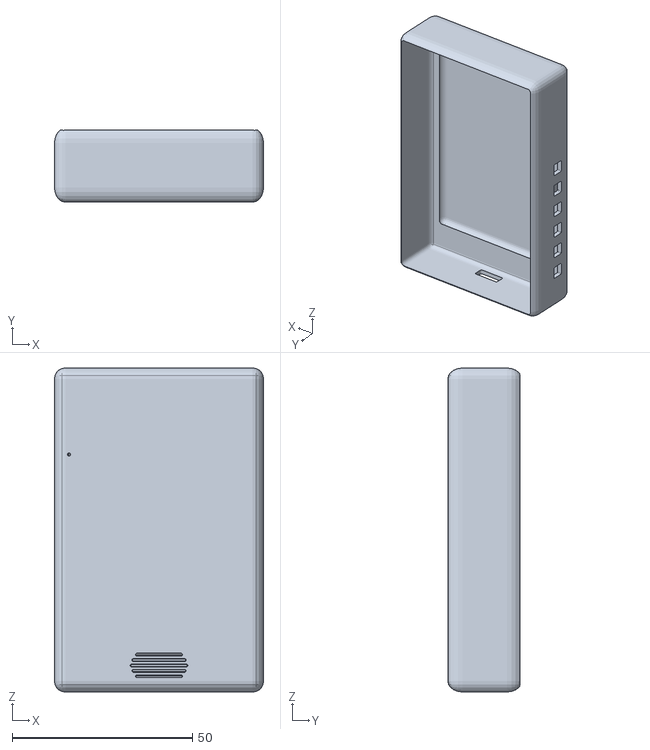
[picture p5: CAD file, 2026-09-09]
06-Kasa-3D/on_govde.stl
58.0 x 20.1 x 90.0

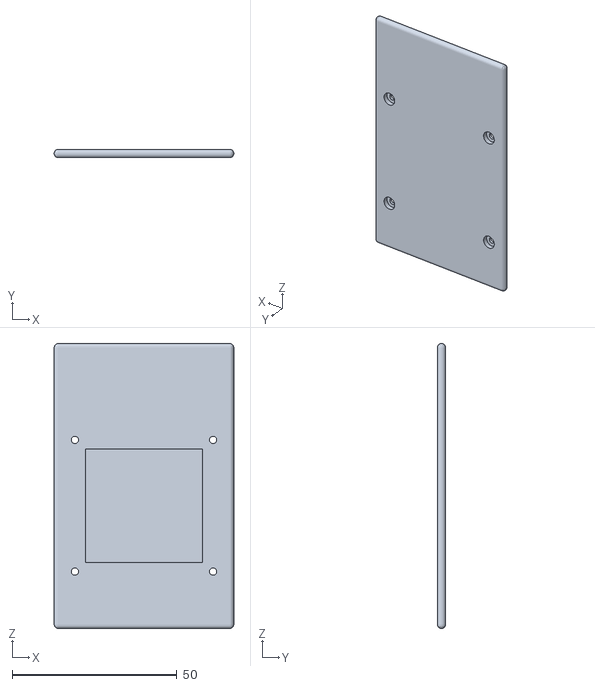
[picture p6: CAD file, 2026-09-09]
06-Kasa-3D/arka_kapak.stl
54.6 x 2.50 x 86.6

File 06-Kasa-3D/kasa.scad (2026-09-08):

// MEB AI Asistan — kasa (mm). OpenSCAD: F6 → STL.

$fn = 28;

W = 58;
L = 90;
T = 20;
WALL = 1.4;
FRONT_T = 5.0;          // 1.4 duvar + 3.6 ekran cebi
BACK_T = T - FRONT_T;   // 15.0
LIP = 1.0;
R_CORNER = 3.0;

PCB_W = 50;
PCB_L = 72;
PCB_X = (W - PCB_W) / 2;  // 4.0
PCB_Y = WALL;             // 1.4
POST_H = 6.5;

SCR_W = 50.4;
SCR_L = 69.6;
SCR_D = 3.6;
SCR_X = PCB_X + (PCB_W - SCR_W) / 2;
SCR_Y = PCB_Y + (PCB_L - SCR_L) / 2;

WIN_W = 44.5;
WIN_L = 59.0;
WIN_X = SCR_X + (SCR_W - WIN_W) / 2;
WIN_Y = SCR_Y + (SCR_L - WIN_L) / 2;

HOLES = [[4, 10], [46, 10], [4, 50], [46, 50]];
HOLE_R = 1.1;     // M2
POST_R = 2.2;

BAT_W = 35;
BAT_L = 34;
BAT_H = 6.5;
BAT_X = PCB_X + (PCB_W - BAT_W) / 2;
BAT_Y = PCB_Y + 13;

USB_W = 9.2;
USB_H = 3.4;
USB_Z = 4.2;
USB_X = PCB_X + 25 - USB_W / 2;

module round_rect(w, l, h, r) {
    hull() {
        translate([r, r, 0]) cylinder(h=h, r=r);
        translate([w - r, r, 0]) cylinder(h=h, r=r);
        translate([r, l - r, 0]) cylinder(h=h, r=r);
        translate([w - r, l - r, 0]) cylinder(h=h, r=r);
    }
}

module on_kapak() {
    difference() {
        union() {
            round_rect(W, L, FRONT_T, R_CORNER);
            // arka yariya giren dudak
            translate([WALL - LIP, WALL - LIP, FRONT_T])
                round_rect(W - 2 * (WALL - LIP), L - 2 * (WALL - LIP), LIP, R_CORNER - 0.4);
        }
        // ekran penceresi
        translate([WIN_X, WIN_Y, -0.2])
            cube([WIN_W, WIN_L, FRONT_T + LIP + 0.4]);
        // ekran cebi (cam oturur)
        translate([SCR_X, SCR_Y, WALL])
            cube([SCR_W, SCR_L, SCR_D + LIP + 0.2]);
        // mikrofon delikleri (alt cin, ekranin alti)
        for (dx = [-6, 6])
            translate([W / 2 + dx, 5.5, -0.2])
                cylinder(h=FRONT_T + 0.4, r=0.5);
    }
}

module arka_kapak() {
    difference() {
        round_rect(W, L, BACK_T, R_CORNER);
        // ic bosluk
        translate([WALL, WALL, WALL])
            cube([W - 2 * WALL, L - 2 * WALL, BACK_T]);
        // Type-C
        translate([USB_X, -0.2, USB_Z])
            cube([USB_W, WALL + 0.4, USB_H]);
        // hoparlor izgara
        for (i = [0:4], j = [0:2])
            translate([W - 10 + i * 1.6, L - 14 + j * 1.6, -0.2])
                cylinder(h=WALL + 0.4, r=0.55);
        // anten: ust icte vida yok (delikler zaten keep-out disinda)
    }
    // M2 direkler
    for (h = HOLES) {
        translate([PCB_X + h[0], PCB_Y + h[1], WALL])
            difference() {
                cylinder(h=POST_H, r=POST_R);
                translate([0, 0, -0.1]) cylinder(h=POST_H + 0.2, r=HOLE_R);
            }
    }
    // batarya cebi duvarlari (ESP32 altinda degil)
    translate([BAT_X - 0.8, BAT_Y - 0.8, WALL])
        difference() {
            cube([BAT_W + 1.6, BAT_L + 1.6, BAT_H]);
            translate([0.8, 0.8, 0.2]) cube([BAT_W, BAT_L, BAT_H]);
        }
}

// Onizleme: yan yana
on_kapak();
translate([W + 8, 0, 0]) arka_kapak();

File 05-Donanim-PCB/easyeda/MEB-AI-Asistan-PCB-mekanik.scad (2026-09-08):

// MEB AI Asistan — kasa hizalama (mm)
// Orijin: kart sol-alt, Type-C kenarı = Y0, ekran yüzü = +Z
// Kart: 50 x 72 x 1.6   M2 NPTH Ø2.2

$fn = 48;

pcb_w = 50;
pcb_h = 72;
pcb_t = 1.6;

holes = [[4,10],[46,10],[4,50],[46,50]];
hole_d = 2.2;

// ESP32-S3-WROOM-1  (Top / ekran yüzü)
esp_w = 18;
esp_d = 25.5;
esp_t = 3.1;
esp_cx = 25;
esp_cy = 54;

// USB-C gövde (alt orta, karttan 1 mm taşar)
usb_w = 9.2;
usb_d = 7.5;
usb_t = 3.4;
usb_overhang = 1.0;

// J2 FPC 14P — ekran tarafı, sol
j2_w = 8;
j2_d = 12;
j2_t = 1.5;
j2_cx = 8;
j2_cy = 44;

// MK1 / MK2 (ekran yüzü, sağ alt)
mk_w = 3.5;
mk_d = 2.7;
mk_t = 1.1;

module board() {
    difference() {
        translate([0, 0, 0]) cube([pcb_w, pcb_h, pcb_t]);
        for (p = holes)
            translate([p[0], p[1], -1])
                cylinder(h = pcb_t + 2, d = hole_d);
    }
}

module esp32() {
    translate([esp_cx - esp_w/2, esp_cy - esp_d/2, pcb_t])
        cube([esp_w, esp_d, esp_t]);
}

module usbc() {
    translate([25 - usb_w/2, -usb_overhang, pcb_t])
        cube([usb_w, usb_d, usb_t]);
}

module j2() {
    translate([j2_cx - j2_w/2, j2_cy - j2_d/2, pcb_t])
        cube([j2_w, j2_d, j2_t]);
}

module mic(cx, cy) {
    translate([cx - mk_w/2, cy - mk_d/2, pcb_t])
        cube([mk_w, mk_d, mk_t]);
}

board();
esp32();
usbc();
j2();
mic(42, 16); // MK1
mic(36, 16); // MK2

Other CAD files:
06-Kasa-3D/final.blend

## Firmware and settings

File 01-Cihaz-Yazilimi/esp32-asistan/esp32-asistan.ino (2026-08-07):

#include <WiFi.h>
#include <WiFiUdp.h>
#include <WebSocketsClient.h>
#include <WebServer.h>
#include <DNSServer.h>
#include <Preferences.h>
#include <Wire.h>
#include <string.h>
#include <time.h>
#include <sys/time.h>
#include <stdlib.h>
#include "XPowersLib.h"
#include <driver/i2s.h>
#include "HWCDC.h"
#include <Arduino_GFX_Library.h>

#if __has_include("wifi_local.h")
#include "wifi_local.h"
#endif

#ifndef WIFI_SSID
#define WIFI_SSID ""
#endif
#ifndef WIFI_PASS
#define WIFI_PASS ""
#endif
#ifndef WS_HOST
#define WS_HOST "192.168.1.100"
#endif
#ifndef WS_PORT
#define WS_PORT 8001
#endif
#ifndef AP_SSID
#define AP_SSID "MEB-AI-Setup"
#endif
#ifndef AP_PASS
#define AP_PASS "setup1234"
#endif

#define BLACK   0x0000
#define WHITE   0xFFFF
#define GREEN   0x07E0
#define CYAN    0x07FF
#define ORANGE  0xFD20
#define BG_DEEP   0x0169
#define BG_MID    0x12B4
#define ACCENT    0x07FD
#define AMBER     0xFDC0
#define MINT      0x2FEA
#define MUTED     0x7BEF
#define CHIP_ON   0x07F9
#define CHIP_OFF  0x2945

enum DeviceState {
  STATE_UNKNOWN,
  STATE_IDLE,
  STATE_LISTENING,
  STATE_THINKING,
  STATE_SPEAKING
};

HWCDC USBSerial;
XPowersAXP2101 PMIC;
WebSocketsClient webSocket;
Preferences prefs;
WebServer configServer(80);
DNSServer dnsServer;
WiFiUDP g_discoverUdp;

char wifi_ssid[48] = WIFI_SSID;
char wifi_pass[64] = WIFI_PASS;
char ws_server[48] = WS_HOST;
int  ws_port = WS_PORT;
const char* ws_path = "/ws/device";
bool g_configMode = false;

#ifndef LANG_START_ENGLISH
#define LANG_START_ENGLISH 0
#endif
#define BTN_BOOT 0
#if LANG_START_ENGLISH
char dil_ayari[16] = "English";
#else
char dil_ayari[16] = "Turkce";
#endif

#define I2C_SDA_PIN   15
#define I2C_SCL_PIN   14
#define I2S_MCLK_PIN  16
#define I2S_BCLK_PIN  9
#define I2S_LRCK_PIN  45
#define I2S_DOUT_PIN  8
#define I2S_DIN_PIN   10
#define PA_PIN        46
#define ES8311_ADDR   0x18
#define ES7210_ADDR   0x40
#define SAMPLE_RATE   16000
#define I2S_READ_BYTES 1024

#define TFT_CS    5
#define TFT_DC    4
#define TFT_RST   38
#define TFT_BL    40
#define TFT_MOSI  7
#define TFT_SCLK  6

Arduino_DataBus *bus = new Arduino_ESP32SPI(TFT_DC, TFT_CS, TFT_SCLK, TFT_MOSI, GFX_NOT_DEFINED);
Arduino_GFX *gfx = new Arduino_ST7789(bus, TFT_RST, 0, true, 240, 284, 0, 0);

DeviceState currentState = STATE_UNKNOWN;

#define AEC_REF_DELAY      240
#define AEC_SUBTRACT_GAIN  0.20f
#define PLAY_RING_SIZE     (160 * 1024)
#define PLAY_PREBUFFER     (20 * 1024)
#define CST816_ADDR        0x15
#define UI_PAGE_HOME       0
#define UI_PAGE_ASK        1
#define UI_PAGE_CALENDAR   2
#define UI_PAGE_WIFI       3
#define UI_PAGE_SETTINGS   4
#define UI_PAGE_SINIF      5
#define UI_PAGE_EKRAN      6
#define UI_PAGE_COUNT      7

volatile bool g_playbackActive     = false;
volatile bool g_micTransmitAllowed = true;
volatile bool g_serverThinking     = false;
volatile bool g_streamComplete     = false;
volatile uint32_t g_micCooldownUntil = 0;
volatile uint16_t g_micLevel       = 0;
bool g_timeSynced = false;
bool g_screenOff = false;
bool g_listenPaused = false;
bool g_textAskPending = false;
bool g_askShowAnswer = false;
int8_t g_uiPage = UI_PAGE_HOME;
int8_t g_bgTheme = 0;
int8_t g_uiBand = 2;
int8_t g_sinifNo = 10;
uint16_t g_bgColor = BG_DEEP;
char g_lastSoru[180] = "";
char g_lastCevap[420] = "";
char g_ogrenciAd[48] = "";

uint8_t playRing[PLAY_RING_SIZE];
volatile size_t playHead = 0;
volatile size_t playTail = 0;

int16_t g_refRing[AEC_REF_DELAY];
size_t  g_refRingIdx = 0;

void setDeviceState(DeviceState newState);
void startSpeaking();
void stopSpeaking();
void handleServerText(const char* text);
static void speakerEnable(bool on);
static bool dilIngilizceMi();
static void sendDilConfig();
static void setDilEnglish(bool en);

static void refRingPush(int16_t sample) {
  g_refRing[g_refRingIdx] = sample;
  g_refRingIdx = (g_refRingIdx + 1) % AEC_REF_DELAY;
}

static int16_t refRingGetDelayed(size_t delaySamples) {
  size_t idx = (g_refRingIdx + AEC_REF_DELAY - delaySamples) % AEC_REF_DELAY;
  return g_refRing[idx];
}

static int16_t applySoftwareAEC(int16_t micSample) {
  int32_t ref = (int32_t)(refRingGetDelayed(AEC_REF_DELAY / 2) * AEC_SUBTRACT_GAIN);
  int32_t out = (int32_t)micSample - ref;
  if (out > 32767)  out = 32767;
  if (out < -32768) out = -32768;
  return (int16_t)out;
}

static void flushMicDma() {
  int16_t dump[256];
  size_t bytes_read = 0;
  for (int i = 0; i < 6; i++) {
    i2s_read(I2S_NUM_0, dump, sizeof(dump), &bytes_read, 0);
  }
}

static void speakerEnable(bool on) {
  digitalWrite(PA_PIN, on ? HIGH : LOW);
}

static size_t playRingFree() {
  size_t h = playHead;
  size_t t = playTail;
  if (h >= t) return PLAY_RING_SIZE - 1 - (h - t);
  return t - h - 1;
}

static size_t playRingUsed() {
  size_t h = playHead;
  size_t t = playTail;
  if (h >= t) return h - t;
  return PLAY_RING_SIZE - (t - h);
}

static void playRingClear() {
  playHead = 0;
  playTail = 0;
}

static void enqueuePlayback(const uint8_t* data, size_t len) {
  if (len & 1) len--;
  size_t i = 0;
  while (i + 1 < len) {
    if (playRingFree() < 2) break;
    playRing[playHead] = data[i++];
    playHead = (playHead + 1) % PLAY_RING_SIZE;
    playRing[playHead] = data[i++];
    playHead = (playHead + 1) % PLAY_RING_SIZE;
  }
}

static bool dilIngilizceMi() {
  return (dil_ayari[0] == 'E' || dil_ayari[0] == 'e');
}

void drawFace(DeviceState state);
void pollDilControls();
void animateFaceIfNeeded();
void ui_on_pmic_key();
void reconnectWebSocket();

void saveNetPrefsPublic(const String& ssid, const String& pass, const String& host, int port);
void startConfigPortalPublic();
void loadNetPrefs();
void saveBgTheme(int8_t idx);
void syncNtpTime();
bool dilIngilizceMiPublic();
void processPlayback();
void webSocketEvent(WStype_t type, uint8_t* payload, size_t length);
static bool applyHostAndConnect(const String& host, int port) {
  if (host.length() < 7) return false;
  USBSerial.printf("[DISCOVER] sunucu = %s:%d\n", host.c_str(), port);
  saveNetPrefsPublic(String(wifi_ssid), String(wifi_pass), host, port);
  reconnectWebSocket();
  return true;
}

static bool probeHost8001(const IPAddress& ip) {
  WiFiClient c;
  c.setTimeout(150);
  if (!c.connect(ip, 8001, 180)) return false;
  c.stop();
  return true;
}

static bool scanSubnetForBackend() {
  IPAddress ip = WiFi.localIP();
  USBSerial.printf("[DISCOVER] subnet taraniyor %d.%d.%d.x:8001\n", ip[0], ip[1], ip[2]);
  const int prefer[] = {1, 101, 102, 108, 100, 137, 43, 50, 20, 10};
  for (unsigned k = 0; k < sizeof(prefer) / sizeof(prefer[0]); k++) {
    int i = prefer[k];
    if (i == ip[3]) continue;
    IPAddress t(ip[0], ip[1], ip[2], (uint8_t)i);
    if (probeHost8001(t)) {
      return applyHostAndConnect(t.toString(), 8001);
    }
    yield();
  }
  for (int i = 1; i < 255; i++) {
    if (i == ip[3]) continue;
    bool skip = false;
    for (unsigned k = 0; k < sizeof(prefer) / sizeof(prefer[0]); k++) {
      if (prefer[k] == i) { skip = true; break; }
    }
    if (skip) continue;
    IPAddress t(ip[0], ip[1], ip[2], (uint8_t)i);
    if (probeHost8001(t)) {
      return applyHostAndConnect(t.toString(), 8001);
    }
    if ((i % 20) == 0) yield();
  }
  return false;
}

bool discoverServerPublic() {
  if (WiFi.status() != WL_CONNECTED) {
    USBSerial.println("[DISCOVER] Once WiFi baglan");
    return false;
  }

  {
    IPAddress saved;
    if (saved.fromString(String(ws_server)) && probeHost8001(saved)) {
      return applyHostAndConnect(String(ws_server), ws_port > 0 ? ws_port : 8001);
    }
  }

  g_discoverUdp.stop();
  if (g_discoverUdp.begin(0)) {
    const char* req = "MEB_AI_DISCOVER";
    g_discoverUdp.beginPacket(IPAddress(255, 255, 255, 255), 8002);
    g_discoverUdp.write((const uint8_t*)req, strlen(req));
    g_discoverUdp.endPacket();
    g_discoverUdp.beginPacket(WiFi.broadcastIP(), 8002);
    g_discoverUdp.write((const uint8_t*)req, strlen(req));
    g_discoverUdp.endPacket();
    uint32_t t0 = millis();
    char buf[72];
    while (millis() - t0 < 2000) {
      int n = g_discoverUdp.parsePacket();
      if (n > 0) {
        int len = g_discoverUdp.read(buf, sizeof(buf) - 1);
        if (len < 0) len = 0;
        buf[len] = 0;
        if (strncmp(buf, "MEB_AI_HOST:", 12) == 0) {
          char* host = buf + 12;
          char* colon = strchr(host, ':');
          int port = 8001;
          if (colon) {
            *colon = 0;
            int p = atoi(colon + 1);
            if (p > 0) port = p;
          }
          g_discoverUdp.stop();
          return applyHostAndConnect(String(host), port);
        }
      }
      delay(20);
      yield();
    }
    g_discoverUdp.stop();
  }

  IPAddress gw = WiFi.gatewayIP();
  if (gw != IPAddress(0, 0, 0, 0) && gw != WiFi.localIP() && probeHost8001(gw)) {
    return applyHostAndConnect(gw.toString(), 8001);
  }

  if (probeHost8001(IPAddress(192, 168, 137, 1))) {
    return applyHostAndConnect("192.168.137.1", 8001);
  }

  if (scanSubnetForBackend()) return true;

  USBSerial.println("[DISCOVER] bulunamadi — PC ayni WiFi/hotspot + BASLAT?");
  return false;
}
static void sendDilConfig() {
  if (!webSocket.isConnected()) return;
  String cfg = String("{\"type\":\"config\",\"dil\":\"") + dil_ayari + "\"}";
  webSocket.sendTXT(cfg);
}

void sendListenConfig(bool on) {
  if (!webSocket.isConnected()) return;
  webSocket.sendTXT(on ? "{\"type\":\"config\",\"listen\":true}"
                       : "{\"type\":\"config\",\"listen\":false}");
  USBSerial.printf("[MIC] dinleme=%s\n", on ? "ACIK" : "KAPALI");
}

void sendSinifConfig(int sinif) {
  if (sinif < 0) sinif = 0;
  if (sinif > 12) sinif = 12;
  g_sinifNo = (int8_t)sinif;
  if (sinif == 0) g_uiBand = 2;
  else if (sinif <= 4) g_uiBand = 0;
  else if (sinif <= 8) g_uiBand = 1;
  else g_uiBand = 2;
  if (!webSocket.isConnected()) return;
  char cfg[48];
  snprintf(cfg, sizeof(cfg), "{\"type\":\"config\",\"sinif\":%d}", sinif);
  webSocket.sendTXT(cfg);
  USBSerial.printf("[UI] sinif gonderildi: %d\n", sinif);
}

void setDilEnglishPublic(bool en) {
  strncpy(dil_ayari, en ? "English" : "Turkce", sizeof(dil_ayari) - 1);
  dil_ayari[sizeof(dil_ayari) - 1] = 0;
  sendDilConfig();
  drawFace(currentState == STATE_UNKNOWN ? STATE_IDLE : currentState);
}

static void setDilEnglish(bool en) { setDilEnglishPublic(en); }

bool readTouchXYPublic(int16_t &x, int16_t &y) {
  Wire.beginTransmission(CST816_ADDR);
  Wire.write(0x02);
  if (Wire.endTransmission(false) != 0) return false;
  if (Wire.requestFrom((uint8_t)CST816_ADDR, (uint8_t)5) < 5) return false;
  uint8_t fingers = Wire.read();
  uint8_t xh = Wire.read();
  uint8_t xl = Wire.read();
  uint8_t yh = Wire.read();
  uint8_t yl = Wire.read();
  if (fingers == 0 || fingers > 5) return false;
  x = (int16_t)(((xh & 0x0F) << 8) | xl);
  y = (int16_t)(((yh & 0x0F) << 8) | yl);
  return (x >= 0 && y >= 0 && x < 240 && y < 284);
}

void reconnectWebSocket() {
  webSocket.disconnect();
  webSocket.begin(ws_server, ws_port, ws_path);
  webSocket.onEvent(webSocketEvent);
  webSocket.setReconnectInterval(3000);
}

static void lcd_init() {
  gfx->begin();
  gfx->fillScreen(BLACK);
  pinMode(TFT_BL, OUTPUT);
  digitalWrite(TFT_BL, HIGH);
  setDeviceState(STATE_IDLE);
  USBSerial.println("[OK] LCD baslatildi");
}

void setDeviceState(DeviceState newState) {
  if (currentState == newState) return;
  currentState = newState;
  drawFace(newState);
}

void startSpeaking() {
  g_playbackActive = true;
  g_micTransmitAllowed = false;
  speakerEnable(true);
  setDeviceState(STATE_SPEAKING);
}
void stopSpeaking() {
  g_playbackActive = false;
  g_streamComplete = false;
  playRingClear();
  speakerEnable(false);
  g_micCooldownUntil = millis() + 1200;
  g_micTransmitAllowed = false;
  if (webSocket.isConnected()) setDeviceState(STATE_LISTENING);
  else setDeviceState(STATE_IDLE);
}

void processPlayback() {
  size_t used = playRingUsed();
  static uint32_t emptySince = 0;
  if (used < 4) {
    if (g_playbackActive && g_streamComplete) {
      if (!emptySince) emptySince = millis();
      if (millis() - emptySince > 80) { emptySince = 0; stopSpeaking(); }
    }
    return;
  }
  emptySince = 0;
  if (!g_playbackActive) {
    if (used < PLAY_PREBUFFER && !g_streamComplete) return;
    startSpeaking();
  }
  int16_t stereo[512];
  size_t frames = min((size_t)256, used / 2);
  for (size_t i = 0; i < frames; i++) {
    uint8_t b0 = playRing[playTail]; playTail = (playTail + 1) % PLAY_RING_SIZE;
    uint8_t b1 = playRing[playTail]; playTail = (playTail + 1) % PLAY_RING_SIZE;
    int16_t s = (int16_t)(b0 | ((uint16_t)b1 << 8));
    stereo[i * 2] = s; stereo[i * 2 + 1] = s;
    refRingPush(s);
  }
  size_t need = frames * 2 * sizeof(int16_t);
  size_t written = 0;
  uint8_t* ptr = (uint8_t*)stereo;
  while (written < need) {
    size_t w = 0;
    if (i2s_write(I2S_NUM_0, ptr + written, need - written, &w, pdMS_TO_TICKS(80)) != ESP_OK || !w) break;
    written += w;
  }
}

static bool jsonContains(const char* text, const char* key, const char* value) {
  char needle[96];
  snprintf(needle, sizeof(needle), "\"%s\":\"%s\"", key, value);
  if (strstr(text, needle)) return true;
  snprintf(needle, sizeof(needle), "\"%s\": \"%s\"", key, value);
  return strstr(text, needle) != nullptr;
}
static bool jsonExtractString(const char* text, const char* key, char* out, size_t outLen) {
  char needle[48];
  snprintf(needle, sizeof(needle), "\"%s\":\"", key);
  const char* p = strstr(text, needle);
  if (!p) return false;
  p += strlen(needle);
  size_t i = 0;
  while (*p && *p != '"' && i + 1 < outLen) {
    if (*p == '\\' && p[1]) { p++; out[i++] = (*p == 'n') ? ' ' : *p; p++; continue; }
    out[i++] = *p++;
  }
  out[i] = 0;
  return i > 0;
}

static void trUtf8ToLcd(const char* in, char* out, size_t outLen) {
  if (!out || outLen == 0) return;
  size_t j = 0;
  const unsigned char* p = (const unsigned char*)in;
  while (p && *p && j + 1 < outLen) {
    if (*p < 0x80) {
      out[j++] = (char)*p++;
      continue;
    }
    if (p[1] == 0) break;
    unsigned char c0 = p[0], c1 = p[1];
    char rep = 0;
    if (c0 == 0xC3) {
      if (c1 == 0xA7 || c1 == 0x87) rep = (c1 == 0x87) ? 'C' : 'c';
      else if (c1 == 0xB6 || c1 == 0x96) rep = (c1 == 0x96) ? 'O' : 'o';
      else if (c1 == 0xBC || c1 == 0x9C) rep = (c1 == 0x9C) ? 'U' : 'u';
    } else if (c0 == 0xC4) {
      if (c1 == 0x9F || c1 == 0x9E) rep = (c1 == 0x9E) ? 'G' : 'g';
      else if (c1 == 0xB1) rep = 'i';
      else if (c1 == 0xB0) rep = 'I';
    } else if (c0 == 0xC5) {
      if (c1 == 0x9F || c1 == 0x9E) rep = (c1 == 0x9E) ? 'S' : 's';
    }
    if (rep) {
      out[j++] = rep;
      p += 2;
      continue;
    }
    if ((c0 & 0xE0) == 0xC0) p += 2;
    else if ((c0 & 0xF0) == 0xE0) p += 3;
    else if ((c0 & 0xF8) == 0xF0) p += 4;
    else p++;
  }
  out[j] = 0;
}
static bool jsonExtractLong(const char* text, const char* key, long* out) {
  char needle[40];
  snprintf(needle, sizeof(needle), "\"%s\":", key);
  const char* p = strstr(text, needle);
  if (!p) return false;
  p += strlen(needle);
  while (*p == ' ') p++;
  char* end = nullptr;
  long v = strtol(p, &end, 10);
  if (end == p) return false;
  *out = v;
  return true;
}

void syncNtpTime() {
  configTime(3 * 3600, 0, "pool.ntp.org", "time.google.com", "time.cloudflare.com");
  struct tm ti;
  if (getLocalTime(&ti, 5000)) { g_timeSynced = true; USBSerial.println("[TIME] NTP OK"); }
  else USBSerial.println("[TIME] NTP yok");
}

static void applyServerEpoch(long epochUtc) {
  if (epochUtc < 1700000000L) return;
  setenv("TZ", "UTC-3", 1); tzset();
  struct timeval tv{}; tv.tv_sec = (time_t)epochUtc; tv.tv_usec = 0;
  settimeofday(&tv, nullptr);
  g_timeSynced = true;
  drawFace(currentState == STATE_UNKNOWN ? STATE_IDLE : currentState);
}

void handleServerText(const char* text) {
  if (!g_playbackActive && currentState != STATE_SPEAKING) USBSerial.printf("[WS] %s\n", text);
  if (jsonContains(text, "type", "student") || jsonContains(text, "type", "settings")) {
    long band = g_uiBand, sinif = g_sinifNo;
    if (jsonExtractLong(text, "sinif", &sinif) && sinif >= 0 && sinif <= 12) {
      g_sinifNo = (int8_t)sinif;
      if (sinif == 0) g_uiBand = 2;
      else if (sinif <= 4) g_uiBand = 0;
      else if (sinif <= 8) g_uiBand = 1;
      else g_uiBand = 2;
    } else if (jsonExtractLong(text, "band", &band) && band >= 0 && band <= 2) {
      g_uiBand = (int8_t)band;
    }
    char ad[48];
    if (jsonExtractString(text, "ad", ad, sizeof(ad))) {
      trUtf8ToLcd(ad, g_ogrenciAd, sizeof(g_ogrenciAd));
    }
    USBSerial.printf("[UI] ogrenci sinif=%d band=%d ad=%s\n", (int)g_sinifNo, (int)g_uiBand, g_ogrenciAd);
    if (!g_screenOff) drawFace(currentState == STATE_UNKNOWN ? STATE_IDLE : currentState);
    return;
  }
  if (jsonContains(text, "type", "time")) {
    long epoch = 0;
    if (jsonExtractLong(text, "epoch", &epoch)) applyServerEpoch(epoch);
    return;
  }
  if (jsonContains(text, "type", "done") || jsonContains(text, "type", "error")) {
    g_streamComplete = true;
    char soruBuf[180], cevapBuf[420];
    if (jsonExtractString(text, "soru", soruBuf, sizeof(soruBuf))) strncpy(g_lastSoru, soruBuf, sizeof(g_lastSoru)-1);
    if (jsonExtractString(text, "cevap", cevapBuf, sizeof(cevapBuf))) strncpy(g_lastCevap, cevapBuf, sizeof(g_lastCevap)-1);
    if (g_textAskPending || jsonContains(text, "mod", "yazi")) {
      g_textAskPending = false; g_askShowAnswer = true; g_uiPage = UI_PAGE_ASK;
      drawFace(STATE_IDLE);
    }
    return;
  }
  if (jsonContains(text, "type", "status")) {
    if (jsonContains(text, "value", "speaking")) {
      g_serverThinking = false; g_micTransmitAllowed = false; g_streamComplete = false;
      setDeviceState(STATE_SPEAKING);
    } else if (jsonContains(text, "value", "thinking")) {
      if (g_playbackActive || currentState == STATE_SPEAKING) return;
      g_serverThinking = true; g_micTransmitAllowed = false; g_streamComplete = false;
      setDeviceState(STATE_THINKING);
    } else if (jsonContains(text, "value", "listening")) {
      g_serverThinking = false;
      if (g_listenPaused || g_screenOff) return;
      if (!g_playbackActive && currentState != STATE_SPEAKING) {
        setDeviceState(STATE_LISTENING);
        if (g_micCooldownUntil < millis()) {
          g_micCooldownUntil = millis() + 500;
        }
      }
    } else if (jsonContains(text, "value", "idle")) {
      g_serverThinking = false;
      if (!g_playbackActive) setDeviceState(STATE_IDLE);
    }
  }
}
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
void loop() {
  PMIC.getIrqStatus();
  if (PMIC.isPekeyShortPressIrq() || PMIC.isPekeyLongPressIrq()) {
    ui_on_pmic_key();
    PMIC.clearIrqStatus();
  } else {
    PMIC.clearIrqStatus();
  }

  if (g_configMode) {
    dnsServer.processNextRequest();
    configServer.handleClient();
    pollDilControls();
    return;
  }

  if (g_screenOff || g_listenPaused) {
    webSocket.loop();
    pollDilControls();
    delay(30);
    return;
  }

  bool audioPath = g_playbackActive || currentState == STATE_SPEAKING || playRingUsed() > 0;
  if (audioPath) {
    for (int i = 0; i < 16; i++) {
      webSocket.loop();
      processPlayback();
    }
    int16_t trash[128];
    size_t br = 0;
    i2s_read(I2S_NUM_0, trash, sizeof(trash), &br, 0);
    return;
  }

  pollDilControls();
  animateFaceIfNeeded();
  webSocket.loop();
  processPlayback();

  if (!webSocket.isConnected()) {
    setDeviceState(STATE_IDLE);
    static uint32_t lastDiscover = 0;
    if (WiFi.status() == WL_CONNECTED && millis() - lastDiscover > 12000) {
      lastDiscover = millis();
      USBSerial.println("[DISCOVER] tekrar deneniyor...");
      discoverServerPublic();
    }
    return;
  }

  static uint32_t thinkingSince = 0;
  if (currentState == STATE_THINKING || g_serverThinking) {
    if (!thinkingSince) thinkingSince = millis();
    if (millis() - thinkingSince > 50000UL) {
      USBSerial.println("[UI] thinking timeout → listening");
      g_serverThinking = false;
      g_micTransmitAllowed = true;
      g_micCooldownUntil = millis() + 400;
      thinkingSince = 0;
      setDeviceState(STATE_LISTENING);
    }
  } else {
    thinkingSince = 0;
  }

  if (!g_playbackActive && !g_serverThinking && currentState != STATE_SPEAKING) {
    if (currentState != STATE_THINKING) {
      setDeviceState(STATE_LISTENING);
    }
  }

  if (g_micCooldownUntil != 0 && (int32_t)(millis() - g_micCooldownUntil) >= 0) {
    g_micCooldownUntil = 0;
    if (!g_playbackActive && !g_serverThinking) {
      g_micTransmitAllowed = true;
      flushMicDma();
    }
  }

  if (!g_micTransmitAllowed || g_serverThinking || g_micCooldownUntil != 0) {
    int16_t trash[128];
    size_t bytes_read = 0;
    i2s_read(I2S_NUM_0, trash, sizeof(trash), &bytes_read, 0);
    return;
  }

  static int16_t stereo_buf[I2S_READ_BYTES / 2];
  static int16_t mono_buf[I2S_READ_BYTES / 4];
  size_t bytes_read = 0;

  esp_err_t err = i2s_read(I2S_NUM_0, stereo_buf, sizeof(stereo_buf), &bytes_read, pdMS_TO_TICKS(30));
  if (err != ESP_OK || bytes_read == 0) return;

  size_t samples = bytes_read / sizeof(int16_t);
  size_t frames  = samples / 2;
  uint32_t absAcc = 0;
  for (size_t i = 0; i < frames; i++) {
    int32_t s = applySoftwareAEC(stereo_buf[i * 2]);
    s = (s * 3);
    if (s > 32767) s = 32767;
    if (s < -32768) s = -32768;
    mono_buf[i] = (int16_t)s;
    int32_t a = s;
    if (a < 0) a = -a;
    absAcc += (uint32_t)a;
  }
  if (frames > 0) {
    uint32_t avg = absAcc / (uint32_t)frames;
    uint16_t lvl = (uint16_t)(avg / 60);
    if (lvl > 100) lvl = 100;
    g_micLevel = lvl;
  }

  webSocket.sendBIN((uint8_t*)mono_buf, frames * sizeof(int16_t));
}

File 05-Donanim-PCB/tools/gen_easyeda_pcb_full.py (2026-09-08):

#!/usr/bin/env python3
"""Aşama 2 PCB: kilitli yerleşim + USB şarj yolları + yerleşim haritası PNG."""
from __future__ import annotations

import json
import sys
from pathlib import Path

sys.path.insert(0, str(Path(__file__).resolve().parent))

import gen_easyeda_sch as sch
import pcb_lib as pcb
import route_pcb
from PIL import Image, ImageDraw, ImageFont

USB_NET = {
    "A1B12": "GND",
    "B1A12": "GND",
    "A4B9": "VBUS",
    "B4A9": "VBUS",
    "A5": "CC1",
    "B5": "CC2",
    "A6": "USB_DP",
    "B6": "USB_DP",
    "A7": "USB_DM",
    "B7": "USB_DM",
    "13": "GND",
    "14": "GND",
}

# (ref, name, x_mm, y_mm, w, h)  origin = bottom-left, Type-C = alt
MAP = [
    ("J1", "USB-C", 16.0, 0.0, 18.0, 8.0),
    ("U1", "ESP32-S3 anten ustte", 16.0, 41.25, 18.0, 25.5),
    ("U2", "AXP2101 guc", 22.0, 30.0, 8.0, 8.0),
    ("U3", "ES7210 mik ADC", 36.5, 30.5, 7.0, 7.0),
    ("U4", "ES8311 codec", 11.0, 31.0, 6.0, 6.0),
    ("U5", "NS4150 hoparlor", 4.0, 16.0, 8.0, 8.0),
    ("MK1", "MEMS mik 1", 39.5, 14.0, 5.0, 4.0),
    ("MK2", "MEMS mik 2", 33.5, 14.0, 5.0, 4.0),
    ("L1", "1uH DCDC1", 11.0, 39.5, 6.0, 5.0),
    ("J2", "FPC 14P ekran", 3.0, 41.0, 10.0, 6.0),
    ("R4", "5.1k CC1", 20.5, 7.0, 2.5, 2.0),
    ("R5", "5.1k CC2", 27.0, 7.0, 2.5, 2.0),
    ("pasifler", "R/C seridi", 8.0, 25.0, 38.0, 4.0),
]


def pin_nets(product: dict, rules: list) -> dict[str, str]:
    nets: dict[str, str] = {}
    for raw in product["result"]["dataStr"].get("shape") or []:
        pin = sch.parse_pin(raw)
        if not pin:
            continue
        net = sch.match_net(pin["name"], rules)
        if net == "NC":
            nets[pin["num"]] = ""
        elif net:
            nets[pin["num"]] = net
    return nets


def draw_preview(path: Path) -> None:
    scale = 16
    pad = 40
    img = Image.new("RGB", (50 * scale + pad * 2, 72 * scale + pad * 2), (18, 18, 22))
    d = ImageDraw.Draw(img)

    def xy(x: float, y: float) -> tuple[int, int]:
        # SVG-like: y=0 at bottom of board -> image y grows down from top
        return int(pad + x * scale), int(pad + (72 - y) * scale)

    # board
    d.rectangle([xy(0, 72), xy(50, 0)], outline=(180, 80, 220), width=3)
    d.rectangle([xy(0, 72), xy(50, 57)], outline=(255, 200, 60), width=2)
    d.text((pad + 8, pad + 8), "anten keep-out 15 mm", fill=(255, 200, 60))
    for hx, hy in [(4, 10), (46, 10), (4, 50), (46, 50)]:
        cx, cy = xy(hx, hy)
        r = int(1.6 * scale)
        d.ellipse([cx - r, cy - r, cx + r, cy + r], outline=(160, 160, 160), width=2)
    colors = {
        "U1": (80, 180, 255),
        "U2": (255, 140, 80),
        "U3": (120, 220, 140),
        "U4": (180, 140, 255),
        "U5": (255, 90, 90),
        "J1": (255, 220, 80),
        "MK1": (80, 220, 220),
        "MK2": (80, 220, 220),
        "L1": (200, 200, 200),
        "J2": (255, 180, 120),
    }
    try:
        font = ImageFont.truetype("arial.ttf", 14)
        font_s = ImageFont.truetype("arial.ttf", 12)
    except OSError:
        font = ImageFont.load_default()
        font_s = font
    for ref, name, x, y, w, h in MAP:
        p0, p1 = xy(x, y + h), xy(x + w, y)
        col = colors.get(ref, (200, 200, 200))
        d.rectangle([p0, p1], outline=col, width=2)
        d.text((p0[0] + 4, p0[1] + 4), f"{ref} {name}", fill=col, font=font_s)
    # passives as dots
    d.text((pad, img.height - 28), "MEB AI Asistan  PCB 50x72 mm  Aşama 2 yerleşim", fill=(220, 220, 220), font=font)
    img.save(path)


def main() -> None:
    F = pcb.fetch_product
    usbc, esp, axp = F("C2765186"), F("C2913202"), F("C3036461")
    es7210, es8311, ns4150, mic = F("C365743"), F("C962342"), F("C189961"), F("C111990")
    r10k, r51k, r47k = F("C25744"), F("C25911"), F("C25905")
    c1u, c10u, c100n, c22u, l1p = F("C15849"), F("C19702"), F("C14663"), F("C45783"), F("C167265")
    fpc = F("C375915")
    J2_NET = {
        "1": "LCD_3V3",
        "2": "GND",
        "3": "TFT_CS",
        "4": "TFT_RST",
        "5": "TFT_DC",
        "6": "TFT_MOSI",
        "7": "TFT_SCLK",
        "8": "TFT_BL",
        "9": "",
        "10": "I2C_SCL",
        "11": "I2C_SDA",
        "12": "CTP_RST",
        "13": "CTP_INT",
        "14": "GND",
        "15": "GND",
        "16": "GND",
    }

    libs: list[str] = []
    all_pads: list[dict] = []

    def add(prod, ref, lcsc, xmm, ymm, nets, rot=0):
        lib, pads = pcb.place_lib(prod, ref, lcsc, *pcb.mm(xmm, ymm), nets, rot=rot)
        libs.append(lib)
        all_pads.extend(pcb.pads_from_lib(lib))
        return pads

    jp = add(usbc, "J1", "C2765186", 25.0, 3.0, USB_NET)
    ep = add(esp, "U1", "C2913202", 25.0, 54.0, pin_nets(esp, sch.ESP32_RULES), rot=180)
    add(axp, "U2", "C3036461", 24.0, 34.0, pin_nets(axp, sch.AXP_RULES))
    add(es7210, "U3", "C365743", 10.0, 34.0, pin_nets(es7210, sch.ES7210_RULES))
    add(es8311, "U4", "C962342", 36.0, 34.0, pin_nets(es8311, sch.ES8311_RULES))
    add(ns4150, "U5", "C189961", 42.0, 20.0, pin_nets(ns4150, sch.NS4150_RULES))
    add(mic, "MK1", "C111990", 8.0, 16.0, {"1": "GND", "2": "GND", "3": "GND", "4": "MIC1P", "6": "MICBIAS"}, rot=90)
    add(mic, "MK2", "C111990", 14.0, 16.0, {"1": "GND", "2": "GND", "3": "GND", "4": "MIC2P", "6": "MICBIAS"}, rot=90)
    add(l1p, "L1", "C167265", 14.0, 42.0, {"1": "DCDC1_LX", "2": "3V3"})
    add(fpc, "J2", "C375915", 42.0, 44.0, J2_NET, rot=90)

    def r(prod, ref, lcsc, xmm, ymm, n1, n2):
        return add(prod, ref, lcsc, xmm, ymm, {"1": n1, "2": n2})

    # USB CC + VBUS cap
    r4p = r(r51k, "R4", "C25911", 22.0, 8.0, "GND", "CC1")
    r5p = r(r51k, "R5", "C25911", 28.0, 8.0, "CC2", "GND")
    c2p = r(c10u, "C2", "C19702", 25.0, 11.0, "VBUS", "GND")
    # ESP
    r(r10k, "R1", "C25744", 36.0, 48.0, "BOOT", "3V3")
    r(r10k, "R2", "C25744", 36.0, 50.5, "ESP_EN", "3V3")
    r(c1u, "C1", "C15849", 36.0, 45.5, "ESP_EN", "GND")
    # AXP / rails
    r(c22u, "C3", "C45783", 24.0, 28.0, "SYS", "GND")
    r(c1u, "C4", "C15849", 27.5, 28.0, "VBAT", "GND")
    r(c10u, "C5", "C19702", 31.0, 28.0, "3V3", "GND")
    r(c10u, "C6", "C19702", 20.5, 28.0, "VBUS", "GND")
    r(r10k, "R8", "C25744", 18.0, 28.0, "AXP_IRQ", "3V3")
    r(r10k, "R9", "C25744", 15.5, 28.0, "BAT_NTC", "GND")
    r(r47k, "R6", "C25905", 13.0, 28.0, "I2C_SDA", "3V3")
    r(r47k, "R7", "C25905", 10.5, 28.0, "I2C_SCL", "3V3")
    # audio
    r(c1u, "C7", "C15849", 36.0, 26.0, "AUD_3V3", "GND")
    r(c100n, "C12", "C14663", 39.0, 26.0, "AUD_3V3", "GND")
    r(c1u, "C8", "C15849", 8.0, 26.0, "MIC_3V3", "GND")
    r(c100n, "C11", "C14663", 11.0, 26.0, "MIC_3V3", "GND")
    r(c10u, "C13", "C19702", 42.0, 26.0, "VBAT", "GND")
    r(r10k, "R3", "C25744", 42.0, 13.0, "PA_CTRL", "GND")
    r(c1u, "C9", "C15849", 40.0, 42.0, "LCD_3V3", "GND")
    r(c1u, "C10", "C15849", 43.0, 42.0, "CTP_3V3", "GND")
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

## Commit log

2026-08-23 Device photos in README
2026-09-08 50x72 mm PCB and case
    [BOM-JLCPCB.csv, MEB-AI-Asistan-PCB-mekanik.scad, Pin-Baglanti-Listesi.csv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]
2026-09-08 Ordered Gerbers
    [arka_kapak.stl, kasa.scad, on_kapak.stl]
2026-09-08 Hardware notes
    [kasa.scad]
2026-09-08 Board placement preview removed
2026-09-08 Custom ESP32-S3 board in README
2026-09-08 Custom board, not a kit
2026-09-08 PCB complete in README
2026-09-09 Case STLs and PCB photo
    [arka_kapak.stl, final.blend, on_govde.stl]
